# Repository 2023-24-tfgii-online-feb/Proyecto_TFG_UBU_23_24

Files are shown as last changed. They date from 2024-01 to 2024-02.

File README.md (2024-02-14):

# Diseño de un sistema económico IoT de monitorización de invernaderos de cannabis medicinal.

En este proyecto, se diseña e implementa un prototipo de sistema IoT de bajo coste que monitoriza la luminosidad, temperatura, humedad ambiente y humedad de suelo dentro del invernadero. Este sistema permite ajustar de manera precisa estas condiciones, fundamentales para el desarrollo saludable de las plantas de cannabis. Además, se propone una solución económica y eficiente para que el cultivador monitoree el estado del invernadero de forma remota, utilizando el bot de telegram o la aplicación de escritorio para windows. Con el dashboard web se podrá monitorizar en tiempo real, desde cualquier lugar y dispositivo los valores de los sensores, viendo una gráfica en tiempo real, y con un histórico de datos que podremos consultar.

# Descripción del Proyecto.

El objetivo de este proyecto es utilizar una Raspberry Pi Pico w para obtener mediciones del ambiente y mostrarlas en una pantalla OLED y también en una plataforma web.

El programa ejecuta las siguientes tareas:

* Se inicializan los sensores DHT22 (temperatura y humedad), BH1750 (intensidad de luz) y el sensor de humedad del suelo.
* Obtener las lecturas de los sensores.
* Mostrar los datos en la pantalla OLED.
* Cada intervalo de tiempo se envia a servidor LAMP (por MQtt) los datos obtenidos, se muestran y se guardan en base de datos mySQL.
* Avisa de valores fuera del umbral esperado / ideal, ya sea con leds RGB luminosos (valor bajo azul, valor alto rojo) o avisos por telegram.
* Esperar el próximo intervalo de actualización.
* Desde el bot de telegram se pueden hacer consultas para que nos devuelva el valor del valor del sensor que hayamos elegido, también podremos activar mecanismos para solventar valores fuera de los umbrales, como riego, ventilación, calefacción, focos luminosos... (en este caso se enciende un led verde, pero lo comentado se podría implementar).

# Comprobación de calidad de código del repositorio.

Mediante la herramienta online sonarcloud.io se ha analizado la calidad del código, y siguiendo varios consejos se ha actualizado para optimizarlo.  

**Status**: Passed.  
https://sonarcloud.io/project/overview?id=JLCaballeroMQ_Proyecto_TFG_UBU_23_24

# Subidos 3 videos a youtube con explicación y comprobación del funcionamiento.

1. https://youtu.be/VwgxjhJzbKk
2. https://youtu.be/c7tfhW0rUnw
3. https://youtu.be/uWBjEbmtJAI

# Acceso online al dashboard.

http://www.inveriot.com

# Umbrales ideales. 

## Usados en las pruebas (interior de casa).

|Característica | Rango |
|---|---|
|Temperatura | 30°C - 35°C|
|Humedad Ambiente | 30% - 70%|
|Luminosidad | 30 Lux - 150 Lux|
|Humedad del Suelo | 20% - 80%|

## Reales.

El crecimiento de cannabis medicinal pasa por varias fases de crecimiento, los cuales cada uno tendrá unos valores óptimos diferentes, tomando una media se llega a los valores ideales reales. A parte de estos 4 valores, hay otros factores que dependen del crecimiento.<br />

|Característica | Rango |
|---|---|
|Temperatura | 18°C - 26°C|
|Humedad Ambiente (relativa)| 40% - 70%|
|Luminosidad| 5.000 Lux - 10.000 Lux|
|Humedad del Suelo| 40% - 60%|

## Vídeo Presentación y descripción del TFG.

https://youtu.be/2MzWXyzCgfI

## Vídeo demostración funcional.

https://youtu.be/933bV_MJztE

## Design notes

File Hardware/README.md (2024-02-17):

# Componenes Utilizados

* [Raspberry Pi Pico W, placa microcontroladora con capacidad WiFi.](img/picow-pinout.png)
* [Sensor de temperatura y humedad (DHT22).](img/DHT22.png)
* [Sensor de intensidad de luz (BH1750).](img/BH1750.png)
* [Sensor de humedad del suelo.](img/Sensor_humedad_suelo.png)
* [Leds RGB.](img/leds_rgb.png)
* [Pantalla OLED (128x64 píxeles).](img/oled.png)

# Diagrama de Conexión

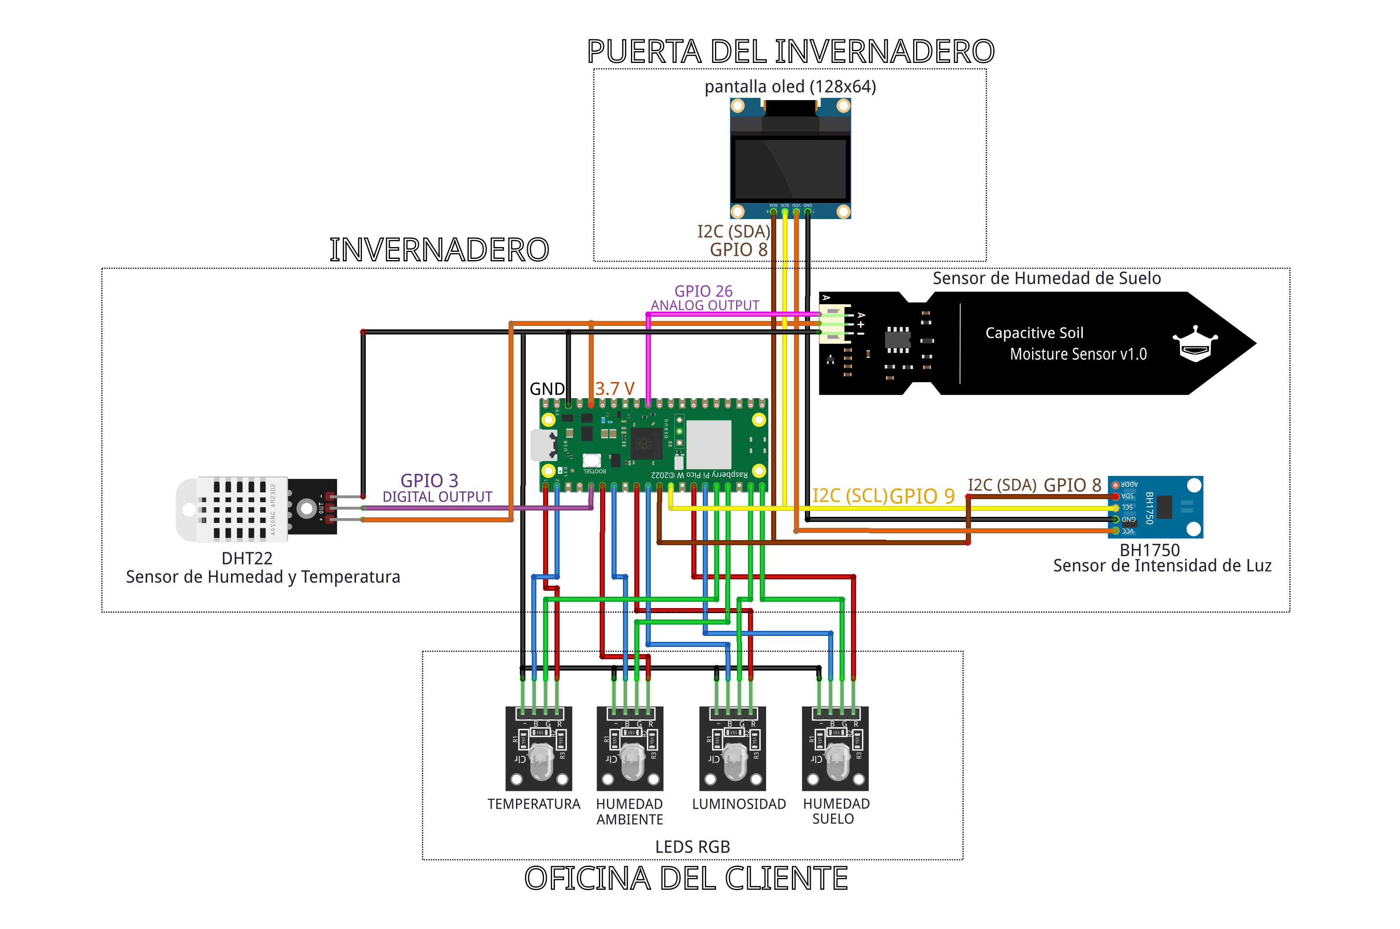
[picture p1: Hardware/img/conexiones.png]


## El código que contiene la placa Raspberry Pi Pico W

La carpeta "cdg_Raspberry" es justo el código que está dentro del dispositivo hardware Raspberry Pi Pico W, con él se han realizado las pruebas, vídeos y demás.

## Carpeta Firmware y reset

Esta carpeta contiene los archivos necesarios para poder resetear a los valores de fábrica la placa Raspberry, y otro archivo para ejecutarlo después para actualizar firmware y que pueda trabajar con microPython.

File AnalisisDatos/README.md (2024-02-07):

# Análisis de datos

## Diccionario de datos

| Columna|Descripción|Tipo de Datos|Unidades|
|---|---|---|---|
| temperatura	| Temperatura del ambiente | Número decimal | $\textcelsius$|
|humedad|Humedad relativa del ambiente (HR)|Número decimal| %|
|intensidad_luz|Intensidad de luz|Número decimal|lux|
|humedad_suelo|Humedad del suelo|Número decimal|%|

## Estructura de los datos

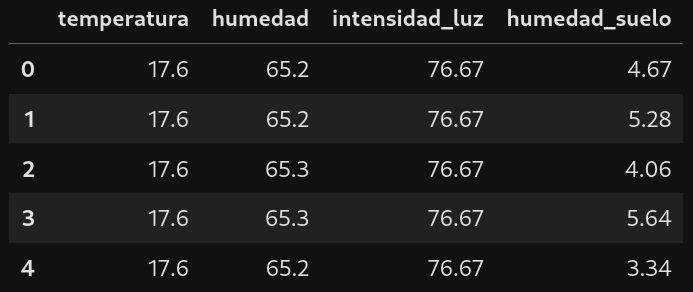
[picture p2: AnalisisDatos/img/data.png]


## Resumen estadístico

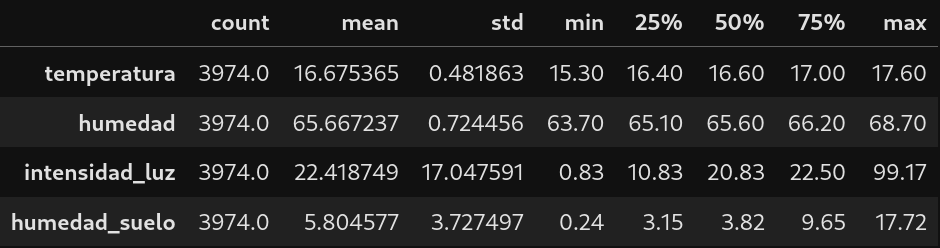
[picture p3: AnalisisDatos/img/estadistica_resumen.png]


## Diagrama de dispersión por pares

* Permite comparar las relaciones entre diferentes pares de variables.  
* Las nubes densas nos indican una fuerte relación entre variables.  
* Si se observara una nube lineal, indicaría una relación positiva o negativa.  
* Se observa una relación lineal entre las variables **humedad** y **temperatura**.

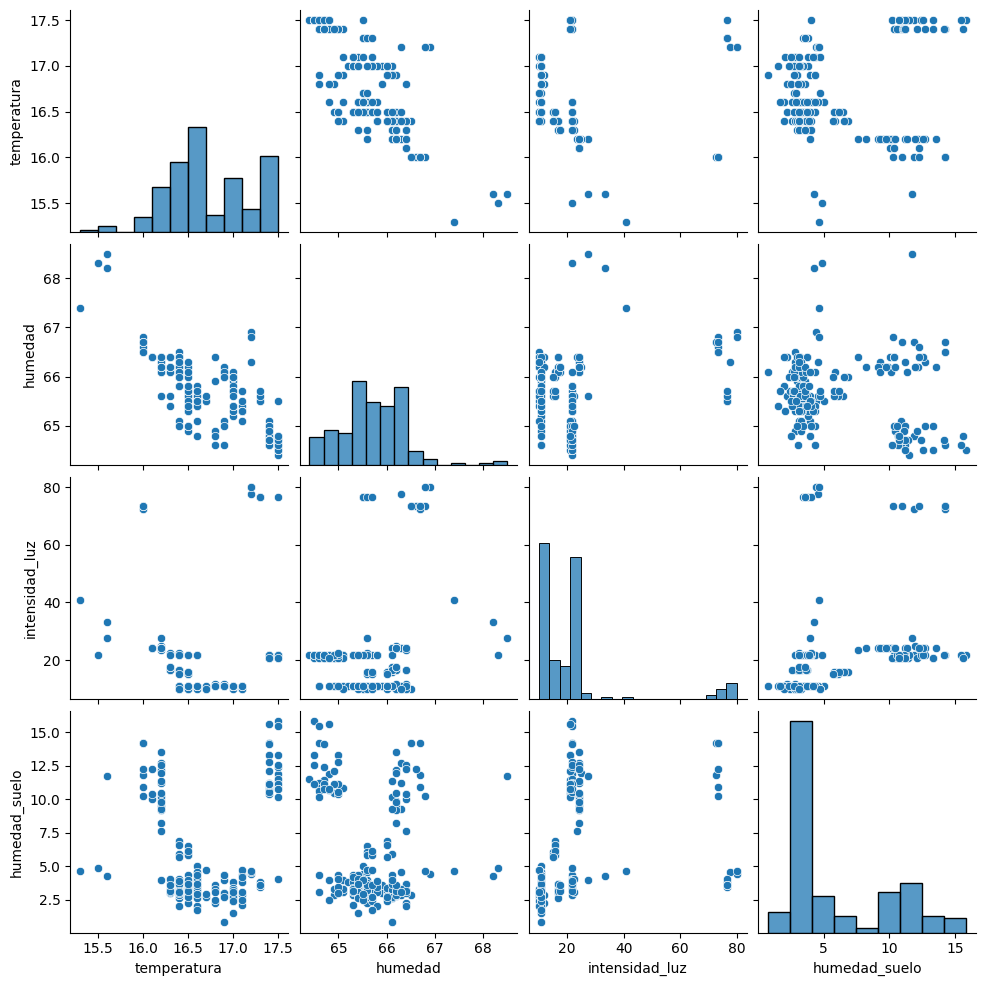
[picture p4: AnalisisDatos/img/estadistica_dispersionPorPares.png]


## Correlación entre variables

* Este gráfico nos permite ver de forma visual la correlación entre los atributos.  
* El amarilo alrededor de la diagonal sugiere que los atributos que están uno al lado del otro generalmente están más correlacionados entre sí. 
* Una buena práctica es tomar el valor de 0.7 o -0.7 entre dos atributos o variables para decir que tienen una fuerte correlación o relación.  
* Las variables **humedad** y **temperatura** tienen una fuerte correlación.

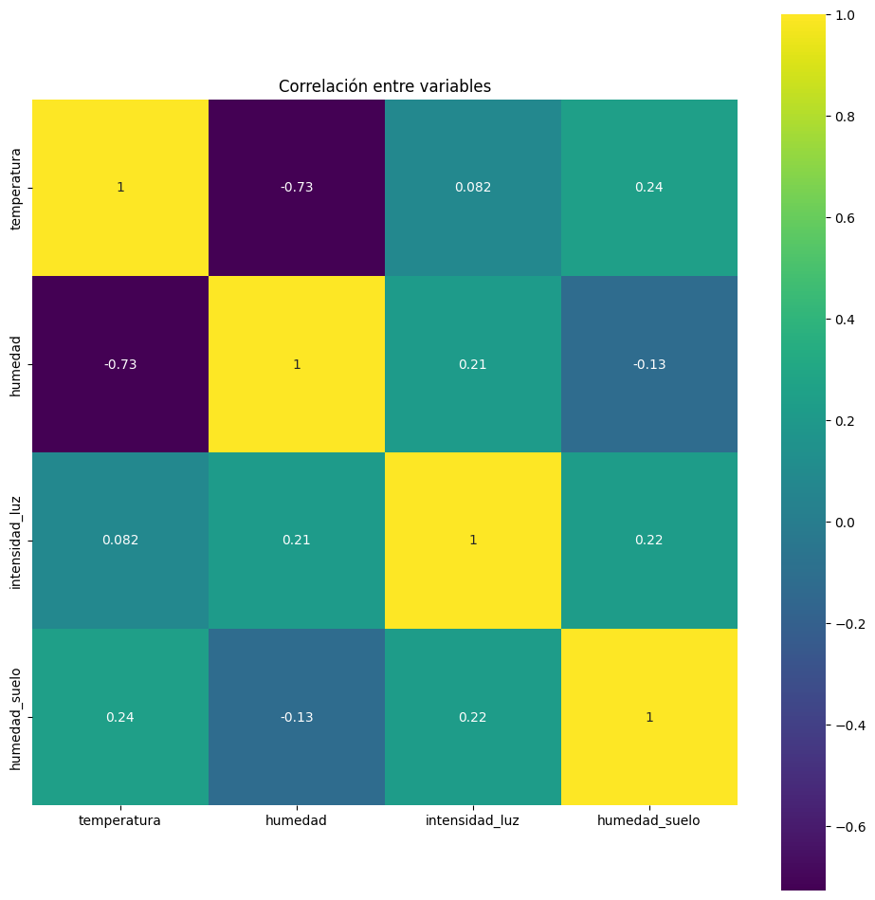
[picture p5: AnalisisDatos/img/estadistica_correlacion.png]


## Regresión lineal

* Esta es la regresión lineal entre las variables: **temperatura** y **humedad**.  
* $R^2$=0.537 (Factor de determinación). El 53.7% de la variabilidad en la variable dependiente (temperatura) puede explicarse por el modelo de regresión lineal. Representa una capacidad predictiva moderada.  
* La ecuación es: $y=-0.48x + 48.24$
* La capacidad predictiva moderada y la dispersión de los datos indican poca fiabilidad para predecir mediante una regresión lineal.

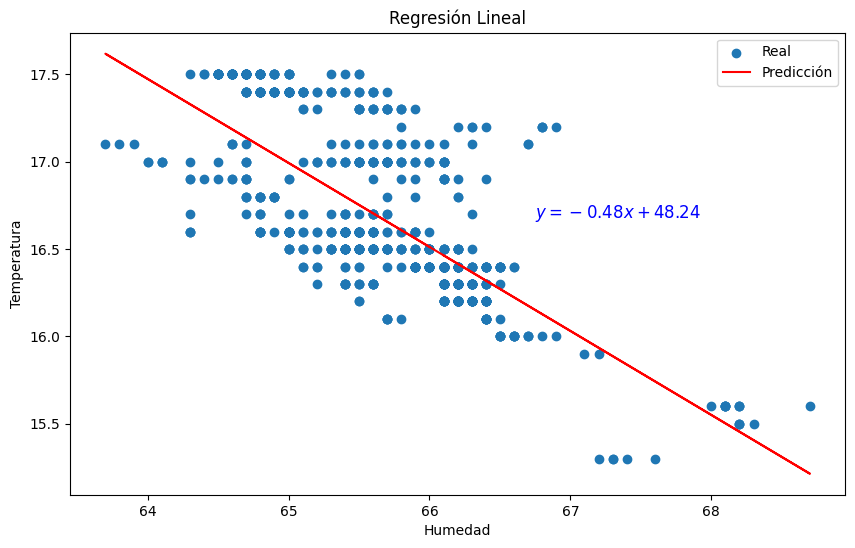
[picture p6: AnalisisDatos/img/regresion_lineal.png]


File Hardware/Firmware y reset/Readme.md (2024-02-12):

Subido archivo para resetear la Raspberry Pi Pico W y para reconfigurarlo para trabajar con micropython.
Descargados de:

https://micropython.org/download/RPI_PICO_W/

https://electrocredible.com/how-to-reset-raspberry-pi-pico-w/

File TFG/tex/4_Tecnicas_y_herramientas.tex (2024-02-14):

\capitulo{4}{Técnicas y herramientas}

A lo largo del desarrollo del proyecto, se han empleado diversas tecnologías, herramientas y elementos esenciales que requieren familiaridad antes de avanzar en la ejecución del proyecto. La elección de estas opciones en lugar de otras se basa en una evaluación detallada, la cual queda documentada en esta sección con el propósito de brindar una justificación fundamentada.

\section{Entorno Software}
\subsection{Entorno de desarrollo Micropython}\label{4:MicroPython}
%Thonny~\cite{misc:Thonny} 
\begin{itemize}
	\item \textbf{Herramientas valoradas:} \href{https://thonny.org/}{Thonny IDE}, \href{https://codewith.mu/}{Mu Editor}, \href{https://dfrobot.gitbooks.io/upycraft/content/}{Upycraft}, \href{https://www.jetbrains.com/pycharm/}{PyCharm}.
    \item \textbf{Herramienta elegida:} \href{https://thonny.org/}{Thonny IDE}.
\end{itemize}

\subsection{Entorno de desarrollo Python}\label{4:Python}
\begin{itemize}
	\item \textbf{Herramientas valoradas:} \href{https://colab.google/}{Google colab}, \href{https://jupyter.org/}{Jupyter Notebook} y \href{https://www.spyder-ide.org/}{Spiyder}.
    \item \textbf{Herramienta elegida:} \href{https://jupyter.org/}{Jupyter Notebook}.
\end{itemize}

\section{Control de datos}
\subsection{APIS}\label{4:APIS}
\begin{itemize}
    \item \textbf{API de Telegram:}
La API de Telegram~\cite{misc:Telegram_api}, accesible a través de la URL \url{https://api.telegram.org/bot<token>}, juega un papel fundamental en la integración de bots de Telegram~\cite{misc:Telegram_bots} con el sistema. Permite la interacción bidireccional entre el sistema y los usuarios a través de la plataforma de mensajería Telegram. Al utilizar esta API, se establece una conexión segura para enviar y recibir mensajes, comandos y datos entre el sistema y los usuarios mediante la implementación de funciones específicas proporcionadas por Telegram. Esto posibilita la notificación remota, la recopilación de datos y la activación de acciones automatizadas, contribuyendo así a la funcionalidad integral del sistema de control de datos.
Esta API fue usada en el código MicroPython.
    \item \textbf{API WorldTime}\label{4:API_Hora}
		La API de WorldTime~\cite{misc:WorlTimeAPI}, accesible mediante la URL \url{http://worldtimeapi.org/api/ip}, ofrece información precisa sobre la hora mundial basada en la ubicación asociada a la dirección IP del usuario. Al realizar una solicitud a esta API, se obtiene información detallada sobre la hora actual, la fecha, el huso horario y otros datos relacionados con la hora en la ubicación correspondiente a la dirección IP consultada. Esta API es valiosa para aplicaciones que requieren sincronización horaria precisa y la visualización de la hora actual en diferentes regiones del mundo. Su facilidad de acceso y respuesta estructurada la convierten en una herramienta útil para integrar la información horaria global en aplicaciones y sistemas.
Esta API fue usada en el código MicroPython.
\end{itemize}
\pagebreak

\section{Entorno Hardware}
\subsection{Fritzing}
Fritzing~\cite{misc:Fritzing} es una herramienta de diseño electrónico de código abierto que facilita la creación de esquemas, prototipos y layouts de placas de circuito impreso (PCB). Diseñado para usuarios, desde principiantes hasta expertos, Fritzing ofrece una interfaz intuitiva y gráfica que permite la conexión visual de componentes electrónicos, como sensores, actuadores y placas de desarrollo. Su funcionalidad principal abarca desde la creación de esquemas eléctricos hasta la generación de archivos Gerber para la fabricación de PCB. Fritzing se destaca por su accesibilidad y capacidad para convertir conceptos de diseño en proyectos electrónicos tangibles, lo que lo convierte en una herramienta valiosa para ingenieros, diseñadores y entusiastas que desean visualizar y materializar sus ideas electrónicas.
\begin{figure}[h]
    \centering
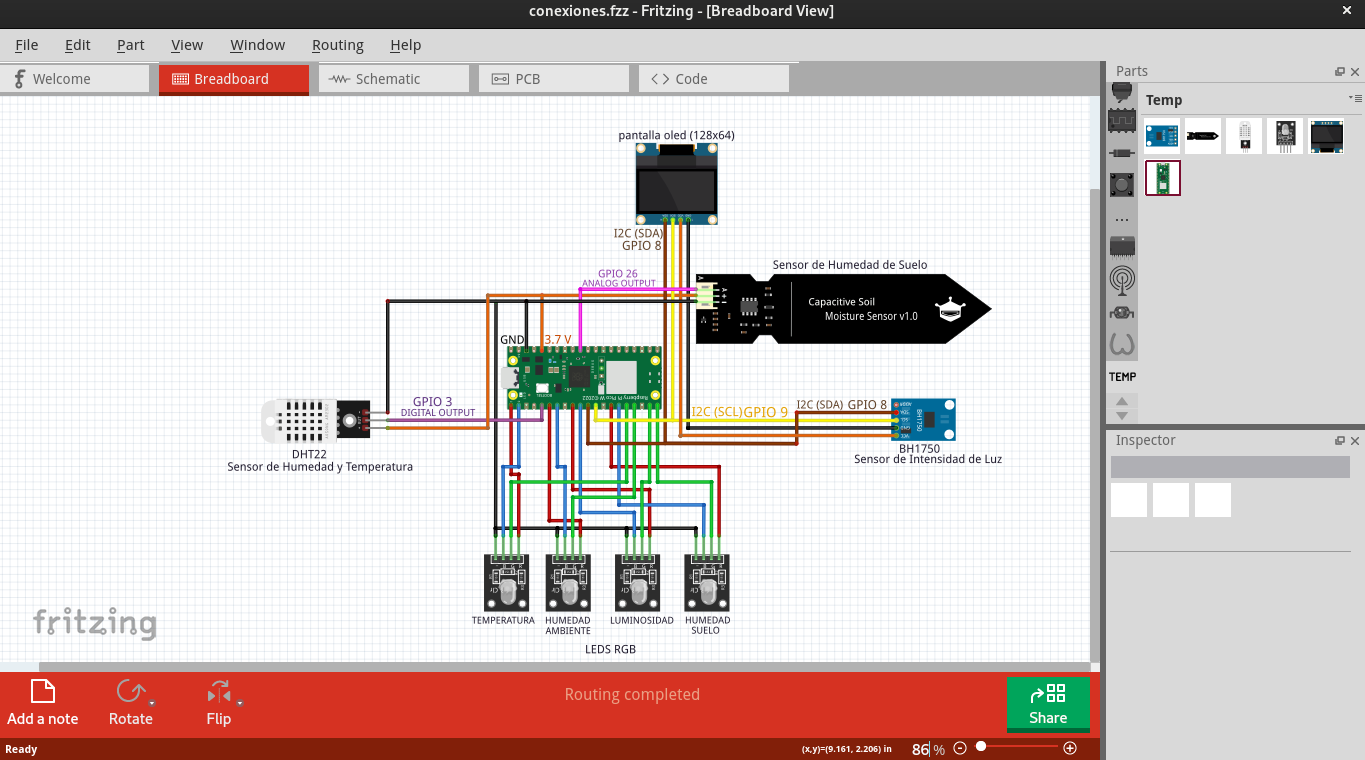
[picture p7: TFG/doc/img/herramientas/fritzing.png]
    
    \caption{Esquema de conexiones diseñado con Fritzing.}
\end{figure}
\pagebreak

\section{Metodologías}
\subsection{Modelo de prototipos}
El modelo de prototipos~\cite{misc:Metodologia_ModeloDePrototipos} es una metodología de desarrollo de software que se centra en la creación temprana y rápida de versiones simplificadas de un sistema para obtener retroalimentación y comprensión de los requisitos del usuario. En lugar de esperar hasta la fase final del desarrollo para presentar un producto completo, el enfoque de prototipos permite construir versiones iterativas y evolutivas del sistema.

El proceso típico del modelo de prototipos implica las siguientes etapas:
\begin{itemize}
	\item \textbf{Requisitos de desarrollo:}
Se identifican y documentan los requisitos iniciales del sistema.

\item \textbf{Desarrollo del Prototipo:}
Se construye un prototipo inicial que representa visualmente las funcionalidades clave del sistema.

\item \textbf{Evaluación del prototipo:}
Los usuarios y las partes interesadas evalúan el prototipo y proporcionan retroalimentación sobre su diseño y funcionalidad.

\item \textbf{Modificación:}
Con base en la retroalimentación recibida, se realizan ajustes y modificaciones en el prototipo para mejorar su rendimiento y cumplir con los requisito

\item \textbf{Documentación:}
Se documentan los cambios realizados y se actualiza la documentación del sistema para reflejar el estado actual del prototipo.

\item \textbf{Pruebas:}
Se llevan a cabo pruebas exhaustivas para asegurar que el prototipo modificado cumple con los requisitos y funcionalidades especificados.
\end{itemize}

Este enfoque iterativo y colaborativo permite una mayor flexibilidad en la adaptación a cambios en los requisitos del usuario y facilita la comunicación entre los desarrolladores y los stakeholders. El modelo de prototipos es particularmente útil en situaciones donde los requisitos no están completamente claros desde el principio o cuando se busca una comprensión más profunda de las necesidades del usuario antes de la implementación final del sistema.

\subsection{Metodología cascada}
La metodología cascada~\cite{misc:Metodologia_Cascada}, también conocida como el modelo de desarrollo en cascada, es una metodología de desarrollo de software que sigue un enfoque lineal y secuencial. Aunque ha sido utilizada en proyectos de software en el pasado, en la actualidad se considera menos flexible y adaptable en comparación con metodologías más modernas y ágiles.
En el modelo cascada, el proceso de desarrollo sigue una secuencia fija de fases, que generalmente incluyen:

\begin{enumerate}
\item Requisitos
\item Diseño
\item Implementación
\item Pruebas
\item Despliegue
\item Mantenimiento
\end{enumerate}

Cada fase depende de la finalización exitosa de la fase anterior, y los cambios en las etapas posteriores pueden ser difíciles y costosos de implementar una vez que el proyecto ha avanzado. Este enfoque puede no ser el más adecuado para proyectos donde los requisitos pueden cambiar con frecuencia o donde la adaptabilidad es esencial.

En muchos proyectos actuales, especialmente en el ámbito académico, se prefiere el uso de metodologías más ágiles y flexibles, como Scrum, Kanban o el enfoque de desarrollo iterativo e incremental.

En conclusión, aunque la metodología cascada ha sido utilizada en el pasado, hoy en día muchas organizaciones y proyectos prefieren metodologías más ágiles y adaptables. La elección de la metodología dependerá de los requisitos y características específicas de cada proyecto de TFG.

\begin{itemize}
	\item \textbf{Herramienta elegida:} Metodología cascada.
\end{itemize}

\section{Entorno de desarrollo del Proyecto}
\subsection{Control de versiones o CVS, Concurrent Versioning System}\label{4:controlVersiones}
\begin{itemize}
    \item \textbf{Herramientas valoradas:} \href{https://git-scm.com/}{Git}, \href{https://subversion.apache.org/}{SVN}.
    \item \textbf{Herramienta elegida:} \href{https://git-scm.com/}{Git}.
\end{itemize}
Git~\cite{misc:Git} es un sistema de control de versiones distribuido, ampliamente utilizado en el desarrollo de software y es conocido por su velocidad, flexibilidad y eficiencia en la gestión de versiones de código fuente.

Comparación con SVN:

Subversion (SVN)~\cite{misc:SVN} es otro sistema de control de versiones, pero sigue un modelo centralizado, a diferencia del modelo distribuido de Git. Aquí hay algunas diferencias clave y ventajas de Git sobre SVN:
\begin{itemize}
	\item \textbf{Descentralización:}
Git es completamente descentralizado, lo que significa que cada usuario tiene una copia completa del repositorio con todo su historial. En SVN, los usuarios dependen del servidor central para muchas operaciones.

\item \textbf{Ramificación y Fusiones Rápidas:}
Git permite ramificaciones ligeras y fusiones rápidas, lo que facilita el desarrollo paralelo y la gestión de características en diferentes ramas. SVN maneja ramificaciones y fusiones, pero históricamente ha sido menos eficiente en comparación con Git.

\item \textbf{Eficiencia en Red:}
Git es más eficiente en términos de ancho de banda y operaciones de red, ya que las operaciones se realizan localmente en la mayoría de los casos. SVN, al depender más del servidor central, puede ser más lento en operaciones que implican la red.

\item \textbf{Historial Completo y Offline:}
Git almacena el historial completo localmente, lo que permite el trabajo fuera de línea. SVN requiere acceso al servidor para recuperar el historial completo.

\item \textbf{Flexibilidad y Escalabilidad:}
Git es conocido por su flexibilidad y escalabilidad, especialmente en proyectos grandes y complejos. SVN puede encontrar limitaciones en proyectos extensos y complejos.
\end{itemize}

\subsection{Hosting del Repositorio}
\begin{itemize}
    \item \textbf{Herramientas valoradas:} \href{https://github.com/}{Github} y \href{https://bitbucket.org/product/}{Bitbucket}.
    \item \textbf{Herramienta elegida:} \href{https://github.com/}{Github}.
\end{itemize}
GitHub~\cite{misc:Github} es una plataforma de desarrollo colaborativo basada en Git que facilita el alojamiento y la colaboración en proyectos de software. 

Bitbucket~\cite{misc:Bitbucket} es otra plataforma de desarrollo colaborativo basada en Git, pero hay algunas diferencias clave. Aquí se exploran estas diferencias y se destaca una ventaja de GitHub sobre Bitbucket:

\begin{itemize}
	\item \textbf{Visibilidad del Código Fuente:}
		GitHub ha sido históricamente más popular para proyectos de código abierto, y los repositorios públicos en GitHub suelen tener una mayor visibilidad y participación de la comunidad en comparación con Bitbucket.

\item \textbf{Comunidad y Desarrollo Abierto:}
GitHub se ha convertido en el estándar de facto para proyectos de código abierto, y muchos desarrolladores buscan activamente proyectos en GitHub. Esto hace que sea más fácil para los proyectos atraer colaboradores y contribuyentes.

\item \textbf{Integraciones y Ecosistema:}
Tiene una amplia gama de integraciones y herramientas de terceros que son ampliamente utilizadas en la comunidad de desarrollo. La rica integración con servicios como Travis CI, CircleCI y otros facilita el desarrollo y la automatización.

\item \textbf{Herramientas de Colaboración:}
Mientras que Bitbucket ofrece características similares, GitHub es generalmente preferido por su interfaz de usuario intuitiva, herramientas de revisión de código más robustas y una experiencia general más pulida para la colaboración.

\item \textbf{Repositorios Públicos Gratuitos:}
Permite la creación de repositorios públicos de forma gratuita, lo que fomenta la participación y el desarrollo colaborativo en proyectos de código abierto. Bitbucket, por otro lado, suele ofrecer repositorios privados gratuitos, pero limita la cantidad de colaboradores.
\end{itemize}

\subsection{Editor del proyecto}
\begin{itemize}
    \item \textbf{Herramientas valoradas:} \href{https://www.vim.org/}{VIM}, \href{https://code.visualstudio.com/}{Visual Studio Code}, \href{https://www.sublimetext.com/}{Sublime}.
    \item \textbf{Herramienta elegida:} \href{https://code.visualstudio.com/}{Visual Studio Code}.
\end{itemize}

Visual Studio Code (VSCode)~\cite{misc:vscode} se ha convertido en una opción popular entre los programadores, especialmente para principiantes. Aunque VIM y Sublime Text siguen siendo opciones sólidas, VSCode ofrece algunas ventajas:

\begin{itemize}
	\item \textbf{Facilidad de uso:} Tiene una interfaz gráfica intuitiva que facilita su uso, especialmente para quienes no están familiarizados con editores de texto basados en comandos como VIM.

	\item \textbf{Funciones integradas:} Viene con muchas funciones integradas, como resaltado de sintaxis, autocompletado, depuración y control de versiones. Esto reduce la necesidad de instalar y configurar plugins adicionales.

	\item \textbf{Gran ecosistema de plugins:} VSCode tiene un gran ecosistema de plugins gratuitos y de pago que amplían sus funcionalidades. Puedes encontrar plugins para casi cualquier cosa, desde soporte para lenguajes de programación específicos hasta herramientas de productividad.

	\item \textbf{Gratuito y de código abierto:} Es gratuito y de código abierto, lo que lo hace accesible a todos.

	\item \textbf{Actualizaciones frecuentes:} Se actualiza con frecuencia con nuevas funciones y correcciones de errores.

	\item \textbf{Soporte multiplataforma:} Está disponible para Windows, macOS y Linux.
\end{itemize}

He optado por Visual Studio Code en lugar de Sublime Text, ya que encuentro que ofrece una experiencia más completa. En cuanto a VIM, decidí descartarlo debido a la dificultad inicial de aprendizaje asociada con sus numerosos atajos de teclado para cada acción.

\subsection{Dibujos, diagramas y planos}\label{4:plataformasDibujosYPlanos}

\begin{itemize}
	\item \textbf{Herramientas valoradas:} \href{https://inkscape.org/}{Inkscape}, \href{https://www.gimp.org/}{GIMP}, \href{https://support.microsoft.com/es-es/windows/obtener-microsoft-paint-a6b9578c-ed1c-5b09-0699-4ed8115f9aa9}{Paint, Paint3D}, \href{https://www.adobe.com/es/products/photoshop.html}{Photoshop}, y \href{www.draw.io}{Draw.io}.
	\item \textbf{Herramienta elegida:} \href{https://www.gimp.org/}{GIMP} y \href{https://www.adobe.com/es/products/photoshop.html}{Photoshop}.
\end{itemize}

He elegido utilizar GIMP y Photoshop debido a mi familiaridad y experiencia con estas herramientas.

\subsection{Procesador de textos \LaTeX}\label{4:latex}
\begin{itemize}
    \item \textbf{Herramientas valoradas:} \href{https://www.latex-project.org/}{\LaTeX}, \href{https://www.microsoft.com/es-es/microsoft-365/word}{MS Word}, \href{https://www.sublimetext.com/}{Sublime}, \href{https://www.overleaf.com/}{Overleaf}.
    \item \textbf{Herramienta elegida:} \href{https://www.latex-project.org/}{\LaTeX} y \href{https://www.overleaf.com/}{Overleaf}.
\end{itemize}
\LaTeX{}~\cite{misc:Latex} es un sistema de preparación de documentos que se utiliza ampliamente para la creación de documentos científicos, técnicos y académicos. A diferencia de los procesadores de texto tradicionales, LaTeX se basa en la creación de documentos mediante instrucciones de marcado en lugar de formatos visuales directos. Los usuarios escriben el contenido del documento junto con comandos LaTeX que definen la estructura, el formato y otros elementos.

Overleaf~\cite{misc:Overleaf} es una plataforma en línea que permite la colaboración en tiempo real y la edición de documentos LaTeX. Algunas razones para considerar el uso de Overleaf junto con LaTeX son:
\begin{itemize}
	\item \textbf{Colaboración en Tiempo Real:}
Overleaf facilita la colaboración en documentos LaTeX entre múltiples autores en tiempo real, permitiendo que varios colaboradores trabajen simultáneamente en un proyecto.

\item \textbf{Entorno en Línea:}
No es necesario instalar LaTeX localmente en tu máquina. Overleaf proporciona un entorno en línea que elimina la necesidad de configurar y mantener un sistema LaTeX en tu computadora.

\item \textbf{Plantillas y Recursos:}
Overleaf ofrece una variedad de plantillas predefinidas para diferentes tipos de documentos, lo que facilita el inicio de nuevos proyectos. Además, proporciona acceso a una amplia variedad de recursos y tutoriales.

\item \textbf{Control de Versiones Integrado:}
Overleaf tiene un sistema de control de versiones integrado que permite realizar un seguimiento de los cambios en el documento y revertir a versiones anteriores si es necesario.

\item \textbf{Exportación y Publicación:}
Overleaf permite exportar documentos a diferentes formatos (PDF, HTML, etc.) y facilita la publicación directa en revistas académicas que admiten el formato LaTeX.
\end{itemize}
\pagebreak

\subsection{Calidad del Código}
\begin{itemize}
	\item \textbf{Herramientas valoradas:} \href{https://www.sonarsource.com/products/sonarcloud/}{SonarCloud}, \href{https://codebeat.co/}{Codebeat}, \href{https://www.codacy.com/}{Codacy} y \href{https://www.sonarsource.com/products/sonarqube/}{SonarQube}.
    \item \textbf{Herramienta elegida:} \href{https://www.sonarsource.com/products/sonarcloud/}{SonarCloud}.
\end{itemize}
SonarCloud~\cite{misc:SonarCloud}, elegido para optimizar la calidad del código en mi proyecto, realiza revisiones exhaustivas en la nube y ofrece valiosas sugerencias para mejorar. Su integración en tiempo real con GitHub asegura una evaluación continua y facilita la corrección de problemas de código de manera inmediata. 

\section{Entorno físico}
\subsection{Raspberry Pi Pico W}
La Raspberry Pi Pico W~\cite{manual:RPiPicoW_datasheet} es un microcontrolador de bajo costo y alto rendimiento desarrollado por la Fundación Raspberry Pi. Se basa en el chip RP2040 diseñado por Raspberry Pi, que integra un procesador ARM Cortex-M0+ de doble núcleo y ofrece una serie de características diseñadas para proyectos de electrónica y programación embebida.

\begin{table}[htbp]
\begin{center}
\caption{Características de la Raspberry Pi Pico W.}
\begin{tabular}{|l|l|}
\hline
\rowcolor[HTML]{C0C0C0} 
\textbf{Característica} & \textbf{Descripción}\\ \hline
Microcontroller	& RP2040 @ 133MHz, 264kB SRAM \\ \hline
Procesador & Dual Core ARM Cortex-M0+ \\ \hline
Flash memory &	2MB \\ \hline
Exposed GPIO & 26 \\ \hline
ADC	& 3 channels \\ \hline
I2C	& 2 \\ \hline
SPI	& 2 \\ \hline
UART & 2 \\ \hline
PWM	& 16 channels	 \\ \hline
Wireless interfaces & Wifi 802.11n, Bluetooth 5.2\\ \hline
\end{tabular}
\end{center}
\end{table}
\pagebreak

\begin{figure}[h]
    \centering
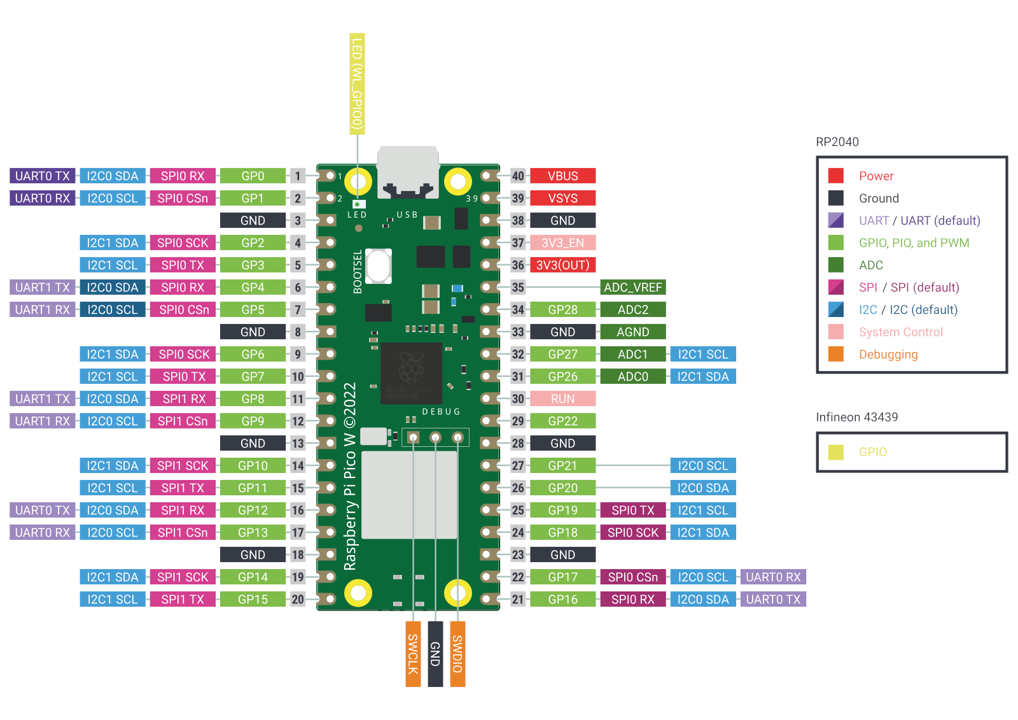
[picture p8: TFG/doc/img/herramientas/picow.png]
    
    \caption{Raspberry Pi Pico W Pinout.}
\end{figure}

\begin{figure}[h]
    \centering
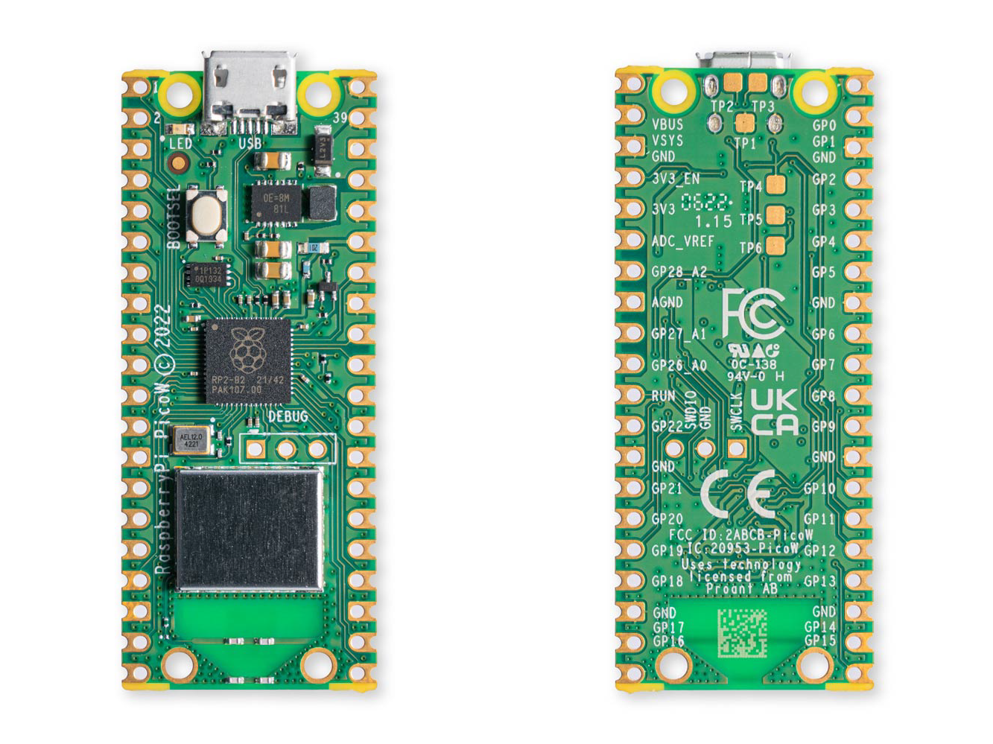
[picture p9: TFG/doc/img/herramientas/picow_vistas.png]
    
    \caption{Vistas Frontal y posterior de Raspberry Pi Pico W.}
\end{figure}

\pagebreak

\subsection{Pantalla oled I2C de 128x64 píxeles y 1.3 pulgadas}
La pantalla OLED~\cite{manual:Oled} de 128x64 de 1.3 pulgadas con interfaz I2C es un dispositivo de visualización que utiliza la tecnología OLED (Diodo Orgánico de Emisión de Luz) y se comunica a través del protocolo I2C (Inter-Integrated Circuit).

\begin{table}[htbp]
\begin{center}
\caption{Características de la pantalla oled}
\begin{tabular}{|l|l|}
\hline
\rowcolor[HTML]{C0C0C0} 
\textbf{Característica} & \textbf{Descripción}\\ \hline
Voltaje de operación & 3V\quad-\quad5.5 V DC\\ \hline
Interfaz & I2C\\ \hline
Resolución & 128\times64\\ \hline
Monócromo & píxeles blancos (fondo negro)\\ \hline
Ángulo de visión & 160^\circ \\ \hline
Área visicle (display) & 23$\times$11.5 mm\\ \hline
Consumo de energía ultra bajo & 0.08 W (cuando están encendidos todos los píxeles)\\ \hline
item Temperatura de trabajo & -30\textcelsius\quad -\quad70\textcelsius \\ \hline
item Dimensiones & 27\times 27$\times$4.1mm \\ \hline
item Peso & 5 gramos \\ \hline
\end{tabular}
\end{center}
\end{table}

\begin{figure}[h]
    \centering
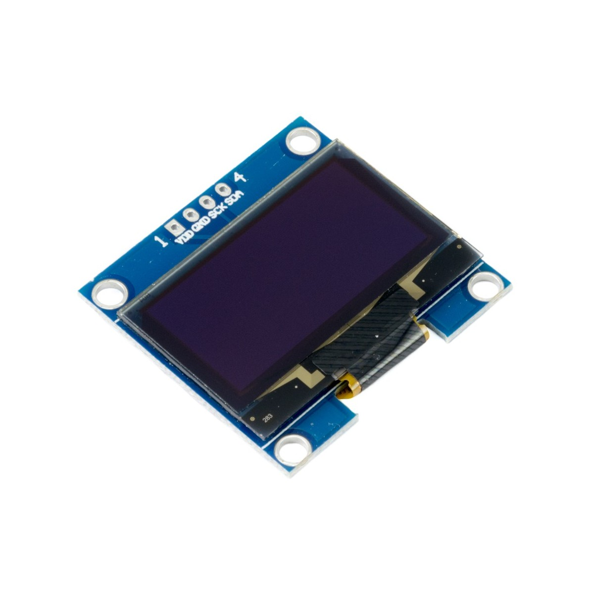
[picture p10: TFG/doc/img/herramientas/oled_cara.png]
    
    \caption{Pantalla oled.}
\end{figure}

%\begin{figure}[h]
    %\centering
    %\includegraphics[width=0.5\textwidth]{img/herramientas/oled_reverso.png}
    %\caption{Vista posterior de la pantalla oled.}
%\end{figure}

\subsection{Sensor de luz BH1750}

El sensor BH1750~\cite{manual:BH1750} es un sensor de intensidad de luz digital que mide la luminosidad ambiental en lux (lx). Este dispositivo es utilizado comúnmente en aplicaciones donde se requiere monitoreo de la luz, como en sistemas de iluminación automática, dispositivos de ahorro de energía y proyectos de IoT.
Posee un conversor interno de 16-bit, por lo que entrega una salida digital en formato I2C

\begin{table}[htbp]
\begin{center}
\caption{Características del sensor de luz BH1750.}
\begin{tabular}{|l|l|}
\hline
\rowcolor[HTML]{C0C0C0} 
\textbf{Característica} & \textbf{Descripción}\\ \hline
Voltaje de Operación &  3V – 5V \\ \hline
Interfaz digital & I2C \\ \hline
Respuesta espectral & similar a la del ojo humano \\ \hline
Rango de medición & 1 lux\quad-\quad65535 lux \\ \hline
Consumo de energía & bajo \\ \hline
\end{tabular}
\end{center}
\end{table}

\begin{figure}[h]
    \centering
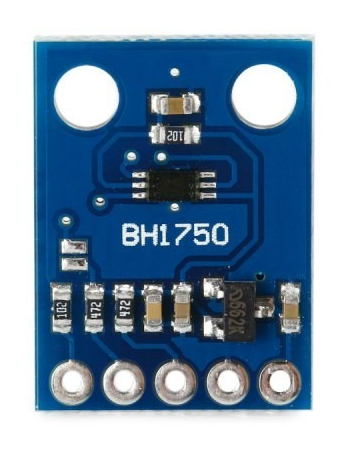
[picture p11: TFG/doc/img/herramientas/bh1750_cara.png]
    
    \caption{Vista frontal del sensor BH1750.}
\end{figure}

%\begin{figure}[h]
    %\centering
    %\includegraphics[width=0.4\textwidth]{img/herramientas/bh1750_reverso.png}
    %\caption{Lado posterior del sensor BH1750.}
%\end{figure}

\subsection{Sensor de temperatura y humedad DHT22}
El sensor DHT22~\cite{manual:DHT22} (también conocido como AM2302) es un sensor de temperatura y humedad digital utilizado en aplicaciones donde es crucial monitorear y medir las condiciones ambientales.

\begin{table}[htbp]
\begin{center}
\caption{Características del sensor de temperatura y humedad DHT22.}
\begin{tabular}{|l|l|}
\hline
\rowcolor[HTML]{C0C0C0} 
\textbf{Característica} & \textbf{Descripción}\\ \hline
Voltaje de funcionamiento &  3 V\quad-\quad 5.5 V \\ \hline
Forma de salida de señal & señal digital \\ \hline
Rango de medición de temperatura & -40 \textcelsius\quad -\quad 80 \textcelsius  \\ \hline
Rango de medición de humedad & 0\quad-\quad100\% HR \\ \hline
Resolución de temperatura & 0.1 \textcelsius \\ \hline
Resolución de humedad & 0.1\% HR \\ \hline
Precisión de medición de temperatura & $\pm$0.5 \textcelsius \\ \hline
Precisión de medición de humedad & \pm 2$\%$ $ HR$ \\ \hline
Tamaño & 28.2 x 13.1 x 10 mm \\ \hline
Tiempo de sensado & 2s \\ \hline
Modelo & AM2302 \\ \hline
\end{tabular}
\end{center}
\end{table}
\begin{figure}[h]
    \centering
    
    \caption{Sensor DHT22.}
\end{figure}

\subsection{Sensor de humedad de suelo}
El sensor de humedad de suelo Higrometro V1.2~\cite{wiki:SensorHumedadSuelo} es un dispositivo diseñado para medir la humedad del suelo en entornos agrícolas, de jardinería u otros contextos donde el control de la humedad del suelo es esencial.

\begin{table}[htbp]
\begin{center}
\caption{Características del sensor de humedad de suelo.}
\begin{tabular}{|l|l|}
\hline
\rowcolor[HTML]{C0C0C0} 
\textbf{Característica} & \textbf{Descripción}\\ \hline
Voltaje de alimentación & 3.3V\quad-\quad5V DC \\ \hline
Corriente operación & 5 mA \\ \hline
Voltaje de la señal de salida & 0 a 5V (Analógico) \\ \hline
Modelo & capacitive soil moisture sensor v1.2 \\ \hline
Vida útil & 3 años mínimo \\ \hline
Conector & PH2.0-3P \\ \hline
Dimensiones & 98$\times$23 mm \\ \hline
Peso & 15 gramos \\ \hline
\end{tabular}
\end{center}
\end{table}

\begin{figure}[h]
    \centering
    
    \caption{Sensor de humedad de suelo Higrometro V1.2.}
\end{figure}

\subsection{KY-016 FZ0455 Módulo led RGB de 3 colores}
El módulo KY-016~\cite{manual:LedRGB} FZ0455 es un dispositivo electrónico que contiene un LED RGB (Light Emitting Diode - Diodo Emisor de Luz) capaz de emitir luz en tres colores primarios: rojo, verde y azul. Este módulo se utiliza comúnmente en proyectos electrónicos y de iluminación para agregar efectos de luz y color controlables

\begin{table}[htbp]
\begin{center}
\caption{Características del módulo led RGB KY-016.}
\begin{tabular}{|l|l|} %|c|c|
\hline
\rowcolor[HTML]{C0C0C0} 
\textbf{Característica} & \textbf{Descripción}\\ \hline
Voltaje operativo & 3.3 V\quad5 V\\ \hline
Modo de accionamiento led & Accionamiento de cátodo común \\ \hline
Tamaño & 3.5$\times$0.8 cm\\ \hline
Voltaje de avance V_{f}[Red] & 1.8 V \\ \hline
Voltaje de avance V_{f}[Green, Blue] & 2.8 V \\ \hline
Corriente directa hacia adelante I_{f} & 20 mA \\ \hline
\end{tabular}
\end{center}
\end{table}

\begin{figure}[h]
    \centering
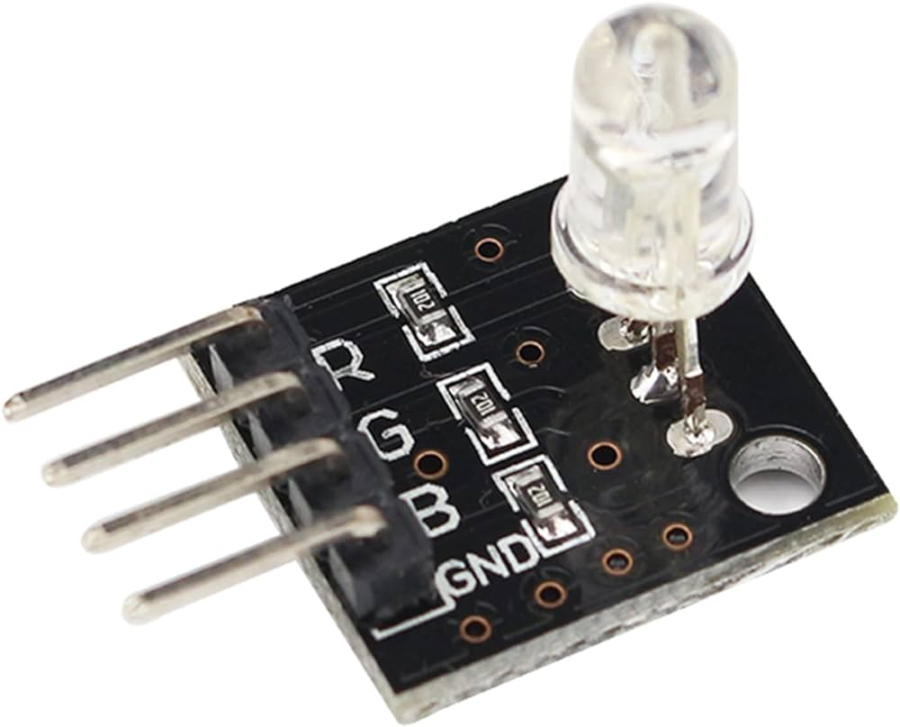
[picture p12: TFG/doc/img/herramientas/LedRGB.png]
    
    \caption{Módulo led RGB KY-016.} \label{Img:LedRGB}
\end{figure}

\subsection{Enrutador WiFi USB 4G LTE}
El Enrutador WiFi~\cite{misc:EnrutadorWifi} USB 4G LTE es un dispositivo portátil que permite establecer una conexión a Internet de alta velocidad utilizando la red móvil 4G LTE. Diseñado para la movilidad y la conveniencia, este router WiFi ofrece una solución eficiente para aquellos que requieren acceso a la red en cualquier lugar donde haya cobertura de red móvil. Con una ranura para tarjeta SIM, el dispositivo facilita la inserción de una tarjeta SIM compatible, lo que lo convierte en una opción versátil para la conectividad a Internet en movimiento. Con una velocidad de transferencia de hasta 150 Mbps, este enrutador proporciona un rendimiento adecuado para actividades en línea como navegación web, transmisión de video y juegos en línea.

\begin{table}[htbp]
\begin{center}
\caption{Características del enrutador WiFi USB 4G LTE.}
\begin{tabular}{|l|l|}
\hline
\rowcolor[HTML]{C0C0C0} 
\textbf{Característica} & \textbf{Descripción}\\ \hline
Velocidad de Transferencia &  Hasta 150 Mbps\\ \hline
Red Móvil Compatible &  Tecnología 4G LTE \\ \hline
4G LTE FDD & B1/B3/B5 \\ \hline
Wifi & Support IEEE802.11b/g/n Band 2.4G \\ \hline
Número máximo de usuarios & 10 \\ \hline
Ranura para Tarjeta SIM &  Necesario para la conexión a la red móvil \\ \hline
Conectividad WiFi & Proporciona una red WiFi local\\ \hline
Compatibilidad & Computadoras, tabletas y teléfonos \\ \hline
Seguridad & Cifrado WPA/WPA2 \\ \hline
Alimentación por batería & Es opcional y permite mayor portabilidad \\ \hline
Indicadores LED & Estado de la conexión e intensidad de la señal \\ \hline
Material & ABS \\ \hline
Dimensiones & 4.33$\times$2.76$\times$0.79 pulgadas\\ \hline
\end{tabular}
\end{center}
\end{table}

\begin{figure}[h]
    \centering
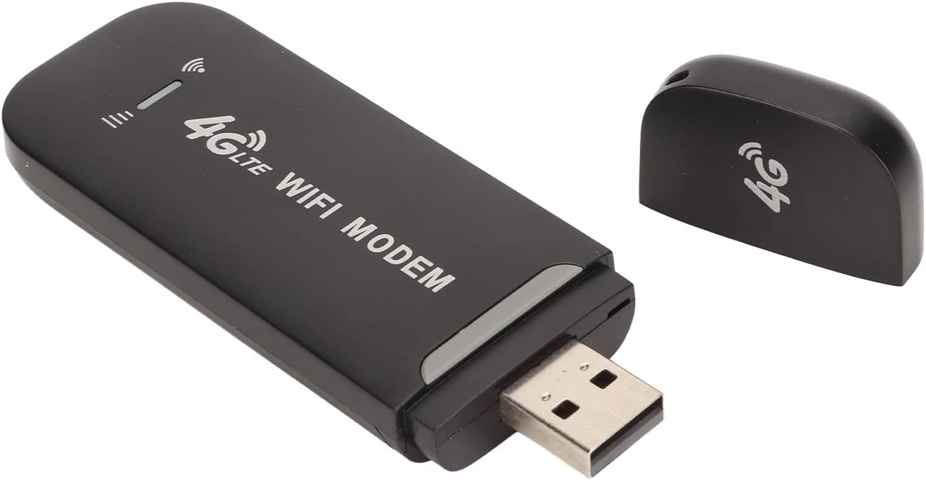
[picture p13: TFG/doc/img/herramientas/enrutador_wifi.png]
    
    \caption{Enrutador WiFi USB 4G LTE.} \label{Img:EnrutadorWifi}
\end{figure}

\subsection{Batería externa 20000 mAh}
Es un Power Bank~\cite{misc:Powerbank} portátil diseñado para cargar dispositivos móviles de forma rápida y eficiente. Con dos salidas USB-A y una entrada Type-C, proporciona flexibilidad para cargar múltiples dispositivos simultáneamente y recargarse fácilmente. Fabricada con aleación de aluminio, esta mini Powerbank, en elegante color gris, ofrece durabilidad y un diseño compacto que facilita su transporte. Con una capacidad de 20000mAh, es ideal para mantener tus dispositivos cargados mientras estás en movimiento, ya sea en viajes, actividades al aire libre o situaciones de emergencia.

\begin{table}[htbp]
\begin{center}
\caption{Características de la batería externa 20000 mAh.}
\begin{tabular}{|l|l|}
\hline
\rowcolor[HTML]{C0C0C0} 
\textbf{Característica} & \textbf{Descripción}\\ \hline
Tipo de conector entrada & usb tipo C (5V/2A)\\ \hline
Tipo de conector salida & usb tipo A2 (5V/2A)\\ \hline
Marca & YWTESCH \\ \hline
Color & Gris \\ \hline
Tensión & 5 voltios \\ \hline
Amperaje & 2 A \\ \hline
Capacidad máxima & 20000 mAh \\ \hline
Número de puertos & 2 \\ \hline
tamaño & 108$\times$69$\times$26 mm \\ \hline
\end{tabular}
\end{center}
\end{table}

\begin{figure}[h]
    \centering
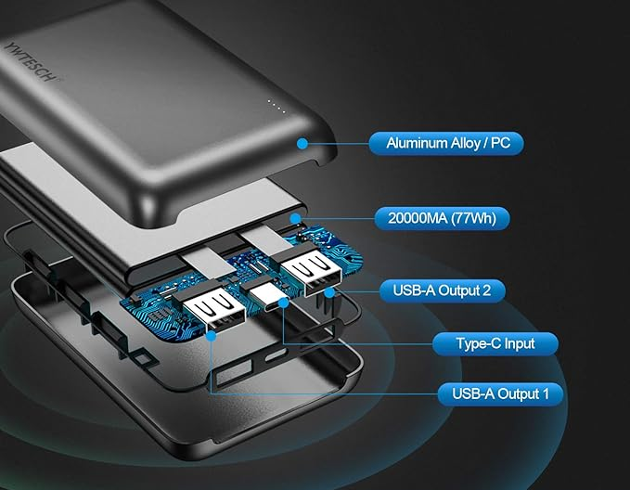
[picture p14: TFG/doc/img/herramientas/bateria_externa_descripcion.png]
    
    \caption{Batería externa 20000 mAh.} \label{Img:BateriaExterna}
\end{figure}

\subsection{Panel solar IP65 de 8W y 5V con cargador USB tipo C}
Este Panel Solar~\cite{misc:PanelSolar} es una solución eficiente para la carga de dispositivos móviles utilizando energía solar. Es una opción versátil para cargar dispositivos compatibles, como teléfonos, tabletas y otros dispositivos alimentados por USB. Compacto y fácil de transportar, es ideal para actividades al aire libre, viajes y situaciones donde la carga convencional no está disponible.

\begin{table}[htbp]
\begin{center}
\caption{Características del panel solar.}
\begin{tabular}{|l|l|} %|c|c|
\hline
\rowcolor[HTML]{C0C0C0} 
\textbf{Característica} & \textbf{Descripción}\\ \hline
USB & Tipo C con cable de 3 m \\ \hline
Capacidad & 8W y 5V \\ \hline
Material del panel & Silicio monocristalino \\ \hline
Vida útil & 20 años \\ \hline
Accesorios & Soporte ajustable 360$^\circ$ con tornillos y tojinos \\ \hline
Dimensiones & 23$\times$18.5$\times$1 cm\\ \hline
Tipo de protección & IP65 (resistente al polvo y agua)\\ \hline
\end{tabular}
\end{center}
\end{table}

\begin{figure}[h]
    \centering
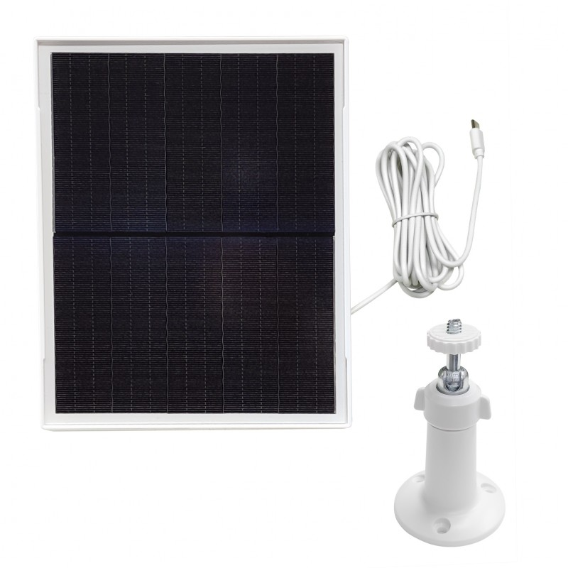
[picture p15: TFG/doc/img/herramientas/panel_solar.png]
    
    \caption{Panel solar y soporte ajustable.} \label{Img:PanelSolar}
\end{figure}

%Esta parte de la memoria tiene como objetivo presentar las técnicas metodológicas y las herramientas de desarrollo que se han utilizado para llevar a cabo el proyecto. Si se han estudiado diferentes alternativas de metodologías, herramientas, bibliotecas se puede hacer un resumen de los aspectos más destacados de cada alternativa, incluyendo comparativas entre las distintas opciones y una justificación de las elecciones realizadas. 
%No se pretende que este apartado se convierta en un capítulo de un libro dedicado a cada una de las alternativas, sino comentar los aspectos más destacados de cada opción, con un repaso somero a los fundamentos esenciales y referencias bibliográficas para que el lector pueda ampliar su conocimiento sobre el tema.

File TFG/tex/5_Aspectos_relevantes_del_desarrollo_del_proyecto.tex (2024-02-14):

\capitulo{5}{Aspectos relevantes del desarrollo del proyecto}

En esta sección, se destacarán los elementos más significativos del desarrollo, proporcionando una perspectiva detallada de las decisiones adoptadas para alcanzar los objetivos del proyecto. Se resumirá la experiencia práctica, detallando cómo se abordaron los desafíos específicos, y se evaluará la importancia de estas soluciones en el contexto general del alcance del proyecto.

\section{Motivación del proyecto}

La motivación subyacente a este proyecto surge de la creciente importancia y demanda en el ámbito de la monitorización de invernaderos, especialmente en el contexto del cultivo de cannabis medicinal. La necesidad de implementar soluciones tecnológicas eficientes para garantizar condiciones óptimas de cultivo y maximizar la producción ha impulsado la elección de este tema.

El objetivo principal radica en diseñar un sistema económico y eficaz que permita a los cultivadores de cannabis medicinal supervisar las condiciones ambientales de sus invernaderos de manera remota. Este proyecto busca proporcionar una herramienta valiosa para mejorar la eficiencia, la calidad y la consistencia en la producción de cannabis medicinal, al tiempo que se abordan los desafíos específicos asociados con la monitorización de variables críticas como temperatura, humedad y luz.

\section{Formación necesaria}

El proyecto ha requerido una formación interdisciplinaria que abarca diversas áreas. En primer lugar, la comprensión profunda de los principios de la programación y el desarrollo de software ha sido esencial. La elección de la Raspberry Pi Pico W como plataforma y la programación en MicroPython para controlar los dispositivos hardware involucra un conocimiento sólido en programación embebida y desarrollo en entornos limitados.

Además, la utilización de sensores especializados, como el DHT22~\cite{manual:DHT22}, el BH1750~\cite{manual:BH1750} y el sensor de humedad del suelo~\cite{wiki:SensorHumedadSuelo}, ha demandado una comprensión detallada de los principios de operación de estos dispositivos y cómo integrar sus lecturas en el sistema general. Esto implica una formación técnica en electrónica y sensores.

La implementación de conceptos relacionados con el Internet de las cosas (IoT) y la comunicación inalámbrica mediante la Raspberry Pi Pico W~\cite{misc:RPiPicoW} también ha requerido conocimientos específicos en redes y protocolos de comunicación.

La integración de MQTT~\cite{manual:MQTT} en el código MicroPython para la Raspberry Pi Pico W ha requerido conocimientos específicos sobre este protocolo de mensajería ligero diseñado para la eficiente comunicación entre dispositivos en redes IoT.

En resumen, la formación necesaria abarca habilidades en programación embebida, electrónica, redes, IoT y desarrollo de software. La combinación de estas competencias ha sido esencial para la ejecución exitosa del proyecto, demostrando la importancia de una formación integral y multidisciplinaria en el ámbito de la ingeniería y la tecnología.

\section{Metodología}
Se ha optado por la metodología del \textbf{Modelo de Prototipos}~\cite{misc:Metodologia_ModeloDePrototipos} debido a su capacidad para proporcionar retroalimentación temprana, clarificar requisitos, adaptarse a cambios, validar prácticamente funcionalidades, reducir riesgos, comprender la interfaz de usuario y facilitar la mejora continua. Este enfoque iterativo permite identificar y corregir problemas desde las primeras etapas, garantizando la eficiencia y el éxito en el desarrollo del sistema IoT de monitorización de invernaderos de cannabis medicinal.

\subsection{Requisitos de desarrollo:}
\textbf{Hardware:}
\begin{itemize}
	\item Una plataforma central para captar los datos de los sensores que no consuma mucha energía y permita conectividad wifi.
	\item Un sensor para medir temperatura y humedad ambiente.
	\item Un sensor para evaluar la intensidad de luz.
	\item Un sensor para captar la humedad del suelo.
	\item Una forma de visualizar los datos en el invernadero en tiempo real.
	\item Indicadores de condiciones críticas.
\end{itemize}

\textbf{Software:}
\begin{itemize}
	\item Plataforma de programación del hardware sencilla y de fácil implementación.
	\item Implementación de un servidor para almacenar y gestionar datos.
	\item Recibir alertas en un celular.
	\item Aplicación de escritorio para Windows donde visualizar los datos en tiempo real y el histórico de datos, con la capacidad adicional de poder activar mecanismos con un clic.
	\item Dashboard web para visualizar los datos en tiempo real y también el histórico de datos. Debe ser accesible desde internet.
\end{itemize}

\subsection{Desarrollo del prototipo:}

\begin{itemize}
	\item En esta etapa, se enfocó en la integración de los componentes hardware definidos, como la Raspberry Pi Pico W~\cite{misc:RPiPicoW} que permite conectar sensores y tiene conectividad wifi. Se utilizaron los sensores de humedad, temperatura~\cite{manual:DHT22}, luminosidad~\cite{manual:BH1750} y humedad del suelo~\cite{wiki:SensorHumedadSuelo}.

	\item Para la visualización de los datos en el invernadero se empleó una pantalla oled~\cite{manual:Oled}.

	\item Como indicadores de condiciones críticas se usó leds RGB~\cite{manual:LedRGB}, uno por cada variable medida.

	\item Se estableció la conexión de la Raspberry Pi Pico W con el servidor LAMP utilizando MQTT~\cite{manual:MQTT}, el servidor LAMP es el Broker MQTT y la Raspberry Pi Pico W es un cliente MQTT.

	\item Mediante Node.js se recopilaron los datos enviados por MQTT y se almacenaron usando mysql~\cite{misc:Mysql}.

	\item La forma más práctica de hacer envío de alertas a un teléfono celular fue mediante un bot de Telegram.

	\item La aplicación de escritorio fue desarrollada usando el lenguaje C\#. Mediante MQTT puede recepcionar datos en tiempo real o prender leds que representan la activación de un mecanismo.

	\item La aplicación web hecha con Node.js, HTML y CSS muestra los datos en tiempo real o el histórico de datos. Se puede usar desde cualquier lugar del mundo por internet.
\end{itemize}

\subsection{Evaluación del prototipo:}

El objetivo principal fue validar la efectividad de las funcionalidades implementadas y su capacidad para cumplir con los requisitos planteados en la fase inicial del proyecto.
\begin{itemize}
	\item \textbf{Prueba de energía:}
Todos los sensores, leds RGB y pantalla oled conectados al mismo tiempo funcionan consumiendo energía de la Raspberry Pi Pico W, no se ha necesitado darles alimentación externa.
	\item \textbf{Pruebas de Mecanismos de Alerta y Retroalimentación Visual:}
Se realizaron pruebas del sistema de alertas a través del bot de Telegram. Se verificó la capacidad del sistema para enviar notificaciones en tiempo real.
Los leds RGB funcionan bien, pero falta establecer la lógica de colores para indicar un estado normal o un estado crítico.
La pantalla oled tiene un espacio muy reducido, pero se le ha dado el formato para que muestre todos los datos.
El dashboard web que es accesible desde internet y la aplicación de escritorio funcionan bien.

\item \textbf{Prueba de envío de datos:}
El envío de alertas del bot de Telegram a veces tarda unos segundos, no es instantáneo.
Los datos enviados mediante MQTT se guardaron adecuadamente en la base de datos que se encuentra en el servidor LAMP.
\end{itemize}
\subsection{Modificación:}
\begin{itemize}
	\item Se estableció la lógica de colores de los leds RGB y los umbrales de los valores de los sensores, tal que el color del led depende de la magnitud del valor del sensor en relación con los umbrales predefinidos.
	\item El código Micropython utilizado en la Raspberry Pi Pico W fue modificado mediante programación orientada a objetos. Esta modificación permitió la división del código en varios archivos Python, facilitando la comprensión de la lógica del programa y evitando la extensión excesiva del código.
	\item Mediante código Micropython se configuró para que todo lo programado funcione en la Raspberry Pi Pico W apenas se le suministre energía.
	\item Se implementó la capacidad del bot de Telegram para enviar comandos, permitiendo ahora la consulta en tiempo real de valores específicos de sensores. Además, se habilitó la opción de activar un mecanismo, simbolizado por la activación de un LED de color verde.
	\item Se creó el instalador de la aplicación de escritorio para Windows.
	\item Se utilizó python para hacer la limpieza de datos y un resumen estadístico simple.
	\item Se implementó la capacidad adicional de alimentación mediante energía solar, conectando un Power Bank alimentado por un panel solar. Aunque no es un requisito inicial, se consideró viable esta implementación adicional.
\end{itemize}

\subsection{Documentación:}

Se elaboró una documentación completa que abarca aspectos técnicos, funcionales y de implementación del sistema desarrollado. La documentación detallada incluye manuales de usuario para las distintas interfaces, descripciones técnicas de hardware y software, así como instrucciones para la instalación y configuración del sistema.

Esta documentación sirve como recurso integral para cualquier persona que interactúe con el sistema, desde usuarios finales hasta desarrolladores o técnicos de mantenimiento. Su elaboración garantiza la comprensión y el uso efectivo del sistema, contribuyendo a su sostenibilidad a lo largo del tiempo.

\subsection{Pruebas:}

La implementación final del sistema se llevó a cabo tras la validación y ajustes continuos a lo largo de las fases de desarrollo y prototipado. En esta etapa, se consolidaron todas las funcionalidades y características planificadas, integrando los componentes hardware y software de manera coherente.

Se llevó a cabo una exhaustiva verificación de la interacción entre los sensores, la Raspberry Pi Pico W, la pantalla OLED, los LEDs RGB, la conexión con el servidor LAMP mediante MQTT, el almacenamiento correcto de datos en la base de datos y la interacción con el bot de Telegram.

La único no controlable es el tiempo de respuesta del bot de Telegram, que ocasionalmente puede demorar unos segundos. Esta limitación es inherente al servicio preexistente ofrecido por Telegram. Sin embargo, considerando que el bot de Telegram suele responder casi instantáneamente y su implementación es bastante sencilla, hemos decidido continuar utilizándolo, ya que ofrece más ventajas en comparación con una desventaja ocasional.

El dashboard web y el instalador de la aplicación de escritorio para Windows funcionan bien.

La implementación del panel solar y la Power Bank aseguran la alimentación continua de la Raspberry Pi Pico W, manteniendo todo el hardware en funcionamiento adecuado, incluso en condiciones nubladas. Se ha probado durante un total de 50 horas ininterrumpidas.

A través de un análisis de datos, se identificó la necesidad de realizar una limpieza de la información recopilada. Se observaron valores atípicos que se alejaban significativamente de la media, generados durante pruebas extremas a los sensores, como exponer el sensor de intensidad de luz a una fuente potente o sumergir el sensor de humedad del suelo en agua. Se implementó un código en Python para la detección y limpieza de estos valores atípicos, también conocidos como outliers, y la eliminación de filas con datos faltantes. Es importante destacar que estos datos no se eliminan de la base de datos principal, ya que se consideran relevantes para casos específicos. Se tiene previsto implementar un script en Python para la automatización futura de la limpieza de la base de datos.

Sin embargo, se vislumbra un potencial significativo para el futuro a medida que la cantidad de datos aumente y se registren más anomalías. En este escenario, se considera la posibilidad de implementar técnicas de aprendizaje automático (machine learning) para un análisis más avanzado y la detección automática de patrones.

\section{Desarrollo del proyecto}

El propósito inicial radicaba en la recopilación de datos ambientales, tales como humedad, temperatura, intensidad de luz y humedad del suelo, con el fin de almacenarlos y presentarlos de manera gráfica.

El cannabis medicinal requiere condiciones ambientales constantes y dentro de un umbral específico para un crecimiento óptimo y delicado.

Se ha implementado un servidor LAMP para gestionar el envío y recepción de datos, órdenes y alertas mediante MQTT. Este servidor también almacena los datos de los sensores en una base de datos.

\begin{figure}[h]
	\centering
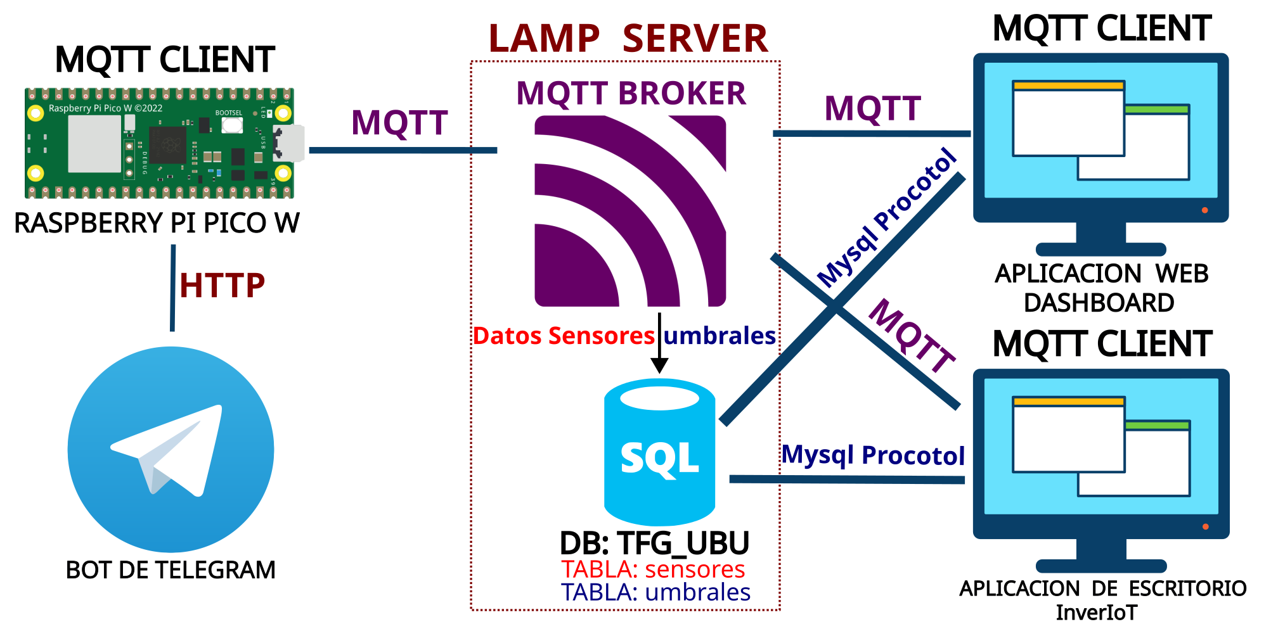
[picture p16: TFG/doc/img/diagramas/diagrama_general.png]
	
	\caption{Interacción entre cada parte del proyecto.} \label{Img:diagrama_general}
\end{figure}

Definimos umbrales (valor mínimo/máximo) para monitorizar cuando es que los valores de los sensores no están dentro de límites aceptables. En caso de detectar un valor anómalo fuera de estos umbrales, se genera una alerta.

\begin{table}[htbp]
\begin{center}
	\caption{Umbrales ideales para un invernadero de cannabis medicinal.}\label{tabla:umbrales}
\begin{tabular}{|l|l|l|l|}
\hline
\rowcolor[HTML]{C0C0C0} 
\textbf{Característica} & \textbf{Mínimo} & \textbf{Máximo} & \textbf{Unidades}\\ \hline
TEMPERATURA & 30 & 35 & \textcelsius\\ \hline
HUMEDAD & 30 & 70 & \% \\ \hline
LUMINOSIDAD & 30 & 150 & lux\\ \hline
HUMEDAD DEL SUELO & 20 & 80 & \% \\ \hline
\end{tabular}
\end{center}
\end{table}

%\begin{table}[htbp]
%\begin{center}
%\caption{Topics de MQTT usados.}
%\begin{tabular}{|l|l|} %|c|c|
%\hline
%\rowcolor[HTML]{C0C0C0} 
%\textbf{Nombre del topic} & \textbf{Descripción}\\ \hline
%invernadero/sensores & fecha, hora y valores de sensores \\ \hline
%invernadero/umbrales & valores límite \\ \hline
%invernadero/ordenes & Permite activar un mecanismo \\ \hline
%\end{tabular}
%\end{center}
%\end{table}

%A continuación veremos cada parte del proyecto para su mejor comprensión.

\subsection{Servidor LAMP}\label{proyecto:LAMP}

Opté por establecer un servidor LAMP para facilitar el envío y manejo de datos. La implementación de este servidor se llevó a cabo en el sistema operativo Ubuntu~\cite{misc:Ubuntu}, el cual fue virtualizado utilizando Hyper-V~\cite{manual:Hyper_V}.
En esta instancia, se emplea un servidor físico HP ProLiant~\cite{misc:HP_ProLiant} para la virtualización de los servicios Apache~\cite{misc:Apache}, MySQL~\cite{misc:Mysql}, PHP~\cite{misc:PHP} y SSH~\cite{misc:SSH}.

\begin{table}[htbp]
\begin{center}
\caption{Características del servidor HP ProLiant.}
\begin{tabular}{|l|l|}
\hline
\rowcolor[HTML]{C0C0C0} 
\textbf{Característica} & \textbf{Descripción}\\ \hline
Sistema operativo & Windows Server 2019 Standard\\ \hline
Fabricante & Hewlett Packard Enterprise \\ \hline
Modelo & Hewlett Packard Enterprise x64 Class PC\\ \hline
Procesador & Intel(R) Xeon(R) Silver 4210R CPU @ 2.4GHz 2.39GHz\\ \hline
Memoria instalada (RAM) & 128 GB (128 GB utilizable) \\ \hline
Tipo de sistema & Sistema operativo de 64 bits, procesador x64 \\ \hline
\end{tabular}
\end{center}
\end{table}

\begin{figure}[h]
	\centering
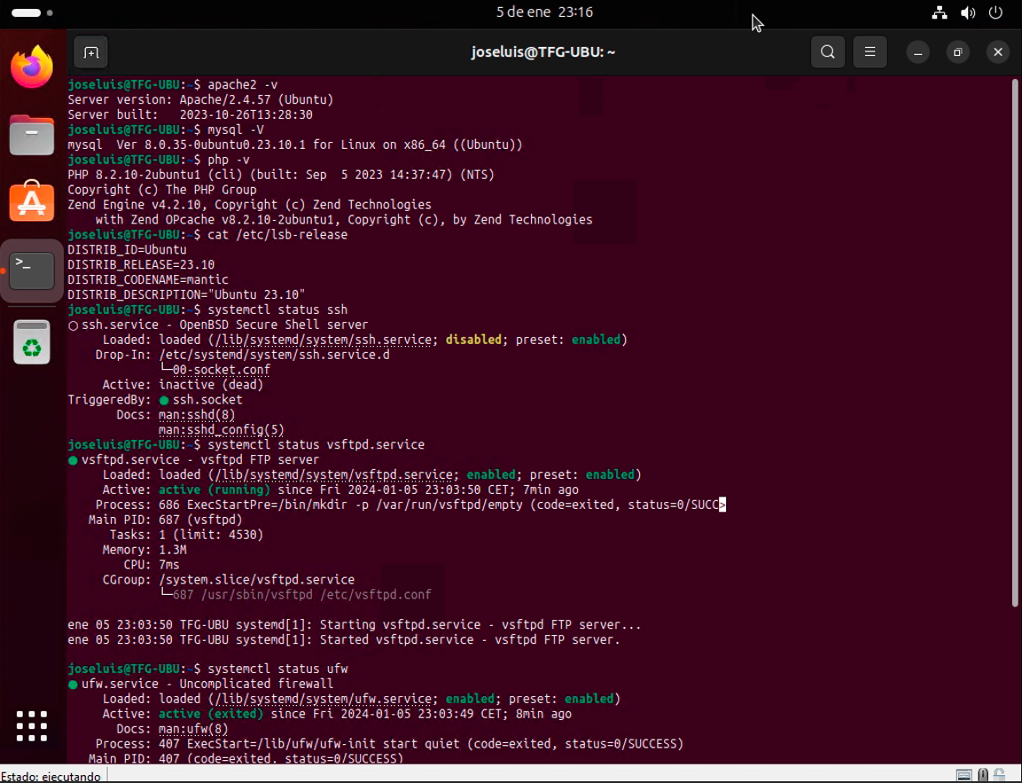
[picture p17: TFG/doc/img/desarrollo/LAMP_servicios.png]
	
	\caption{Servicios instalados y operativos en el servidor LAMP.} \label{Img:LAMP_servicios}
\end{figure}

\subsection{NodeMqtt}\label{proyecto:NodeMqtt}

\textbf{NodeMqtt} es un servicio en Node.js~\cite{misc:Nodejs} que se ejecuta dentro del servidor LAMP, escucha los topics \textbf{invernadero/sensores} e \textbf{invernadero/umbrales}. Utiliza la librería MQTT.js~\cite{misc:MQTTjs}.

Está conformado por los siguientes archivos: index.js y package.json.

%\begin{itemize}
	%\item \textbf{index.js:}
		%Es el punto de entrada del código de la aplicación.
	%\item \textbf{package.json:}
		%Es un archivo de configuración que describe la aplicación y sus dependencias.
%\end{itemize}

Los datos son enviados por la placa Raspberry Pi Pico W RP2040~\cite{misc:RPiPicoW} usando MQTT, que recopila valores de sensores, y el servicio \textbf{nodeMqtt} captura los datos de los topics MQTT llamados \textbf{invernadero/sensores} e \textbf{invernadero/umbrales}, formatea y luego inserta estos datos en la base de datos MySQL~\cite{misc:Mysql} llamada \textbf{TFG\_UBU}.

La base de datos contiene dos tablas llamadas \textbf{sensores} y \textbf{umbrales}.

\begin{table}[htbp]
\begin{center}
	\caption{Columnas de las tablas contenidas en TFG\_UBU.}
\begin{tabular}{|l|l|}
\hline
\rowcolor[HTML]{C0C0C0} 
\textbf{sensores} & \textbf{umbrales}\\ \hline
fecha & temperatura\_minima \\ \hline
hora & temperatura\_maxima \\ \hline
temperatura & humedad\_ambiente\_minima \\ \hline
humedad & humedad\_ambiente\_maxima \\ \hline
intensidad\_luz & luminosidad\_minima \\ \hline
humedad\_suelo & luminosidad\_maxima \\ \hline
			   & humedad\_suelo\_minima \\ \hline
			   & humedad\_suelo\_maxima \\ \hline
			   & fecha\_actualización \\ \hline
\end{tabular}
\end{center}
\end{table}

\begin{figure}[h]
	\centering
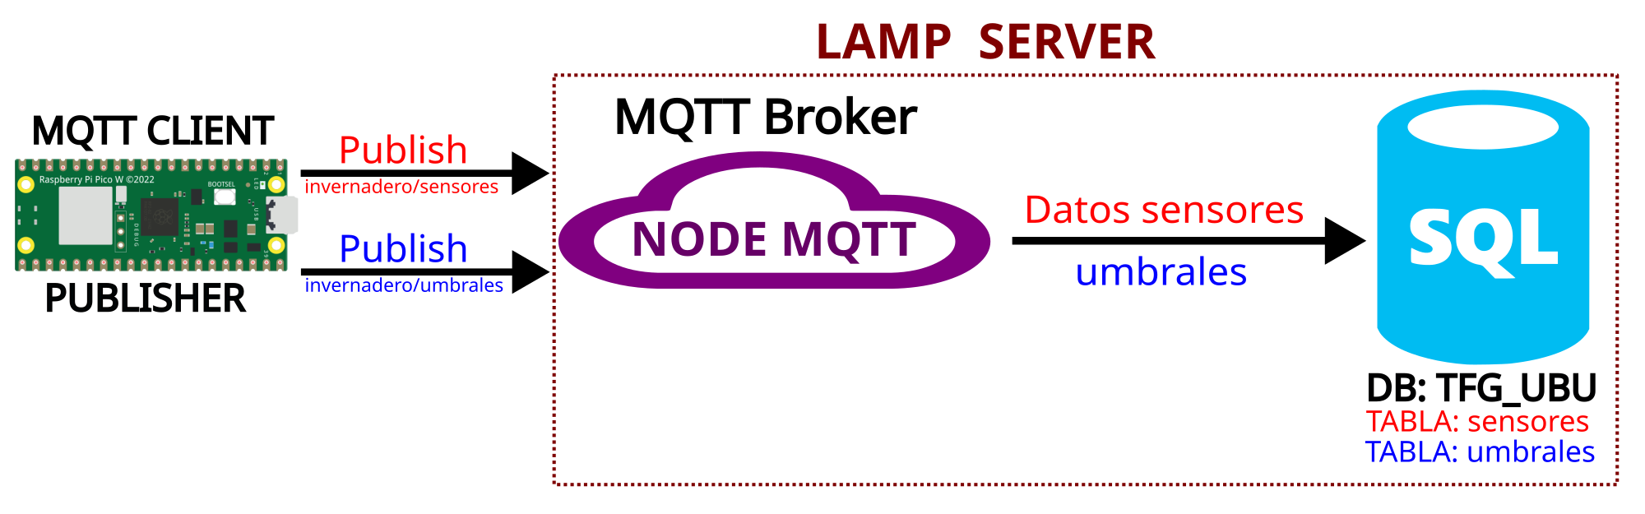
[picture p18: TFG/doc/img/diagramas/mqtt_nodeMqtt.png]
	
	\caption{MQTT con Node.js para almacenar datos de los sensores.}
\end{figure}

%\begin{figure}[h]
	%\centering
	%\includegraphics[width=0.1\textwidth]{img/desarrollo/mysql_tabla_sensores.png}
	%\caption{Data almacenada en la tabla \textbf{sensores}.}
%\end{figure}

\subsection{Hardware}\label{proyecto:Hardware}

Se optó por la Raspberry Pi Pico W debido a su eficiencia energética y coste accesible. Se conectaron al sistema un sensor de humedad y temperatura DHT22~\cite{manual:DHT22}, un sensor de intensidad de luz BH1750~\cite{manual:BH1750}, y un sensor de humedad de suelo~\cite{wiki:SensorHumedadSuelo}. Además, se incorporaron LEDs RGB~\cite{manual:LedRGB} para señalizar alertas.

\begin{figure}[h]
    \centering
    
    \caption{Conexiones.} \label{Img:conexionesHardware}
\end{figure}

\begin{itemize}
	\item La Raspberry Pi Pico W estará situada en el invernadero para la recopilación de datos.
	\item Los LEDs RGB, instalados en la oficina del cliente, indicarán visualmente si los valores superan los umbrales establecidos.
	\item La pantalla OLED estará colocada en la puerta del invernadero para mostrar los valores actualizados.
\end{itemize}

Los datos se muestran en una pantalla OLED~\cite{manual:Oled} en tiempo real.

La Raspberry Pi Pico W establece conexión con el servidor LAMP a través de MQTT, facilitando la transmisión de los datos de los valores medidos por los sensores, el envío de umbrales predefinidos y la recepción de órdenes para ejecutar acciones específicas.

%\begin{figure}[h]
	%\centering
	%\includegraphics[width=0.5\textwidth]{img/fotos/conexiones_real.png}
	%\caption{Raspberry Pi Pico W y sensores conectados.} \label{Img:conexion_simple}
%\end{figure}

\begin{figure}[h]
	\centering
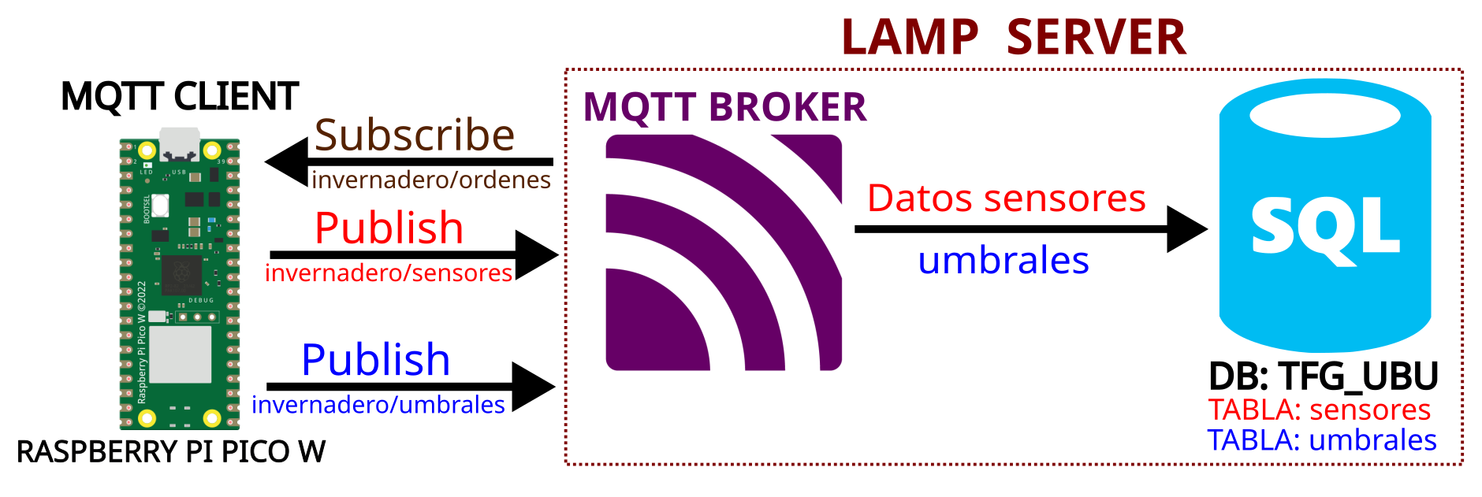
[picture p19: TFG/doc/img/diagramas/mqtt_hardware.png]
	
	\caption{Conexión de la Raspberry Pi Pico W con el servidor LAMP.} \label{Img:mqtt_hardware}
\end{figure}

\begin{figure}[h]
	\centering
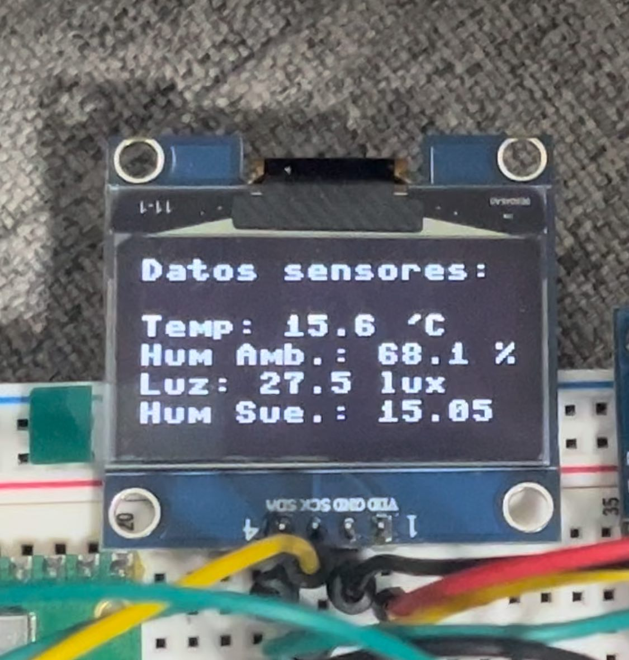
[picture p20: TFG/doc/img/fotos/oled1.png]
	
	\caption{Pantalla oled conectada a la Raspberry Pi Pico W.} \label{Img:oled_conexion}
\end{figure}

%\begin{figure}[h]
	%\centering
	%\includegraphics[width=0.7\textwidth]{img/herramientas/rpipicow_umqtt.png}
	%\caption{Librería umqtt para conexión mediante MQTT.} \label{Img:rpipicow_umqtt}
%\end{figure}

\subsection{InverIoT}\label{proyecto:InverIoT}
Usando el lenguaje de programación C\#~\cite{manual:CSharp} y utilizando Windows Forms, se desarrolla una aplicación de escritorio para Windows al que se ha llamado InverIoT, que permite al usuario monitorizar el histórico de datos, y también visualizar los datos en tiempo real.

\begin{figure}[h]
    \centering
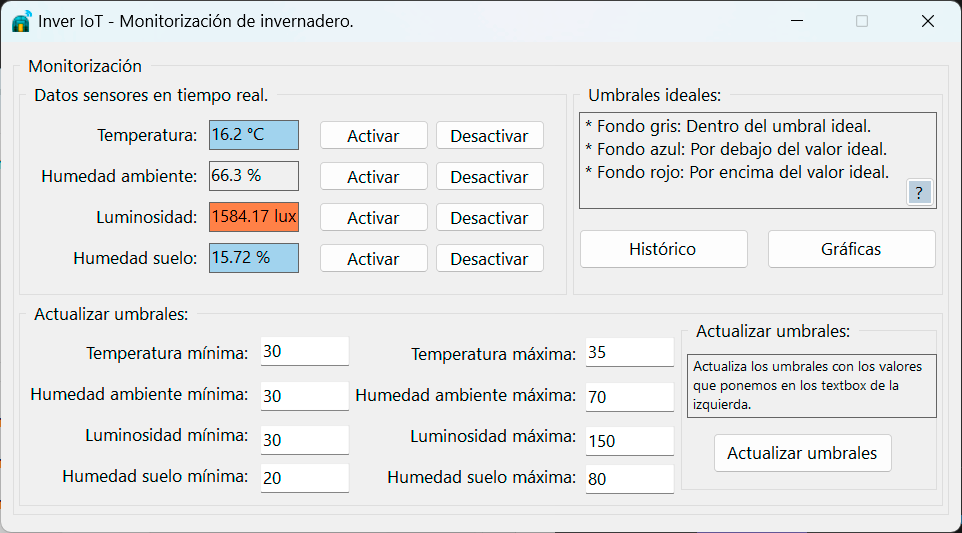
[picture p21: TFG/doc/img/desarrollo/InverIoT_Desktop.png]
    
	\caption{Aplicación de escritorio \textbf{InverIoT}.}
\end{figure}

\begin{figure}[h]
    \centering
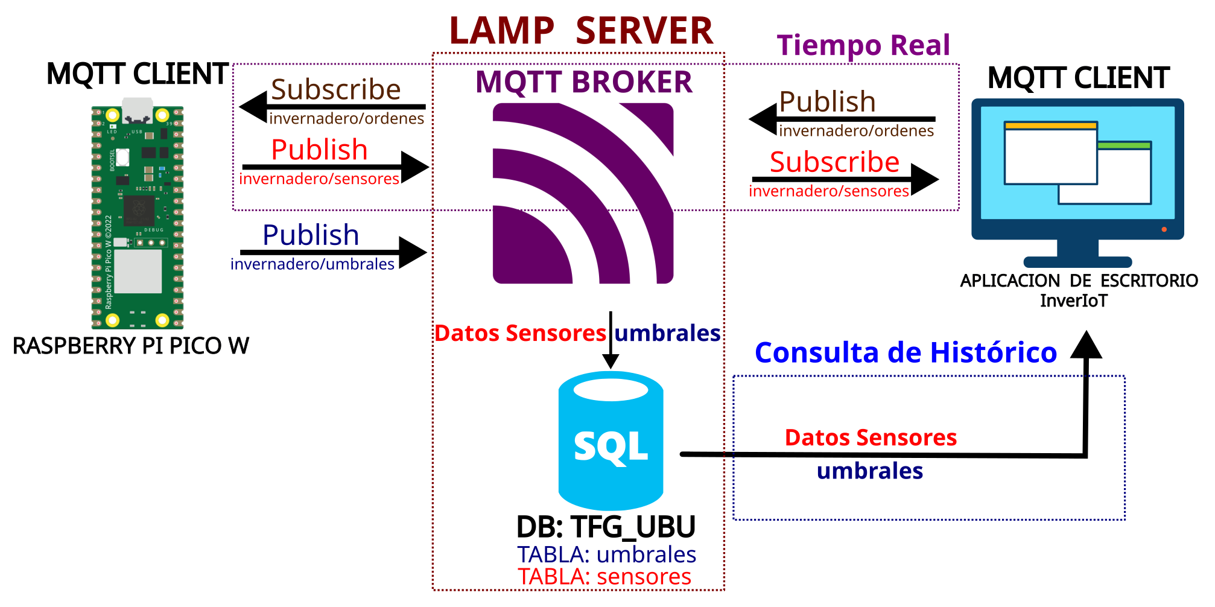
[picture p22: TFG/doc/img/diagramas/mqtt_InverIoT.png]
    
    \caption{Interacción entre la aplicación y el servidor LAMP.}
\end{figure}

Utilizando el protocolo MQTT~\cite{manual:MQTT}, la aplicación suscribe y recibe los datos publicados en el mismo tema. 

Para el histórico de datos no utiliza MQTT, se conecta al servidor LAMP mediante Mysql Protocol y extrae la data de la base de datos llamada \textbf{TFG\_UBU}.

\begin{figure}[h]
    \centering
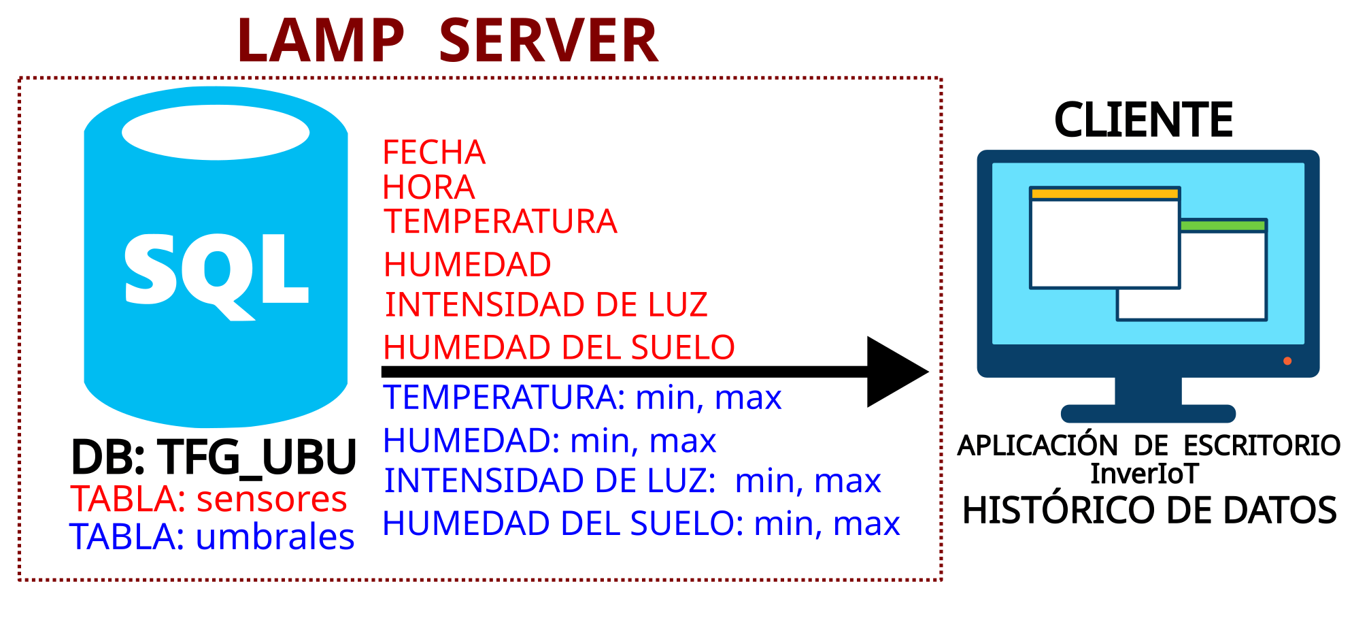
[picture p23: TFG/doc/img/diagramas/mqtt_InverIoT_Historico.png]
    
    \caption{Datos usados para mostrar el histórico de datos.}
\end{figure}

Estos datos son formateados y presentados en textboxes correspondientes, con unidades de medida agregadas.

Se incorporan botones para activar o desactivar mecanismos, esto es representado prendiendo o apagando un LED verde, recordar que hay un led RGB por cada variable medida.

\begin{figure}[h]
    \centering
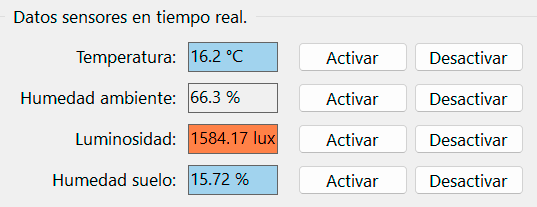
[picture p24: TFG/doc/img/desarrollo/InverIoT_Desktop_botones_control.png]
    
	\caption{Botones para activar o desactivar mecanismos.}
\end{figure}

\begin{figure}[h]
	\centering
	
	\caption{Activación de un mecanismo mediante un clic.}\label{img:InverIoTBotones}
\end{figure}

\begin{figure}[h]
	\centering
	
	\caption{Aplicación indicando que se ha sobrepasado el umbral de luz.}\label{img:InverIoTPasandoUmbralLuz}
\end{figure}

En la imagen \ref{img:InverIoTBotones} se puede observar 8 textboxes en la parte inferior para ajustar manualmente los valores mínimos y máximos de cada parámetro. Inicialmente estos valores fueron extraídos de la base de datos en el servidor LAMP.

En la imagen \ref{img:InverIoTPasandoUmbralLuz} se está sometiendo al sensor de intensidad de luz a sobrepasar el umbral establecido, el led rojo indica eso. Si un valor está por debajo del umbral, se indicará mediante el led de color azul. Se puede observar tal acontecimiento de colores en el hardware y en la aplicación de escritorio.

\begin{figure}[h]
    \centering
    
    \caption{Historial de los datos mostrada en la aplicación.}
\end{figure}

\begin{figure}[h]
    \centering
    
    \caption{Gráfica mostrando los datos en un intervalo de fechas.}
\end{figure}

\pagebreak

\subsection{Dashboard}\label{proyecto:Dashboard}
Se ha creado un dashboard web con Node.js que habilita al usuario para visualizar en tiempo real los datos capturados por los sensores y acceder a un historial con filtro de fecha. La interfaz presenta similitudes con la aplicación de escritorio para mantener una experiencia coherente.

Los valores que exceden los umbrales establecidos se destacan mediante cambios de color.

\begin{figure}[h]
    \centering
    
    \caption{Intensidad de luz superando los umbrales.} \label{Img:Dashboard1}
\end{figure}

La plataforma incluye una gráfica en tiempo real y la capacidad de acceder a un historial con filtro de fecha.

\begin{figure}[h]
    \centering
    
    \caption{Dashboard web interactuando con el servidor LAMP.} \label{Img:mqtt_dashboard}
\end{figure}

La imagen \ref{Img:mqtt_dashboard} ilustra de manera significativa el uso de MQTT para la obtención de datos en tiempo real. Cabe destacar que, además, se utiliza el protocolo MySQL para extraer información de la base de datos alojada en el servidor LAMP, permitiendo así mostrar el histórico de datos

\begin{figure}[h]
    \centering
    
    \caption{Valores específicos extraídos de la base de datos.} \label{Img:Dashboard_diagrama_Historico}
\end{figure}

\begin{figure}[h]
    \centering
    
    \caption{Vista del historial, al cargar, muestra los datos del día actual.} \label{Img:Dashboard_Historico}
\end{figure}

%\begin{figure}[h]
    %\centering
    %\includegraphics[width=1\textwidth]{img/diagramas/mqtt_dashboard_TiempoReal.png}
    %\caption{Mediante MQTT extrae los datos para mostrarlos en tiempo real.} \label{Img:Dashboard_diagrama_TiempoReal}
%\end{figure}

El panel de control está disponible para su acceso a través del siguiente enlace: \href{http://www.inveriot.com}{InverIoT Dashboard}

%\begin{figure}[h]
	%\centering
	%\includegraphics[width=1\textwidth]{img/desarrollo/Dashboard2.png}
	%\caption{Página Web \href{http://www.inveriot.com}{InverIoT} desarrollada con Node.js.}
%\end{figure}

%\begin{figure}[h]
	%\centering
	%\includegraphics[width=1\textwidth]{img/desarrollo/Dashboard3.png}
	%\caption{Página Web \href{http://www.inveriot.com}{InverIoT} desarrollada con Node.js.}
%\end{figure}
%En este contexto, detallaré la configuración del servidor y la implementación de Node.js en la página web.

\subsection{Bot de Telegram}\label{proyecto:BotTelegram}

Se implementó la funcionalidad de enviar alertas a través de Telegram en caso de que los valores recopilados excedieran los umbrales ideales~\ref{tabla:umbrales}.

Para esta función, empleamos un bot de Telegram~\cite{misc:Telegram_bots} que envía mensajes de alerta si alguno de los valores está fuera del umbral establecido. 

La creación del bot se hace utilizando BotFather\cite{misc:BotFather} que es un bot especial en la plataforma de mensajería Telegram~\cite{misc:Telegram} que permite a los usuarios crear y gestionar sus propios bots. Al interactuar con BotFather, los usuarios pueden definir el nombre, la descripción, la imagen y otras configuraciones de su bot. Además, BotFather proporciona un token único para cada bot creado, el cual se utiliza para autenticar las solicitudes y permitir la interacción entre el bot y la plataforma de Telegram.

Para este proyecto el nombre del bot creado es \textbf{InverIoTBot}.

\begin{figure}[h]
	\centering
	
	\caption{La interacción es mediante protocolo HTTP.} \label{Img:telegramBot}
\end{figure}

El bot también brinda la posibilidad de enviar comandos para acciones específicas, como obtener el valor de un sensor o activar un mecanismo vinculado a un sensor en particular.

Tener presente que la activación de un mecanismo se representa encendiendo un LED de color verde, y cada sensor está asociado a un LED RGB específico.
 
\begin{table}[htbp]
\begin{center}
\caption{Comandos del bot para la consulta de los datos.}
\begin{tabular}{|l|l|} %|c|c|
\hline
\rowcolor[HTML]{C0C0C0} 
\textbf{Comando} & \textbf{Valor que retorna}\\ \hline
/temp & Temperatura del ambiente\\ \hline
/huma& Humedad del ambiente \\ \hline
/lum & Luminosidad\\ \hline
/hums & Humedad del suelo\\ \hline
/todos & Todos los valores de los sensores\\ \hline
\end{tabular}
\end{center}
\end{table}

\begin{table}[htbp]
\begin{center}
\caption{Comandos del bot para activar un mecanismo.}
\begin{tabular}{|l|l|} %|c|c|
\hline
\rowcolor[HTML]{C0C0C0} 
\textbf{Comando} & \textbf{Acción específica}\\ \hline
/t\_ON & Mecanismo de temperatura prendido\\ \hline
/t\_OFF & Mecanismo de temperatura apagado\\ \hline
/ha\_ON & Mecanismo de humedad del ambiente prendido\\ \hline
/ha\_OFF & Mecanismo de humedad del ambiente apagado\\ \hline
/l\_ON & Mecanismo de luminosidad prendido\\ \hline
/l\_OFF & Mecanismo de luminosidad apagado\\ \hline
/hs\_ON & Mecanismo de humedad del suelo prendido\\ \hline
/hs\_OFF & Mecanismo de humedad del suelo apagado\\ \hline
\end{tabular}
\end{center}
\end{table}

\begin{figure}[h]
	\centering
	
	\caption{Alertas del bot de Telegram.} \label{Img:BotTelegram_alertas}
\end{figure}

\begin{figure}[h]
	\centering
	
	\caption{Consulta a la base de datos mediante comandos usando Telegram.}
\end{figure}

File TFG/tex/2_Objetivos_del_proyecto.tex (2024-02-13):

\capitulo{2}{Objetivos del proyecto}
%Este apartado explica de forma precisa y concisa cuales son los objetivos que se persiguen con la realización del proyecto. Se puede distinguir entre los objetivos marcados por los requisitos del software a construir y los objetivos de carácter técnico que plantea a la hora de llevar a la práctica el proyecto.
\section{Objetivos Generales}
\begin{itemize}
\item \textbf{Desarrollo del Sistema de Adquisición de Datos:}
Implementar un sistema eficiente de adquisición de datos que pueda recopilar información precisa proveniente de los sensores (DHT22, BH1750, sensor de humedad de suelo) instalados en el invernadero.
\item \textbf{Diseño de la Interfaz de Usuario:}
Desarrollar una interfaz de usuario intuitiva y fácil de usar, que permita a los usuarios visualizar en tiempo real los datos recopilados y tomar decisiones informadas sobre el control del entorno del invernadero.
\item \textbf{Implementación de Protocolos de Comunicación:}
Establecer protocolos de comunicación eficientes para la transmisión de datos entre los sensores y la Raspberry Pi Pico W, así como para la conexión con otros dispositivos o sistemas externos si es necesario.
\end{itemize}
\pagebreak

\section{Objetivos Técnicos}
\begin{itemize}
\item \textbf{Integración de Hardware:} 
Seleccionar, configurar e integrar de manera óptima el hardware necesario (Raspberry Pi Pico W, pantalla OLED 128x64, sensores) para garantizar la estabilidad y la eficacia del sistema.

\item \textbf{Eficiencia Energética:}
Implementar estrategias de programación y configuración de hardware que optimicen el consumo de energía, asegurando una operación sostenible del sistema en entornos con recursos limitados. Precisamente la Raspberry Pi Pico W es conocida por su bajo consumo energético.

\item \textbf{Validación en Entorno Real:}
Realizar pruebas exhaustivas del sistema en un entorno de cultivo de cannabis medicinal real, evaluando su rendimiento, confiabilidad y adaptabilidad a condiciones variables.

\item \textbf{Consideraciones Económicas:}
Evaluar y optimizar los costos asociados al desarrollo e implementación del sistema, garantizando la viabilidad económica para agricultores de diferentes escalas y recursos.

\item \textbf{Documentación Completa:}
Generar una documentación detallada que abarque el diseño, la implementación y la configuración del sistema, facilitando la comprensión y la replicación por parte de otros interesados.
Estos objetivos, tanto del software como técnicos, se plantean con el propósito de cumplir con los requisitos del proyecto y garantizar la efectividad y utilidad del sistema de monitorización propuesto para invernaderos de cannabis medicinal.
\end{itemize}

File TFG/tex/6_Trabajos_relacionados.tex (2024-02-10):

\capitulo{6}{Trabajos relacionados}

Para comprender plenamente la contribución y novedad de este proyecto, es esencial explorar investigaciones y desarrollos previos relacionados.

\subsection{Monitorización de la energía consumida mediante Raspberry Pi para sistema domótico}\label{Proy1}

Se trata de un TFG desarrollado en la Universidad Carlos III de Madrid que trata sobre un sistema de monitorización de energía consumida para una instalación domótica mediante el uso de una Raspberry Pi, en el que se debe realizar el diseño del circuito y la programación correspondientes para poder extraer datos de diez sensores de corriente de forma simultánea.

Cada sensor recoge información correspondiente a una línea del cuadro de electricidad donde irá instalado.

En el desarrollo de este proyecto se pueden diferenciar dos partes:

\begin{itemize}
\item Montaje del circuito que lleva los datos obtenidos de los sensores de corriente hacia la Raspberry Pi para que puedan ser gestionados adecuadamente.

\item Configuración de la Raspberry Pi para la lectura y procesado de los datos obtenidos a través de cada uno de los sensores. Tales datos son guardados en diferentes ficheros dependiendo del canal de los que provengan, denominados datos\_canalX.txt, donde X es el número del sensor.
\end{itemize}

Introduciendo un comando determinado el sistema es capaz de:

\begin{itemize}
	\item Modificar el tiempo existente entre el recojo de cada muestra para un canal específico, que es guardado en un fichero de tiempos para su continua lectura.
	\item Recoger datos a partir de un canal, fecha y hora, de forma que se lee el fichero datos\_canalX correspondiente al canal introducido, y se guardan en otro fichero todos aquellos datos posteriores a la fecha y hora introducidos.
\end{itemize}

Podemos ver su referencia en la bibliografía en la referencia~\cite{TesisBaron2017}.

En la columna \textbf{Proy1} de la tabla~\ref{tabla:comparativa-proyectos} podemos ver algunas características de este proyecto.

\subsection{Diseño e implementación de un sistema domótico basado en Raspberry Pi}\label{Proy2}

Se trata de un TFG desarrollado en la Universidad Carlos III de Madrid que trata sobre un sistema domótico de bajo coste, basado en código libre (UNIX/LINUX). Dicho sistema permite al usuario manejar de forma fácil y sencilla elementos finales como motores y leds.

El elemento de software principal es el sistema operativo Raspbian (basado en Debian), aunque ahora es llamado Raspberry Pi OS. Tal sistema operativo es instalado en la RaspberryPi.

El segundo elemento software importante es el servidor web Apache que gestiona la aplicación web desarrollada bajo el patrón de desarrollo Modelo-Vista-Controlador (MVC).

El sistema domótico está compuesto por varios sus-sistemas:

\begin{itemize}
	\item La aplicación web.
	\item La base de datos.
	\item El conjunto de sensores y actuadores.
\end{itemize}

La aplicación web se ha desarrollado sobre un servidor LAMP que es accesible desde el exterior y que actua de interfaz sobre el usuario del sistema domótico y le propio sistema.

Algunas acciones que puede realizar el usuario mediante este sistema:

\begin{itemize}
	\item Consultar temperatura y humedad.
	\item Controlar apertura puertas/persianas.
	\item Consultar histórico de temperaturas y humedades.
	\item Consultar movimiento en una habitación.
	\item Controlar iluminación interior.
\end{itemize}

Podemos ver su referencia en la bibliografía en la referencia~\cite{TesisSantos2017}.

En la columna \textbf{Proy2} de la tabla~\ref{tabla:comparativa-proyectos} podemos ver algunas características de este proyecto.

\section{Fortalezas y debilidades este proyecto}

Las fortalezas clave del proyecto son:

\begin{itemize}
	\item Todos los elementos utilizados en este proyecto son fácilmente accesibles, tanto en términos de software como de hardware.
	\item La elección de la Raspberry Pi Pico W fue crucial gracias a su bajo consumo de energía, su compacto tamaño que facilita la portabilidad y su capacidad de conectividad Wifi.
	\item La versatilidad de la Raspberry Pi Pico W, con su capacidad de conectividad Wifi, ha posibilitado tanto el envío de datos como la recepción de órdenes. Además, su flexibilidad se evidencia en la implementación exitosa de MQTT en el proyecto.
	\item La modularidad del sistema permite una fácil escalabilidad, ya que es posible agregar nuevos sensores o funcionalidades sin mayores complicaciones.		
	\item La presentación gráfica de datos en tiempo real en una pantalla OLED y la posibilidad de acceder a través de una aplicación de escritorio y un panel web ofrecen múltiples formas de acceder y visualizar la información recopilada.
\end{itemize}

Las principales debilidades de este proyecto son:

\begin{itemize}
	\item La prueba del sistema se realizó en un ambiente no controlado, lo que puede afectar la precisión de los datos y la generación de alertas. Esto podría limitar la fiabilidad de las respuestas del sistema en condiciones reales.
	\item La funcionalidad del proyecto está intrínsecamente ligada a la conectividad Wifi de la Raspberry Pi Pico W. Problemas en la red Wifi podrían afectar la transmisión de datos y la recepción de órdenes.
	\item Aunque se han incluido sensores relevantes, la variedad podría ser limitada. La adición de más tipos de sensores podría mejorar la capacidad de monitoreo y la precisión de los datos recopilados.
	\item A medida que se agregan más sensores y funcionalidades, la capacidad de la Raspberry Pi Pico W podría alcanzar sus límites. En proyectos a mayor escala, se podría requerir hardware más potente.
\end{itemize}

\begin{table}[htbp]
\centering
\begin{tabular}{lccc}
\toprule
Características & MICM & Proy1 & Proy2  \\
\midrule
Proyecto libre & \cellcolor{green!25} {\checkmark} & \cellcolor{green!25} {\checkmark} & \cellcolor{green!25} {\checkmark} \\
Menor precio en modelo de Raspberry Pi & \cellcolor{green!25} {\checkmark} & \cellcolor{red!25} {\xmark} & \cellcolor{red!25} {\xmark} \\
Menor consumo de energía de Raspberry Pi & \cellcolor{green!25} {\checkmark} & \cellcolor{red!25} {\xmark} & \cellcolor{red!25} {\xmark} \\
Escalabilidad & \cellcolor{green!25} {\checkmark} & \cellcolor{green!25} {\checkmark} & \cellcolor{green!25} {\checkmark} \\
Modularidad & \cellcolor{green!25} {\checkmark} & \cellcolor{green!25} {\checkmark} & \cellcolor{green!25} {\checkmark} \\
Más opciones de visualización de datos & \cellcolor{green!25} {\checkmark} & \cellcolor{red!25} {\xmark} & \cellcolor{red!25} {\xmark} \\
Mayor potencia en modelo de Raspberry Pi & \cellcolor{red!25} {\xmark} & \cellcolor{green!25} {\checkmark} & \cellcolor{green!25} {\checkmark} \\
Más opciones de acceso de datos & \cellcolor{green!25} {\checkmark} & \cellcolor{red!25} {\xmark} & \cellcolor{red!25} {\xmark} \\
Interacción multiplataforma             & \cellcolor{green!25} {\checkmark} & \cellcolor{green!25} {\checkmark} & \cellcolor{green!25} {\checkmark} \\
WiFi entre elementos                    & \cellcolor{green!25} {\checkmark} & \cellcolor{green!25} {\checkmark} & \cellcolor{green!25} {\checkmark \\
Almacenamiento de datos                    & \cellcolor{green!25} {\checkmark} & \cellcolor{green!25} {\checkmark} & \cellcolor{green!25} {\checkmark} \\
\bottomrule
\end{tabular}
\caption{Comparativa de las características de los proyectos.}
\label{tabla:comparativa-proyectos}
\end{table}

%Este apartado sería parecido a un estado del arte de una tesis o tesina. En un trabajo final grado no parece obligada su presencia, aunque se puede dejar a juicio del tutor el incluir un pequeño resumen comentado de los trabajos y proyectos ya realizados en el campo del proyecto en curso.

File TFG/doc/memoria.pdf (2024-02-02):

Informática; medicinal; Martínez-Quintanilla

TFG del Grado en Ingeniería

Diseño de un sistema
económico IoT de
monitorización de
invernaderos de cannabis

Presentado por José Luis Caballero

en Universidad de Burgos — 16 de febrero de

Tutor: Alejandro Merino Gómez
Tutor: Carlos Cambra Baseca


D. Alejandro Merino Gómez, profesor del departamento de Digitalización, área de Systems Engineering and Automation y D. Carlos Cambra Baseca, profesor del departamento de Digitalización del área de Computer Science and Artificial Intelligence,

Exponen:

Que el alumno D. José Luis Caballero Martínez-Quintanilla, con DNI 48471169-A, ha realizado el Trabajo final de Grado en Ingeniería Informática titulado Diseño de un sistema económico IoT de monitorización de invernaderos de cannabis medicinal.

Y que dicho trabajo ha sido realizado por el alumno bajo la dirección del que suscribe, en virtud de lo cual se autoriza su presentación y defensa.

### En Burgos, 16 de febrero de 2024

Vº. Bº. del Tutor:

D. Merino Gómez, Alejandro

Vº. Bº. del co-tutor:

D. Cambra Baseca, Carlos

i

Resumen

El presente trabajo de fin de grado aborda el diseño de un sistema económico basado en el Internet de las cosas (IoT) para la monitorización de invernaderos destinados al cultivo de cannabis medicinal. El objetivo principal es mejorar la eficiencia y la calidad del cultivo mediante la implementación de sensores y dispositivos conectados que permitan la recolección y análisis de datos en tiempo real.

El hardware seleccionado para este proyecto incluye la Raspberry Pi Pico W como unidad central, una pantalla OLED 128x64 para la visualización de información, el sensor DHT22 para la medición de la temperatura y humedad ambiente, el sensor BH1750 para evaluar la intensidad lumínica, y un sensor de humedad de suelo para monitorear las condiciones de la tierra.

A lo largo del trabajo, se detalla el proceso de integración de estos componentes, se describen las tecnologías utilizadas para la comunicación y el manejo de datos, y se presenta la interfaz de usuario diseñada para la visualización de información relevante. Se destacan también las consideraciones económicas que han llevado a la elección de cada componente, buscando una solución asequible sin comprometer la calidad de los resultados.

Los resultados obtenidos demuestran la viabilidad y eficacia del sistema propuesto, ofreciendo a los agricultores de cannabis medicinal un instrumento práctico y accesible para mejorar la gestión de sus invernaderos. Este trabajo contribuye al campo emergente de la agricultura inteligente y sostenible, abriendo posibilidades para futuras investigaciones y aplicaciones en el ámbito de la monitorización agrícola basada en IoT.

Descriptores

Raspberry Pi Pico W, Micropython, Autónomo, Sistema Domótico, Bot, Telegram, Python . . .

ii

Abstract

This project deals with the design of an economic system based on the Internet of Things (IoT) for the monitoring of greenhouses for the cultivation of medical cannabis. The main objective is to improve the efficiency and quality of the crop through the implementation of sensors and connected devices that allow the collection and analysis of data in real time.

The hardware selected for this project includes the Raspberry Pi Pico W as the central unit, a 128x64 OLED screen for displaying information, the DHT22 sensor for measuring ambient temperature and humidity, the BH1750 sensor for evaluating light intensity, and a soil moisture sensor for monitoring soil conditions.

Throughout the paper, the integration process of these components is detailed, the technologies used for communication and data management are described, and the user interface designed for the visualization of relevant information is presented. It also highlights the economic considerations that led to the choice of each component, seeking an affordable solution without compromising the quality of the results.

The results obtained demonstrate the feasibility and effectiveness of the proposed system, offering medical cannabis farmers a practical and accessible tool to improve the management of their greenhouses. This work contributes to the emerging field of smart and sustainable agriculture, opening possibilities for future research and applications in the field of IoT-based agricultural monitoring.

Keywords

Raspberry Pi Pico W, Micropython, Autonomous, Domotic System, Bot, Telegram, Python . . .

# Índice general

Índice general | iii
Índice de figuras | iv
Índice de tablas | v
1. Introducción | 1
2. Objetivos del proyecto | 3
3. Conceptos teóricos | 5
3.5. Sensores (DHT22, BH1750, Sensor de Humedad de Suelo) . | 7
4. Técnicas y herramientas | 11
Bibliografía | 13

iii

# Índice de figuras

4.1. IDE Thonny | 12

iv

# Índice de tablas

v

# 1. Introducción

El panorama en constante cambio de la industria del cannabis medicinal ha generado una creciente necesidad de optimizar los métodos de cultivo para garantizar la consistencia y calidad de los productos. En este contexto, el Internet de las cosas (IoT) emerge como una herramienta clave para transformar la gestión de invernaderos, permitiendo una monitorización en tiempo real y decisiones informadas por parte de los agricultores.

Este trabajo se centra en el diseño de un sistema asequible de monitorización basado en IoT para invernaderos de cannabis medicinal. La elección de hardware, liderada por la Raspberry Pi Pico W como unidad central, se fundamenta en la capacidad de esta plataforma para equilibrar eficiencia y costos. Sensores especializados, como el DHT22 para temperatura y humedad, el BH1750 para intensidad lumínica, y un sensor de humedad de suelo, complementan la infraestructura del sistema.

Más allá de la mejora en la eficiencia del cultivo de cannabis medicinal, este proyecto busca situarse en la vanguardia de la agricultura inteligente y sostenible. La combinación de IoT con prácticas agrícolas avanzadas tiene el potencial de transformar radicalmente la forma en que se gestionan los cultivos, promoviendo la sostenibilidad y ofreciendo una solución práctica para agricultores de diversos niveles de recursos.

En resumen, este trabajo se adentra en el diseño de un sistema completo y accesible para la monitorización de invernaderos, utilizando la innovación tecnológica como catalizador para mejorar la calidad de los cultivos y contribuir al avance de la agricultura moderna.

1

# 2. Objetivos del proyecto

## 2.1. Objetivos del Software

Desarrollo del Sistema de Adquisición de Datos: Implementar un sistema eficiente de adquisición de datos que pueda recopilar información precisa proveniente de los sensores (DHT22, BH1750, sensor de humedad de suelo) instalados en el invernadero.

Diseño de la Interfaz de Usuario: Desarrollar una interfaz de usuario intuitiva y fácil de usar, que permita a los usuarios visualizar en tiempo real los datos recopilados y tomar decisiones informadas sobre el control del entorno del invernadero.

Implementación de Protocolos de Comunicación: Establecer protocolos de comunicación eficientes para la transmisión de datos entre los sensores y la Raspberry Pi Pico W, así como para la conexión con otros dispositivos o sistemas externos si es necesario.

3

4 | Objetivos del proyecto

## 2.2. Objetivos Técnicos

| Integración de Hardware: Seleccionar, configurar e integrar de manera óptima el hardware necesario (Raspberry Pi Pico W, pantalla OLED 128x64, sensores) para garantizar la estabilidad y la eficacia

del sistema.

| Eficiencia Energética: Implementar estrategias de programación y configuración de hardware que optimicen el consumo de energía, asegurando una operación sostenible del sistema en entornos con recursos limitados. Precisamente la Raspberry Pi Pico W es conocida

por su bajo consumo energético.

| Validación en Entorno Real: Realizar pruebas exhaustivas del sistema en un entorno de cultivo de cannabis medicinal real, evaluando su rendimiento, confiabilidad y adaptabilidad a condiciones variables.
| Consideraciones Económicas: Evaluar y optimizar los costos aso- ciados al desarrollo e implementación del sistema, garantizando la viabilidad económica para agricultores de diferentes escalas y recursos.
| Documentación Completa: Generar una documentación detallada que abarque el diseño, la implementación y la configuración del sistema, facilitando la comprensión y la replicación por parte de otros interesa- dos. Estos objetivos, tanto del software como técnicos, se plantean con el propósito de cumplir con los requisitos del proyecto y garantizar la efectividad y utilidad del sistema de monitorización propuesto para

invernaderos de cannabis medicinal.

# 3. Conceptos teóricos

## 3.1. Internet de las cosas (IoT)

El Internet de las cosas (IoT) se refiere a la red de dispositivos físicos que están integrados con tecnología, software, sensores y conectividad de red para recopilar y compartir datos. Estos dispositivos, también llamados objetos inteligentes o dispositivos conectados, pueden interactuar entre sí y con sistemas informáticos en red para realizar tareas específicas, recopilar información y ofrecer funcionalidades avanzadas.

Características clave del IoT:

Conectividad: Los dispositivos IoT están equipados con tecnologías de comunicación, como Wi-Fi, Bluetooth, Zigbee o incluso 5G, que les permiten conectarse a redes y compartir datos.

Sensores y Actuadores: Los dispositivos IoT suelen estar equipados con sensores para recopilar datos del entorno circundante. Además, algunos dispositivos también incorporan actuadores que les permiten realizar acciones físicas en respuesta a comandos.

Inteligencia y Procesamiento de Datos: Muchos dispositivos IoT cuentan con capacidad de procesamiento local o dependen de la nube para analizar y procesar datos recopilados. La inteligencia artificial y el aprendizaje automático también se aplican para extraer información significativa de grandes conjuntos de datos.

Interconexión: La capacidad de interconectar dispositivos IoT permite que trabajen juntos de manera coordinada, compartiendo información y actuando en función de datos colectivos.

5

6 | Conceptos teóricos
| Aplicaciones Diversas: El IoT se aplica en una amplia variedad de campos, como la agricultura inteligente, la salud, la domótica, la indus- tria manufacturera, la logística y más. Esto permite la automatización

y mejora de procesos en diversas industrias.

| Seguridad y Privacidad: Dado que los dispositivos IoT manejan datos sensibles, la seguridad y la privacidad son aspectos críticos. Se implementan medidas de seguridad para proteger la integridad y la confidencialidad de los datos transmitidos y almacenados.
| El Internet de las cosas tiene un impacto significativo en la forma en que interactuamos con el entorno, mejorando la eficiencia, la toma de decisiones y la calidad de vida. A medida que la tecnología avanza, el alcance y la influencia del IoT continúan expandiéndose, creando un

ecosistema cada vez más interconectado.

## 3.2. Raspberry Pi Pico W

| La Raspberry Pi Pico W [5] es una placa de desarrollo de bajo costo
que combina versatilidad y conectividad inalámbrica. Se elige como unidad central para el sistema, actuando como el cerebro que controla y coordina la recopilación y transmisión de datos.

## 3.3. MicroPython

| MicroPython [1] es una implementación del lenguaje de programación
Python diseñada para sistemas embebidos y microcontroladores como la Raspberry Pi Pico W. Permite una programación sencilla y eficiente de la unidad central, facilitando el desarrollo de aplicaciones en entornos limitados.

## 3.4. GPIO

| GPIO [4], por sus siglas en inglés, General Purpose Input/Output, se
refiere a los pines de propósito general presentes en microcontroladores y sistemas embebidos. Estos pines son versátiles y pueden configurarse tanto como entradas como salidas, permitiendo la interacción del microcontrolador con el entorno externo.
| Entradas (Input): En modo de entrada, un pin GPIO puede recibir señales eléctricas del exterior, como las provenientes de sensores o

3.5. SENSORES (DHT22, BH1750, SENSOR DE HUMEDAD DE SUELO)7

interruptores. Estos pines detectan y leen el estado de la señal, que puede ser alto (1) o bajo (0), dependiendo de la presencia de voltaje.

Salidas (Output): En modo de salida, un pin GPIO puede enviar señales eléctricas al exterior, como las necesarias para controlar actuadores, LEDs u otros dispositivos. El microcontrolador puede controlar el estado del pin, estableciendo un voltaje alto o bajo según sea necesario.

La flexibilidad de los pines GPIO permite a los desarrolladores adaptar el comportamiento del microcontrolador a una amplia variedad de aplicaciones. La manipulación directa de estos pines a través de código facilita la interconexión con componentes externos y la implementación de funciones específicas en proyectos de hardware. En el contexto de la Raspberry Pi Pico W [5] y otros dispositivos similares, la gestión de los pines GPIO es esencial para controlar y coordinar la interacción con sensores, actuadores y otros periféricos.

## 3.5. Sensores (DHT22, BH1750, Sensor de Humedad de Suelo)

Los sensores seleccionados desempeñan roles cruciales en la monitorización del entorno del invernadero. El DHT22 [14] mide la temperatura y humedad ambiente, el BH1750 [6] evalúa la intensidad lumínica, y el sensor de humedad de suelo [2] monitorea las condiciones de la tierra.

## 3.6. Interfaz de Usuario

La interfaz de usuario proporciona una plataforma visual para la interpretación de datos recopilados. Su diseño debe ser intuitivo, permitiendo acceder y comprender fácilmente la información relevante sobre el estado del invernadero.

## 3.7. Protocolos de Comunicación

Los protocolos de comunicación son conjuntos de reglas y estándares que especifican cómo los dispositivos deben intercambiar información entre sí. Estos protocolos definen el formato, la secuencia y el significado de los mensajes que se envían y reciben, facilitando la comunicación efectiva

8 | Conceptos teóricos

entre sistemas o dispositivos electrónicos. Los protocolos son esenciales para garantizar la interoperabilidad y la correcta transmisión de datos en entornos tecnológicos diversos.

| Existen diferentes tipos de protocolos de comunicación, cada uno diseñado
para propósitos específicos y adaptado a diferentes situaciones. Algunos ejemplos comunes incluyen:
| Protocolos de Red: Estos protocolos se utilizan para la transmisión de datos a través de redes de computadoras. Ejemplos incluyen el Protocolo de Internet (IP) para direccionamiento y enrutamiento, y el Protocolo de Control de Transmisión (TCP) para la gestión de

conexiones fiables.

| Protocolos de Comunicación Inalámbrica: Para la comunicación sin cables, existen protocolos específicos como el estándar IEEE 802.11 (Wi-Fi) [8] para redes inalámbricas y el Bluetooth para la conexión de

dispositivos cercanos.

| Protocolos de Comunicación Serie: En entornos donde se requiere una comunicación punto a punto, se utilizan protocolos serie como UART (Universal Asynchronous Receiver-Transmitter) [11] y SPI

(Serial Peripheral Interface) [12].

| Protocolos de Comunicación de Periféricos: Para la interconexión de periféricos y componentes electrónicos, se utilizan protocolos como I2C (Inter-Integrated Circuit) y SPI para la transmisión de datos entre

microcontroladores, sensores y otros dispositivos.

| Protocolos de Aplicación: Estos protocolos se centran en la comu- nicación a nivel de aplicación y pueden incluir estándares como HTTP (Hypertext Transfer Protocol) [3] para la transmisión de datos en la web y MQTT (Message Queuing Telemetry Transport) [13] para la

comunicación en el Internet de las cosas (IoT).

| En cuanto a normativas, algunas organizaciones como el IEEE (Instituto
de Ingenieros Eléctricos y Electrónicos) [10] establecen estándares para varios protocolos de comunicación, garantizando la consistencia y la interoperabilidad en la industria. Por ejemplo, el IEEE 802.3 [9] define estándares para Ethernet, mientras que el IEEE 802.15 [7] se centra en protocolos para redes inalámbricas de área personal (WPAN), como Bluetooth. Estas normativas son esenciales para la creación de sistemas y dispositivos que puedan comunicarse de manera efectiva y sin problemas.

3.8. WIFI | 9

## 3.8. WiFi

Wi-Fi, derivado de "Wireless Fidelity,.es una tecnología de comunicación inalámbrica que permite la conexión de dispositivos electrónicos a una red local o a Internet sin necesidad de cables físicos. Esta tecnología utiliza ondas de radio para la transmisión de datos entre dispositivos compatibles, siguiendo los estándares establecidos por el Instituto de Ingenieros Eléctricos y Electrónicos (IEEE), específicamente dentro de la familia de normas 802.11.

La norma IEEE 802.11 [8] abarca diversas versiones, cada una con mejoras y características específicas. Por ejemplo, las variantes más comunes incluyen 802.11a, 802.11b, 802.11g, 802.11n, 802.11ac, y 802.11ax. Cada una de estas normas define aspectos técnicos como la velocidad de transmisión, el rango de frecuencias utilizadas, y las características de seguridad.

La conexión a una red Wi-Fi implica que los dispositivos inalámbricos cumplen con estas normas para garantizar una comunicación eficiente y segura. Los routers Wi-Fi, que actúan como puntos de acceso, son fundamentales para establecer y gestionar estas conexiones inalámbricas, permitiendo que múltiples dispositivos se conecten y compartan recursos en un área determinada.

# 4. Técnicas y herramientas

A lo largo del desarrollo del proyecto, se han empleado diversas tecnologías, herramientas y elementos esenciales que requieren familiaridad antes de avanzar en la ejecución del proyecto. La elección de estas opciones en lugar de otras se basa en una evaluación detallada, la cual queda documentada en esta sección con el propósito de brindar una justificación fundamentada.

## 4.1. Entorno Software

Entorno de desarrollo Micropython

Herramientas valoradas: Thonny IDE, (https://thonny.org/) Mu Editor, (https://codewith.mu/) Upycraft, (https://dfrobot.gitbooks.io/upycraft/content/) Py-Charm. (https://www.jetbrains.com/pycharm/)

Herramienta elegida: Thonny IDE. (https://thonny.org/)

Thonny IDE se presenta como la opción más idónea, proporcionando una combinación de simplicidad, integración nativa con MicroPython, herramientas de depuración eficaces y un sólido soporte comunitario, todo lo cual contribuye a un entorno de desarrollo eficiente y centrado en el usuario para la programación en la Raspberry Pi Pico W con MicroPython.

11

12 | Técnicas y herramientas


Figura 4.1: IDE Thonny.

# Bibliografía

[1] Equipo de Desarrollo de MicroPython. Micropython documentation, 1 2024. https://github.com/micropython/micropython/wiki.
[2] DFROBOT. Capacitive soil moisture sensor, 1 2024. https://wiki.dfrobot.com/Capacitive_Soil_Moisture_Sensor_SKU_SEN0193. (https://wiki.dfrobot.com/Capacitive_Soil_Moisture_Sensor_SKU_SEN0193)
[3] Gettys J. Mogul J. Frystyk H. Masinter L. Leach P. & Berners-Lee
T. (1999) Fielding, R. Hypertext Transfer Protocol – HTTP/1.1, 1999. https://www.ietf.org/rfc/rfc2616.txt.
[4] Raspberry Pi Foundation. | Gpio, 1 2024. | https://projects.
raspberrypi.org/en/projects/physical-computing/1. (https://projects.raspberrypi.org/en/projects/physical-computing/1)
[5] Raspberry Pi Foundation. Raspberry pi pico w, 1 2024. https://www.raspberrypi.com/documentation/microcontrollers/raspberrypi-pico.html#raspberry-pi-pico-w. (https://www.raspberrypi.com/documentation/microcontrollers/raspberry-pi-pico.html)
[6] Handsontec. | BH1750 Ambient Light Sensor Module. | https:
//www.handsontec.com/dataspecs/sensor/BH1750%20Light% 20Sensor.pdf. (https://www.handsontec.com/dataspecs/sensor/BH1750%20Light%20Sensor.pdf)
[7] IEEE. Ieee 802.15 working group for wireless specialty networks (wsn). https://www.ieee802.org/15/.
[8] IEEE. Normativa IEEE802.11. https://standards.ieee.org/ieee/802.11/5536/. (https://standards.ieee.org/ieee/802.11/5536/)
[9] IEEE. Ieee 802.3 ethernet working group, 7 2023. https://www.ieee802.org/3/.

13

14 | BIBLIOGRAFÍA
[10] IEEE. History of ieee, 1 2024. https://www.ieee.org/about/ieeehistory.html. (https://www.ieee.org/about/ieee-history.html)
[11] IEEEXPLORE. Analysis of UART Communication Protocol. https: //ieeexplore.ieee.org/document/9936199.
[12] IEEEXPLORE. An introduction to I2C and SPI protocols. https: //ieeexplore.ieee.org/document/4762946.
[13] IEEEXPLORE. MQTT Protocol: Fundamentals, Tools and Future
| Directions. https://ieeexplore.ieee.org/document/8931137.
[14] Sparkfun. DHT22 Digital-output relative humidity & temperature
| sensor/module. https://www.sparkfun.com/datasheets/Sensors/
Temperature/DHT22.pdf. (https://www.sparkfun.com/datasheets/Sensors/Temperature/DHT22.pdf)

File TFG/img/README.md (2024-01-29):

# Ubicación de las imágenes en el proyecto

1. Diagramas
    * [Hardware](../../../Hardware/img)

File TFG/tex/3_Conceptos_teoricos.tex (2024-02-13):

\capitulo{3}{Conceptos teóricos}

%En aquellos proyectos que necesiten para su comprensión y desarrollo de unos conceptos teóricos de una determinada materia o de un determinado dominio de conocimiento, debe existir un apartado que sintetice dichos conceptos.

%Algunos conceptos teóricos de \LaTeX{} \footnote{Créditos a los proyectos de Álvaro López Cantero: Configurador de Presupuestos y Roberto Izquierdo Amo: PLQuiz}.

%\section{Referencias}
%Las referencias se incluyen en el texto usando cite~\cite{wiki:latex}. Para citar webs, artículos o libros~\cite{koza92}, si se desean citar más de uno en el mismo lugar~\cite{bortolot2005, koza92}.

%\imagen{escudoInfor}{Autómata para una expresión vacía}{.5} %imagenes
	
%\section{Tablas}
%Igualmente se pueden usar los comandos específicos de \LaTeX o bien usar alguno de los comandos de la plantilla.
%\tablaSmall{Herramientas y tecnologías utilizadas en cada parte del proyecto}{l c c c c}{herramientasportipodeuso}
%{ \multicolumn{1}{l}{Herramientas} & App AngularJS & API REST & BD & Memoria \\}{ 
%HTML5 & X & & &\\
%CSS3 & X & & &\\
%BOOTSTRAP & X & & &\\
%JavaScript & X & & &\\
%AngularJS & X & & &\\
%Bower & X & & &\\
%PHP & & X & &\\
%Karma + Jasmine & X & & &\\
%Slim framework & & X & &\\
%Idiorm & & X & &\\
%Composer & & X & &\\
%JSON & X & X & &\\
%PhpStorm & X & X & &\\
%MySQL & & & X &\\
%PhpMyAdmin & & & X &\\
%Git + BitBucket & X & X & X & X\\
%Mik\TeX{} & & & & X\\
%\TeX{}Maker & & & & X\\
%Astah & & & & X\\
%Balsamiq Mockups & X & & &\\
%VersionOne & X & X & X & X\\
%} 
\section{Internet de las cosas (IoT)}
El Internet de las cosas (IoT) se refiere a la red de dispositivos físicos que están integrados con tecnología, software, sensores y conectividad de red para recopilar y compartir datos. Estos dispositivos, también llamados \textbf{objetos inteligentes}  o \textbf{dispositivos conectados}, pueden interactuar entre sí y con sistemas informáticos en red para realizar tareas específicas, recopilar información y ofrecer funcionalidades avanzadas.

Características clave del IoT:
\begin{itemize}
\item \textbf{Conectividad:}
Los dispositivos IoT están equipados con tecnologías de comunicación, como Wi-Fi, Bluetooth, Zigbee o incluso 5G, que les permiten conectarse a redes y compartir datos.

\item \textbf{Sensores y Actuadores:}
Los dispositivos IoT suelen estar equipados con sensores para recopilar datos del entorno circundante. Además, algunos dispositivos también incorporan actuadores que les permiten realizar acciones físicas en respuesta a comandos.

\item \textbf{Inteligencia y Procesamiento de Datos:}
Muchos dispositivos IoT cuentan con capacidad de procesamiento local o dependen de la nube para analizar y procesar datos recopilados. La inteligencia artificial y el aprendizaje automático también se aplican para extraer información significativa de grandes conjuntos de datos.

\item \textbf{Interconexión:}
La capacidad de interconectar dispositivos IoT permite que trabajen juntos de manera coordinada, compartiendo información y actuando en función de datos colectivos.

\item \textbf{Aplicaciones Diversas:}
El IoT se aplica en una amplia variedad de campos, como la agricultura inteligente, la salud, la domótica, la industria manufacturera, la logística y más. Esto permite la automatización y mejora de procesos en diversas industrias.

\item \textbf{Seguridad y Privacidad:}
Dado que los dispositivos IoT manejan datos sensibles, la seguridad y la privacidad son aspectos críticos. Se implementan medidas de seguridad para proteger la integridad y la confidencialidad de los datos transmitidos y almacenados.

El Internet de las cosas tiene un impacto significativo en la forma en que interactuamos con el entorno, mejorando la eficiencia, la toma de decisiones y la calidad de vida. A medida que la tecnología avanza, el alcance y la influencia del IoT continúan expandiéndose, creando un ecosistema cada vez más interconectado.
\end{itemize}
\section{GPIO}\label{concepto:GPIO}
GPIO~\cite{misc:gpio}, por sus siglas en inglés, General Purpose Input/Output, se refiere a los pines de propósito general presentes en microcontroladores y sistemas embebidos. Estos pines son versátiles y pueden configurarse tanto como entradas como salidas, permitiendo la interacción del microcontrolador con el entorno externo.
\begin{itemize}
	\item \textbf{Entradas (Input):} En modo de entrada, un pin GPIO puede recibir señales eléctricas del exterior, como las provenientes de sensores o interruptores. Estos pines detectan y leen el estado de la señal, que puede ser alto (1) o bajo (0), dependiendo de la presencia de voltaje.

	\item \textbf{Salidas (Output):} En modo de salida, un pin GPIO puede enviar señales eléctricas al exterior, como las necesarias para controlar actuadores, LEDs u otros dispositivos. El microcontrolador puede controlar el estado del pin, estableciendo un voltaje alto o bajo según sea necesario.
\end{itemize}
La flexibilidad de los pines GPIO permite a los desarrolladores adaptar el comportamiento del microcontrolador a una amplia variedad de aplicaciones. La manipulación directa de estos pines a través de código facilita la interconexión con componentes externos y la implementación de funciones específicas en proyectos de hardware. En el contexto de la Raspberry Pi Pico W~\cite{misc:RPiPicoW} y otros dispositivos similares, la gestión de los pines GPIO es esencial para controlar y coordinar la interacción con sensores, actuadores y otros periféricos.

\section{Interfaz de Usuario}
La interfaz de usuario proporciona una plataforma visual para la interpretación de datos recopilados. Su diseño debe ser intuitivo, permitiendo acceder y comprender fácilmente la información relevante sobre el estado del invernadero.

\section{Protocolos de Comunicación}
Los protocolos de comunicación son conjuntos de reglas y estándares que especifican cómo los dispositivos deben intercambiar información entre sí. Estos protocolos definen el formato, la secuencia y el significado de los mensajes que se envían y reciben, facilitando la comunicación efectiva entre sistemas o dispositivos electrónicos. Los protocolos son esenciales para garantizar la interoperabilidad y la correcta transmisión de datos en entornos tecnológicos diversos.

Existen diferentes tipos de protocolos de comunicación, cada uno diseñado para propósitos específicos y adaptado a diferentes situaciones. Algunos ejemplos comunes incluyen:
\begin{itemize}
\item \textbf{Protocolos de Red}:
Estos protocolos se utilizan para la transmisión de datos a través de redes de computadoras. Ejemplos incluyen el Protocolo de Internet (IP) para direccionamiento y enrutamiento, y el Protocolo de Control de Transmisión (TCP) para la gestión de conexiones fiables.

\item \textbf{Protocolos de Comunicación Inalámbrica:}
	Para la comunicación sin cables, existen protocolos específicos como el estándar IEEE 802.11 (Wi-Fi)~\cite{manual:IEEE802.11} para redes inalámbricas y el Bluetooth para la conexión de dispositivos cercanos.

\item \textbf{Protocolos de Comunicación Serie:}
	En entornos donde se requiere una comunicación punto a punto, se utilizan protocolos serie como UART (Universal Asynchronous Receiver-Transmitter)~\cite{manual:UART} y SPI (Serial Peripheral Interface)~\cite{manual:SPI-I2C}.

\item \textbf{Protocolos de Comunicación de Periféricos:}
Para la interconexión de periféricos y componentes electrónicos, se utilizan protocolos como I2C (Inter-Integrated Circuit) y SPI para la transmisión de datos entre microcontroladores, sensores y otros dispositivos.

\item \textbf{Protocolos de Aplicación:}
	Estos protocolos se centran en la comunicación a nivel de aplicación y pueden incluir estándares como HTTP (Hypertext Transfer Protocol)~\cite{manual:HTTP} para la transmisión de datos en la web y MQTT (Message Queuing Telemetry Transport)~\cite{manual:MQTT} para la comunicación en el Internet de las cosas (IoT).
\end{itemize}

En cuanto a normativas, algunas organizaciones como el IEEE (Instituto de Ingenieros Eléctricos y Electrónicos)~\cite{misc:IEEE} establecen estándares para varios protocolos de comunicación, garantizando la consistencia y la interoperabilidad en la industria. Por ejemplo, el IEEE 802.3 ~\cite{misc:IEEE802_3} define estándares para Ethernet, mientras que el IEEE 802.15 ~\cite{misc:IEEE802_15} se centra en protocolos para redes inalámbricas de área personal (WPAN), como Bluetooth. Estas normativas son esenciales para la creación de sistemas y dispositivos que puedan comunicarse de manera efectiva y sin problemas.

\section{WiFi}\label{concepto:WIFI}
Wi-Fi, derivado de \textbf{Wireless Fidelity}, es una tecnología de comunicación inalámbrica que permite la conexión de dispositivos electrónicos a una red local o a Internet sin necesidad de cables físicos. Esta tecnología utiliza ondas de radio para la transmisión de datos entre dispositivos compatibles, siguiendo los estándares establecidos por el Instituto de Ingenieros Eléctricos y Electrónicos (IEEE), específicamente dentro de la familia de normas 802.11.

La norma \underline{IEEE 802.11}~\cite{manual:IEEE802.11} abarca diversas versiones, cada una con mejoras y características específicas. Por ejemplo, las variantes más comunes incluyen 802.11a, 802.11b, 802.11g, 802.11n, 802.11ac, y 802.11ax. Cada una de estas normas define aspectos técnicos como la velocidad de transmisión, el rango de frecuencias utilizadas, y las características de seguridad.
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

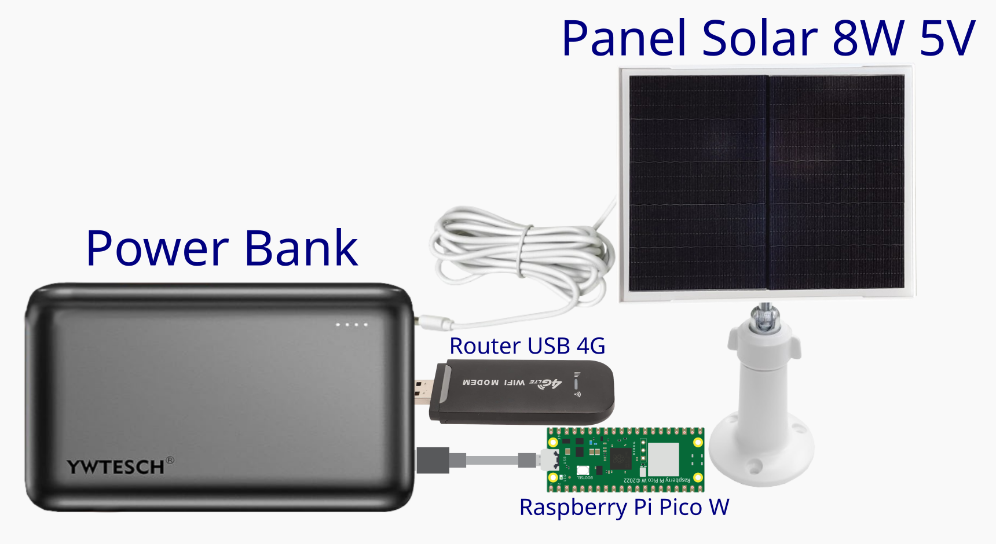
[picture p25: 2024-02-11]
TFG/img/diagramas/panel_solar_alimentacionHardware.png

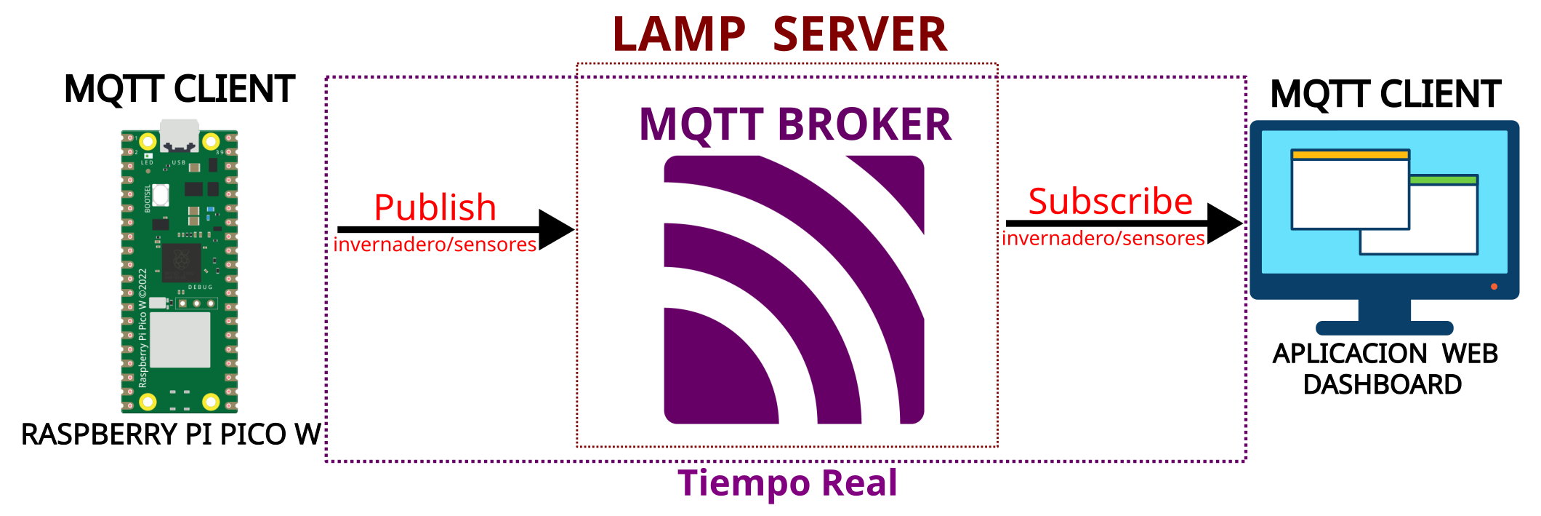
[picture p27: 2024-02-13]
TFG/img/diagramas/mqtt_dashboard_TiempoReal.png

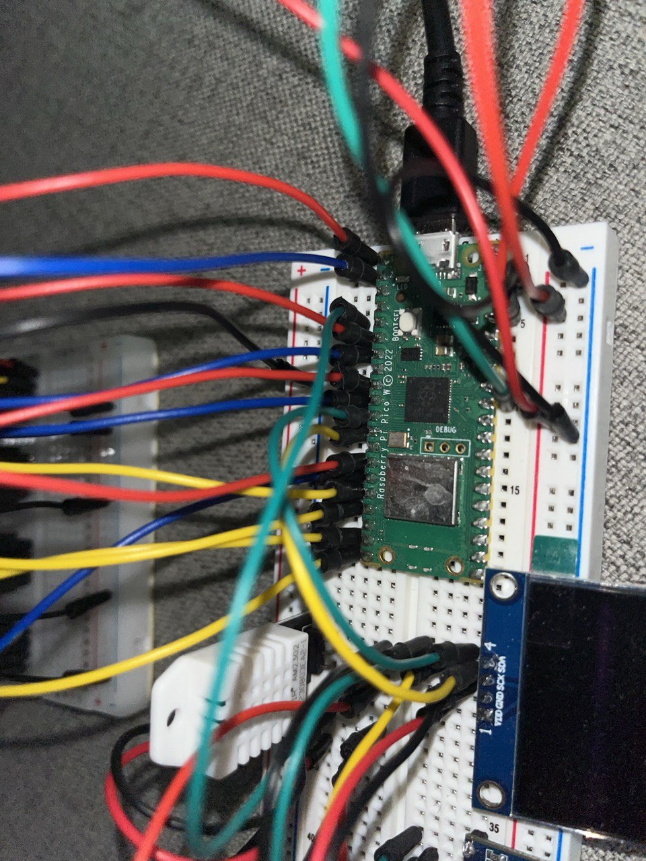
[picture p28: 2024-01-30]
TFG/img/fotos/foto-2.jpg

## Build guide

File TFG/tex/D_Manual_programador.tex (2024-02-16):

\apendice{Documentación técnica de programación}

\section{Introducción}

En esta sección encontrarás información detallada sobre la estructura del código. Esta documentación está diseñada para brindar claridad y orientación a los desarrolladores, facilitando el mantenimiento, la expansión y la comprensión del código fuente del proyecto.

\section{Estructura de directorios}
Cada parte del proyecto está contenido en una carpeta.

\begin{table}[htbp]
\begin{center}
\caption{Directorios que contienen partes del proyecto.}
\begin{tabular}{|l|l|} %|c|c|
\hline
\rowcolor[HTML]{C0C0C0} 
\textbf{Carpeta} & \textbf{Descripción}\\ \hline
Hardware &  Implementación del harware\\ \hline
nodeMqtt & Servicio para almacenar datos en una base de datos \\ \hline
InverIoT &  Aplicación de escritorio\\ \hline
dashboard &  Dashboard web accesible desde internet \\ \hline
AnalisisDatos & Limpieza de datos y resumen estadístico \\ \hline
TFG & Documentación del proyecto \\ \hline
\end{tabular}
\end{center}
\end{table}

\subsection{Hardware}
Contiene detalles de las conexiones y código de programación en Micropython~\cite{wiki:micropython}.

El directorio \textbf{fritzing}~\ref{tabla:fritzing} contiene los esquemas de conexiones entre la Raspberry Pi Pico W, los módulos, sensores y leds RGB.

El directorio \textbf{micropython}~\ref{tabla:micropython} contiene el código de programación para controlar el hardware.

Respecto al directorio \textbf{lib}~\ref{tabla:lib} los archivos que empiezan con "mi\_" son implementaciones mías que hizo posible reducir la cantidad de líneas de código de programación en el archivo \textbf{main.py}.

\begin{figure}[h]
\centering
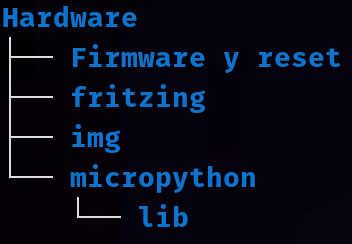
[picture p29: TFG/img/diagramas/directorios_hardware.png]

\caption{Rama de directorios de hardware.}
\end{figure}

\begin{table}[htbp]
\begin{center}
\caption{Directorio: Firmware y reset.}
\begin{tabular}{|l|l|} %|c|c|
\hline
\rowcolor[HTML]{C0C0C0} 
\textbf{Nombre de Archivo} & \textbf{Descripción}\\ \hline
flash\_nuke.uf2 & Firmware para configuración de fábrica\\ \hline
RPI\_PICO\_W-20240105-v1.22.1.uf2 & Firmware oficial de la RPI PICO W\\ \hline
\end{tabular}
\end{center}
\end{table}

\begin{table}[htbp]
\begin{center}
	\caption{Directorio: Fritzing.}
\begin{tabular}{|l|} %|c|c|
\hline
\rowcolor[HTML]{C0C0C0} 
\textbf{Nombre de Archivo}\\ \hline
BH1750.fzz  \\ \hline
conexiones.fzz  \\ \hline
DHT22\_humedad\_temperatura.fzz  \\ \hline
leds\_rgb.fzz  \\ \hline
oled\_i2c\_168x64.fzz  \\ \hline
Sensor\_humedad\_suelo.fzz \\ \hline
\end{tabular}
\label{tabla:fritzing}
\end{center}
\end{table}

\begin{table}[htbp]
\begin{center}
\caption{Directorio: micropython.}
\begin{tabular}{|l|l|} %|c|c|
\hline
\rowcolor[HTML]{C0C0C0} 
\textbf{Nombre de Archivo} & \textbf{Descripción}\\ \hline
boot.py & Se ejecuta al prender la RPI PICO W.\\ \hline
config.py & Configuración wifi, mqtt, etc.\\ \hline
lib & librerías y funciones implementadas\\ \hline
main.py & Programa principal\\ \hline
\end{tabular}
\label{tabla:micropython}
\end{center}
\end{table}

\begin{table}[htbp]
\begin{center}
\caption{Directorio: lib.}
\begin{tabular}{|l|l|} %|c|c|
\hline
\rowcolor[HTML]{C0C0C0} 
\textbf{Nombre de Archivo} & \textbf{Descripción}\\ \hline
bh1750.py & librería para sensor BH1750~\cite{manual:BH1750}\\ \hline
dht.py & librería para sensor DHT22~\cite{manual:DHT22} \\ \hline
mi\_modulos.py & Mi implementación para pantalla oled y leds RGB\\ \hline
mi\_mqtt.py & Mi implementación para MQTT \\ \hline
mi\_sensores.py & Mi implementación para sensores\\ \hline
mi\_telegram.py & Mi implementación para bot de Telegram\\ \hline
mi\_wifi.py & Mi implementación para conectarse al wifi\\ \hline
sh1106.py & librería para pantalla oled~\cite{manual:Oled}\\ \hline
umqtt.py & librería para MQTT~\cite{misc:umqtt}\\ \hline
utelegram.py & librería para bot de Telegram~\cite{misc:Telegram_bots}\\ \hline
\end{tabular}
\label{tabla:lib}
\end{center}
\end{table}

\subsection{nodeMqtt}
NodeMtt recopila los datos mediante MQTT y los almacena en una base de datos Mysql~\cite{misc:Mysql}.

El directorio \textbf{nodeMqtt} no contiene subdirectorios dentro pero contiene los archivos indicados en la tabla~\ref{tabla:directorioNodeMqtt}.

%\begin{figure}[h]
%\centering
%\includegraphics[width=0.7\textwidth]{img/diagramas/directorios_nodeMqtt.png}
%\caption{No tiene rama de directorios de nodeMqtt.}
%\end{figure}

\begin{table}[htbp]
\begin{center}
\caption{Directorio: nodeMqtt.}
\begin{tabular}{|l|l|} %|c|c|
\hline
\rowcolor[HTML]{C0C0C0} 
\textbf{Nombre de Archivo} & \textbf{Descripción}\\ \hline
index.js & Archivo javascript principal\\ \hline
package.json & Información de dependencias\\ \hline
\end{tabular}
\label{tabla:directorioNodeMqtt}
\end{center}
\end{table}

\subsection{InverIoT}
Es una Aplicación de escritorio para el sismtema operativo Windows.

Fue desarrollada usando el lenguaje de programación C\#, permite ver los datos en tiempo real, el histórico de datos y activar mecanismos (representado por la activación de un led verde).

La obtención de datos en tiempo real y las órdenes para activar mecanismos se hace por medio de MQTT~\cite{manual:MQTT}.

La obtención del histórico de datos se hace por medio del protocolo Mysql.

\begin{figure}[h]
\centering
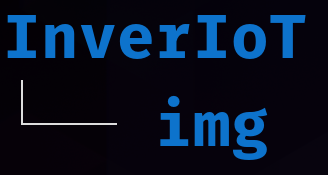
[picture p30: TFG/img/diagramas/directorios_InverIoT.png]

\caption{Rama de directorios de InverIoT.}
\end{figure}

\begin{table}[htbp]
\begin{center}
	\caption{Directorio: InverIoT.}
\begin{tabular}{|l|} %|c|c|
\hline
\rowcolor[HTML]{C0C0C0} 
\textbf{Nombre de Archivo}\\ \hline
favicon.ico \\ \hline
frmGraficas.cs \\ \hline
frmGraficas.Designer.cs \\ \hline
frmGraficas.resx  \\ \hline
frmHistorico.cs  \\ \hline
frmHistorico.Designer.cs  \\ \hline
frmHistorico.resx  \\ \hline
frmMain.cs  \\ \hline
frmMain.Designer.cs  \\ \hline
frmMain.es-ES.resx  \\ \hline
frmMain.resx  \\ \hline
Funciones.cs  \\ \hline
img  \\ \hline
'Instalador - InverIoT - v2.2.exe'  \\ \hline
InverIoT.csproj  \\ \hline
InverIoT.sln  \\ \hline
Program.cs  \\ \hline
README.md  \\ \hline
\end{tabular}
\label{tabla:directorioInverIoT}
\end{center}
\end{table}

\subsection{dashboard}
Este dashboard web permite acceder a los datos en tiempo real y también ver el histórico de datos. No envía ordenes, solo recepciona datos mediante MQTT~\cite{manual:MQTT} y Mysql~\cite{misc:Mysql}.

\begin{figure}[h]
\centering
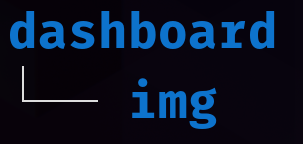
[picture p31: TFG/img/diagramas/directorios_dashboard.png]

\caption{Rama de directorios de dashboard.}
\end{figure}

\begin{table}[htbp]
\begin{center}
\caption{Directorio: dashboard.}
\begin{tabular}{|l|l|} %|c|c|
\hline
\rowcolor[HTML]{C0C0C0} 
\textbf{Nombre de Archivo} & \textbf{Descripción}\\ \hline
android-chrome-192x192.png & Ícono\\ \hline
android-chrome-512x512.png & Ícono\\ \hline
apple-touch-icon.png & Ícono\\ \hline
favicon-16x16.png & Ícono\\ \hline
favicon-32x32.png & Ícono\\ \hline
favicon.ico & Ícono\\ \hline
historico.html & Estructura visual del historial\\ \hline
img & Imágenes del dashboard funcionando\\ \hline
index.html & Estructura visual por defecto\\ \hline
package.json & Dependencias y configuraciones\\ \hline
servers.js & Hace funcionar el dashboard\\ \hline
site.webmanifest & Manifiesto web\\ \hline
\end{tabular}
\label{tabla:directorioDashboard}
\end{center}
\end{table}

\subsection{AnalisisDatos}
Limpia los datos y da un resumen estadístico usando Jupyter Notebook~\cite{misc:Jupyter_Notebook} y el lenguaje de programación Python.

El archivo \textbf{analisis.ipynb} contiene todo el código de programación utilizado en el proceso. 

El archivo \textbf{data.csv} es solo una muestra representativa de los datos, los cuales siguen creciendo conforme siga en funcionamiento el sistema.

La librería de python que principalmente fue usada es \textbf{pandas}.

La recopilación de datos abrirá otras posibilidades de investigación para futuros análisis usando herramientas como machine learning. Por ahora solo nos centramos en almacenar los datos y ver las anomalías que puedan surgir antes de hacer un análisis, es decir, respecto a la limpieza de datos.

%\begin{figure}[h]
%\centering
%\includegraphics[width=1\textwidth]{img/diagramas/directorios_AnalisisDatos.png}
%\caption{Rama de directorios de AnalisisDatos.}
%\end{figure}

\begin{table}[htbp]
\begin{center}
\caption{Directorio: AnalisisDatos.}
\begin{tabular}{|l|l|} %|c|c|
\hline
\rowcolor[HTML]{C0C0C0} 
\textbf{Nombre de Archivo} & \textbf{Descripción}\\ \hline
analisis.ipynb & Jupyter notebook para analizar datos\\ \hline
data.csv & Data de los sensores\\ \hline
img & Directorio de imágenes \\ \hline
\end{tabular}
\label{tabla:directorioAnalisisDatos}
\end{center}
\end{table}

\subsection{TFG}
Documentación del proyecto usando \LaTeX.

Los archivos principales son \textbf{memoria.tex} y \textbf{anexos.tex} como se puede ver en la tabla~\ref{tabla:TFG}.

\begin{figure}[h]
\centering
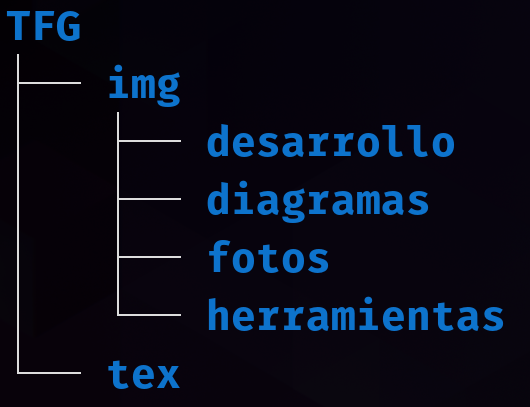
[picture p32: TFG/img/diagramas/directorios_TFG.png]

\caption{descripcion}
\end{figure}

\begin{table}[htbp]
\begin{center}
\caption{Directorio: TFG.}
\begin{tabular}{|l|l|} %|c|c|
\hline
\rowcolor[HTML]{C0C0C0} 
\textbf{Nombre de Archivo} & \textbf{Descripción}\\ \hline
anexos.pdf & PDF de  anexos\\ \hline
anexos.tex & documentación técnica\\ \hline
bibliografiaAnexos.bib & Referencia bibliográficas de anexos.tex\\ \hline
bibliografia.bib & Referencia bibliográficas de memoria.tex\\ \hline
img & directorio de imágenes \\ \hline
memoria.pdf & Resultado de memoria.tex\\ \hline
memoria.tex & Descripción de conceptos y del proyecot en sí\\ \hline
tex & Archivos usados por memoria.tex y anexos.tex\\ \hline
\end{tabular}
\label{tabla:TFG}
\end{center}
\end{table}

\begin{table}[htbp]
\begin{center}
\caption{Directorio: img.}
\begin{tabular}{|l|l|}
\hline
\rowcolor[HTML]{C0C0C0} 
\textbf{Nombre de Archivo} & \textbf{Descripción}\\ \hline
cabecera.pdf & Cabecera con el nombre de la universidad\\ \hline
desarrollo & Imágenes que representan el proceso\\ \hline
diagramas & Esquemas del hardware y diagramas\\ \hline
escudoInfor.pdf & Escudo de la universidad\\ \hline
fotos & Fotos relacionadas al proyecto\\ \hline
herramientas & Imágenes de herramientas usadas\\ \hline
\end{tabular}
\end{center}
\end{table}

\begin{table}[htbp]
\begin{center}
\caption{Directorio: tex.}
\begin{tabular}{|l|}
\hline
\rowcolor[HTML]{C0C0C0} 
\textbf{Nombre de Archivo} \\ \hline
1\_Introduccion.tex \\ \hline
2\_Objetivos\_del\_proyecto.tex \\ \hline
3\_Conceptos\_teoricos.tex \\ \hline
4\_Tecnicas\_y\_herramientas.tex \\ \hline
5\_Aspectos\_relevantes\_del\_desarrollo\_del\_proyecto.tex \\ \hline
6\_Trabajos\_relacionados.tex \\ \hline
7\_Conclusiones\_Lineas\_de\_trabajo\_futuras.tex \\ \hline
A\_Plan\_proyecto.tex \\ \hline
B\_Requisitos.tex \\ \hline
C\_Diseno.tex \\ \hline
D\_Manual\_programador.tex \\ \hline
E\_Manual\_usuario.tex \\ \hline
F\_ODS.tex \\ \hline
\end{tabular}
\end{center}
\end{table}

\section{Manual del programador}
Este apartado describe los recursos y las estrategias para el desarrollo del código, incluyendo una explicación detallada de las diferentes partes del proyecto.

Veremos las instalaciones y configuraciones necesarias para todo funcione correctamente, tanto referente a software y hardware.

El usuario final no tiene porque hacer todas estas configuraciones, él solo tendrá que ejecutar ciertas cosas específicas y muy puntuales.

Se va explicar respecto a las partes que conforman la totalidad de este proyecto:

\begin{table}[htbp]
\begin{center}
\caption{Directorio: Totalidad del proyecto.}
\begin{tabular}{|l|l|}
\hline
\rowcolor[HTML]{C0C0C0} 
\textbf{Parte del proyecto} & \textbf{Descripción}\\ \hline
Servidor LAMP & Gestiona la base de datos y MQTT\\ \hline
Hardware &  Implementación del harware\\ \hline
nodeMqtt & Servicio para almacenar datos en una base de datos \\ \hline
InverIoT &  Aplicación de escritorio\\ \hline
dashboard &  Dashboard web accesible desde internet \\ \hline
AnalisisDatos & Limpieza de datos y resumen estadístico \\ \hline
Bot de Telegram & Recibe alertas y envía comandos \\ \hline
\end{tabular}
\label{tabla:totalidadProyectoFuncional}
\end{center}
\end{table}

\subsection{Servidor LAMP}
Se está usando un servidor físico HP Proliant~\cite{misc:HP_ProLiant}, mediante Hyper-V se ha virtualizado el sistema operativo Ubuntu para el servidor. Se ha hecho esto porque el servidor físico tiene como sistema operativo principal a Windows Server.

El servidor LAMP consta principalmente de un sistema operativo Linux, que en este caso es Ubuntu~\cite{misc:Ubuntu}, Apache~\cite{misc:Apache}, Mysql~\cite{misc:Mysql} y PHP.

Adicionalmente se instalaron otros servicios que se vieron necesarios. La instalación en Ubuntu se hace mediante comandos en la terminal. La descripción de servicio instalado se menciona en la tabla~\ref{tabla:serviciosLAMP}.

\begin{table}[htbp]
\begin{center}
\caption{Características del servidor HP ProLiant.}
\begin{tabular}{|l|l|}
\hline
\rowcolor[HTML]{C0C0C0} 
\textbf{Característica} & \textbf{Descripción}\\ \hline
Sistema operativo & Windows Server 2019 Standard\\ \hline
Fabricante & Hewlett Packard Enterprise \\ \hline
Modelo & Hewlett Packard Enterprise x64 Class PC\\ \hline
Procesador & Intel(R) Xeon(R) Silver 4210R CPU @ 2.4GHz 2.39GHz\\ \hline
Memoria instalada (RAM) & 128 GB (128 GB utilizable) \\ \hline
Tipo de sistema & Sistema operativo de 64 bits, procesador x64 \\ \hline
\end{tabular}
\end{center}
\end{table}

\begin{lstlisting}[language=sh, firstnumber=0, basicstyle=\normalsize, caption={Comando para instalar apache2 .}] 
sudo apt install apache2 \end{lstlisting}

\begin{lstlisting}[language=sh, firstnumber=0, basicstyle=\normalsize, caption={Comando para instalar Mysql.}] 
sudo apt install mysql-server \end{lstlisting}

\begin{lstlisting}[language=sh, firstnumber=0, basicstyle=\normalsize, caption={Comando para instalar PHP.}] 
sudo apt install php \end{lstlisting}

\begin{lstlisting}[language=sh, firstnumber=0, basicstyle=\normalsize, caption={Comando para instalar ssh.}] 
sudo apt install ssh \end{lstlisting}

\begin{lstlisting}[language=sh, firstnumber=0, basicstyle=\normalsize, caption={Comando para instalar phpmyadmin.}] 
sudo apt install phpmyadmin \end{lstlisting}

\begin{lstlisting}[language=sh, firstnumber=0, basicstyle=\normalsize, caption={Comando para instalar vsftpd.}] 
sudo apt install vsftpd\end{lstlisting}

\begin{lstlisting}[language=sh, firstnumber=0, basicstyle=\normalsize, caption={Comando para instalar ufw.}] 
sudo apt install ufw\end{lstlisting}

\begin{lstlisting}[language=sh, firstnumber=0, basicstyle=\normalsize, caption={Comando para instalar node.js.}] 
sudo apt install nodejs\end{lstlisting}

\begin{lstlisting}[language=sh, firstnumber=0, basicstyle=\normalsize, caption={Comando para instalar pm2.}] 
sudo apt install pm2\end{lstlisting}

\begin{lstlisting}[language=sh, firstnumber=0, basicstyle=\normalsize, caption={Comando para instalar mosquitto.}] 
sudo apt install mosquitto\end{lstlisting}

\begin{lstlisting}[language=sh, firstnumber=0, basicstyle=\normalsize, caption={Comando para instalar npm.}] 
sudo apt install npm\end{lstlisting}

\begin{lstlisting}[language=sh, firstnumber=0, basicstyle=\normalsize, caption={Comando para instalar express.}] 
sudo apt install express\end{lstlisting}

Ahora usando mysql crearemos la base de datos y tablas correspondientes.

\begin{table}[htbp]
\begin{center}
\caption{Base de datos TFG\_UBU.}
\begin{tabular}{|l|l|} %|c|c|
\hline
\rowcolor[HTML]{C0C0C0} 
\textbf{Nombre de tabla} & \textbf{Descripción}\\ \hline
sensores &  Captura la fecha, hora y valores de sensores\\ \hline
umbrales & Captura los umbrales \\ \hline
\end{tabular}
\label{tabla:BDTFG}
\end{center}
\end{table}

\begin{lstlisting}[language=sh, firstnumber=0, basicstyle=\normalsize, caption={Comando para acceder a Mysql.}] 
sudo mysql\end{lstlisting}

\begin{lstlisting}[language=python, firstnumber=0, basicstyle=\normalsize, caption={Comandos Mysql para crear Database \textbf{TFG\_UBU}.}] 
CREATE DATABASE TFG_UBU;
CREATE USER 'joseluis'@'%' IDENTIFIED BY 'Mipassword';
GRANT ALL ON TFG_UBU.* TO 'joseluis'@'%';
use TFG_UBU;
\end{lstlisting}

\begin{lstlisting}[language=python, firstnumber=0, basicstyle=\normalsize, caption={Comandos Mysql para crear tabla \textbf{umbrales}.}] 
CREATE TABLE `umbrales` (
  `temperatura_minima` float NOT NULL,
  `temperatura_maxima` float NOT NULL,
  `humedad_ambiente_minima` float NOT NULL,
  `humedad_ambiente_maxima` float NOT NULL,
  `luminosidad_minima` float NOT NULL,
  `luminosidad_maxima` float NOT NULL,
  `humedad_suelo_minima` float NOT NULL,
  `humedad_suelo_maxima` float NOT NULL,
  `fecha_actualizacion` timestamp 
  NULL DEFAULT CURRENT_TIMESTAMP 
  ON UPDATE CURRENT_TIMESTAMP
) ENGINE=InnoDB DEFAULT CHARSET=utf8mb4;
INSERT INTO `umbrales` (
`temperatura_minima`, `temperatura_maxima`, 
`humedad_ambiente_minima`, `humedad_ambiente_maxima`, 
`luminosidad_minima`, `luminosidad_maxima`, 
`humedad_suelo_minima`, `humedad_suelo_maxima`) VALUES
(30, 35, 30, 70, 30, 150, 20, 80);
\end{lstlisting}

\begin{lstlisting}[language=python, firstnumber=0, basicstyle=\normalsize, caption={Comandos Mysql para crear tabla \textbf{sensores}.}] 
CREATE TABLE `sensores` (
  `id` int NOT NULL AUTO_INCREMENT,
  `fecha` date DEFAULT NULL,
  `hora` time DEFAULT NULL,
  `temperatura` decimal(4,2) DEFAULT NULL,
  `humedad` decimal(4,2) DEFAULT NULL,
  `intensidad_luz` decimal(4,2) DEFAULT NULL,
  `humedad_suelo` decimal(4,2) DEFAULT NULL,
  PRIMARY KEY (`id`)
) ENGINE=InnoDB DEFAULT CHARSET=utf8mb4;
\end{lstlisting}

Teniendo en cuenta una configuración de red interna específica, se tiene que reaperturar y redirigir los puertos desde el router para tener acceso al servidor desde el exterior (ip pública), ya que como existen otros servidores sirviendo alguno de los mismos datos, necesitamos redirigir el servicio por puerto.

\begin{table}[htbp]
\begin{center}
\caption{Configuración de red interna.}
\begin{tabular}{|l|l|} %|c|c|
\hline
\rowcolor[HTML]{C0C0C0} 
\textbf{Característica} & \textbf{Valor}\\ \hline
inet & 192.0.0.6 \\ \hline
netmask & 255.255.255.0\\ \hline
broadcast & 192.0.0.255 \\ \hline
\end{tabular}
\end{center}
\end{table}

\begin{lstlisting}[language=cpp, firstnumber=0, basicstyle=\normalsize, caption={Comandos para reaperturar y redirigir puertos.}] 
nat server protocol tcp global interface LoopBack 0 3001 inside 192.0.0.6 ftp
nat server protocol tcp global interface LoopBack 0 3002 inside 192.0.0.6 22
nat server protocol udp global interface LoopBack 0 3002 inside 192.0.0.6 22
nat server protocol tcp global interface LoopBack 0 3003 inside 192.0.0.6 www
nat server protocol udp global interface LoopBack 0 3003 inside 192.0.0.6 80
nat server protocol udp global interface LoopBack 0 3001 inside 192.0.0.6 21
nat server protocol tcp global interface LoopBack 0 8080 inside 192.0.0.6 8080
nat server protocol udp global interface LoopBack 0 8080 inside 192.0.0.6 8080
nat server protocol tcp global interface LoopBack 0 135 inside 192.0.0.6 135
nat server protocol udp global interface LoopBack 0 135 inside 192.0.0.6 135
nat server protocol tcp global interface LoopBack 0 3307 inside 192.0.0.6 3307
nat server protocol udp global interface LoopBack 0 3307 inside 192.0.0.6 3307
nat server protocol tcp global interface LoopBack 0 1883 inside 192.0.0.6 1883
nat server protocol udp global interface LoopBack 0 1883 inside 192.0.0.6 1883
nat server protocol udp global interface LoopBack 0 3000 inside 192.0.0.6 3000
nat server protocol tcp global interface LoopBack 0 3000 inside 192.0.0.6 3000
nat server protocol tcp global interface LoopBack 0 30308 inside 192.0.0.6 3308
nat server protocol udp global interface LoopBack 0 30308 inside 192.0.0.6 3308
\end{lstlisting}

\begin{lstlisting}[language=cpp, firstnumber=0, basicstyle=\normalsize, caption={Comando para activar el firewall.}] 
sudo ufw enable\end{lstlisting}

\begin{lstlisting}[language=cpp, firstnumber=0, basicstyle=\normalsize, caption={Comando para permitir conexión ssh.}] 
sudo ufw allow ssh\end{lstlisting}

\begin{figure}[h]
\centering
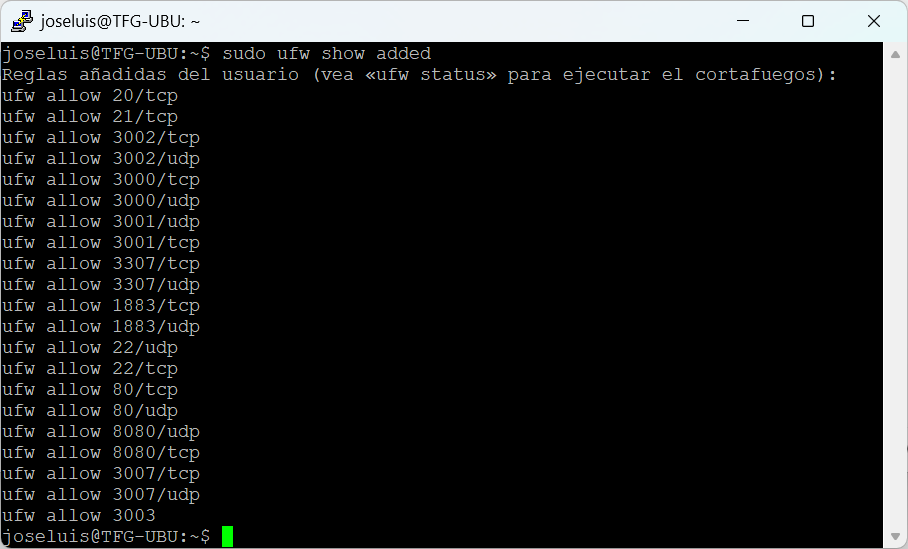
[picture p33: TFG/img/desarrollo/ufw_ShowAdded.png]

\caption{Conexión ssh permitida.}
\end{figure}

Ahora necesitamos instalar \textbf{mosquitto}~\cite{misc:mosquitto} para la conectividad por MQTT~\cite{manual:MQTT}.

MQTT nos servirá para la transmisión de datos en tiempo real, mediante los topics correspondientes.

El servidor LAMP será el Broker MQTT, se encarga de gestionar las peticiones.

\begin{lstlisting}[language=cpp, firstnumber=0, basicstyle=\normalsize, caption={Comando para instalar mosquitto.}] 
sudo apt install mosquitto\end{lstlisting}

\begin{lstlisting}[language=cpp, firstnumber=0, basicstyle=\normalsize, caption={Comando para instalar mosquitto-clients.}] 
sudo apt install mosquitto-clients\end{lstlisting}

\begin{lstlisting}[language=cpp, firstnumber=0, basicstyle=\normalsize, caption={Comando para instalar mosquitto-clients.}] 
sudo apt install mosquitto-clients\end{lstlisting}

\begin{lstlisting}[language=cpp, firstnumber=0, basicstyle=\normalsize, caption={Comando para comprobar el estado de mosquitto.}] 
sudo systemctl status mosquitto\end{lstlisting}

\begin{figure}[h]
\centering
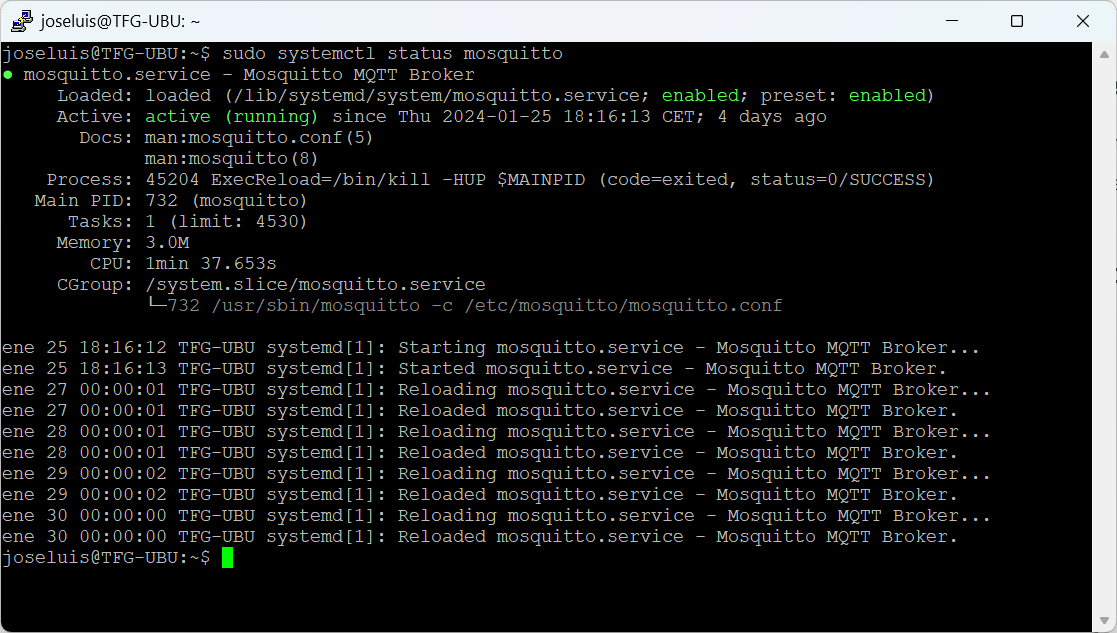
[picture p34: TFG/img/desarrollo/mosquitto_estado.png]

\caption{Mosquitto operativo}
\end{figure}

\subsection{Hardware}

Se tiene que instalar el firmware en la Raspberry Pi Pico W para que podamos programarlo mediante Micropython.
Primero descargamos el firmware de Micropython desde su página oficial~\cite{misc:MicropythonFirmware}.

Para fines prácticos nombraremos al firmware descargado: \textbf{rp2-pico.uf2}.

\begin{figure}[h]
\centering
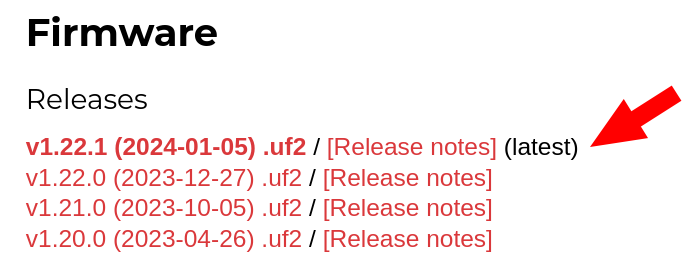
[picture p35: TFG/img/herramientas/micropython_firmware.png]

\caption{Descargar el firmware más reciente.}
\end{figure}

Conectar el puerto usb de la Raspberry Pi Pico W manteniendo presionado el botón \textbf{BOOTSEL}.

\begin{figure}[h]
\centering
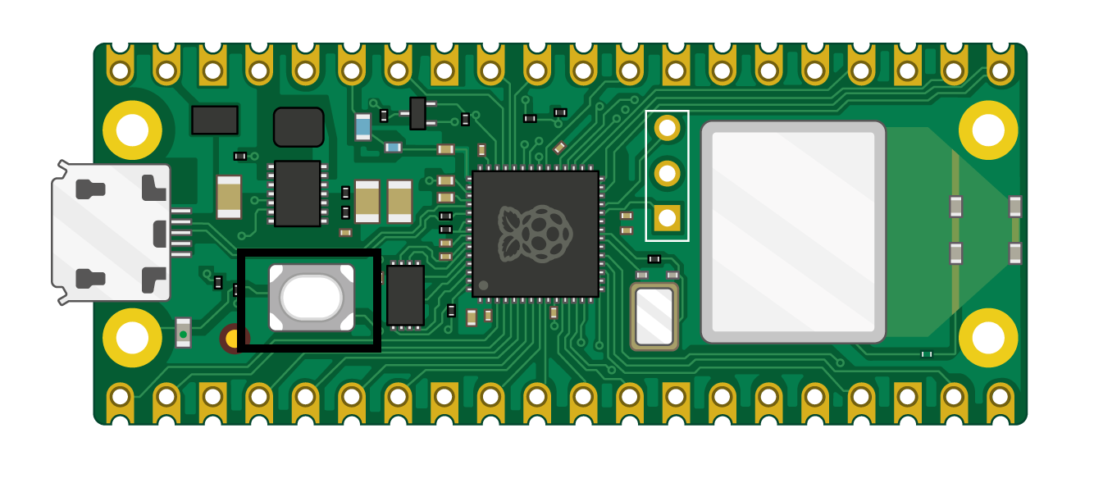
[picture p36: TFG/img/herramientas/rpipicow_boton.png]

\caption{Conectar usb manteniendo presionado.}
\end{figure}

Se ha creado un script en bash al que llamamos \textbf{instaladorFirmware.sh}. La ejecución de este permitirá instalar el firmware de Micropython en la Raspberry Pi Pico W.

\begin{lstlisting}[language=sh, firstnumber=0, basicstyle=\normalsize, caption={Script en bash para instalar el firmware Micropython.}] 
puerto=$(sudo dmesg | tail | grep -o 'sd[b-z]1')
sudo mkdir /mnt/pico
sudo mount /dev/$puerto /mnt/pico
sudo cp rp2-pico.uf2 /mnt/pico
sudo sync
\end{lstlisting}

Tener presente que el archivo \textbf{instaladorFirmware.sh} y el firmware descargado, deben estar en el mismo directorio.

\begin{lstlisting}[language=sh, firstnumber=0, basicstyle=\normalsize, caption={Comando para ejecutar el instalador de Firmware.}] 
sudo ./instaladorFirmware.sh\end{lstlisting}

Ahora que el firmware ya está cargado en la Raspberry Pi Pico W, se le conectan los sensores, módulos y leds RGB tal como se muestra.

\begin{figure}[h]
	\centering
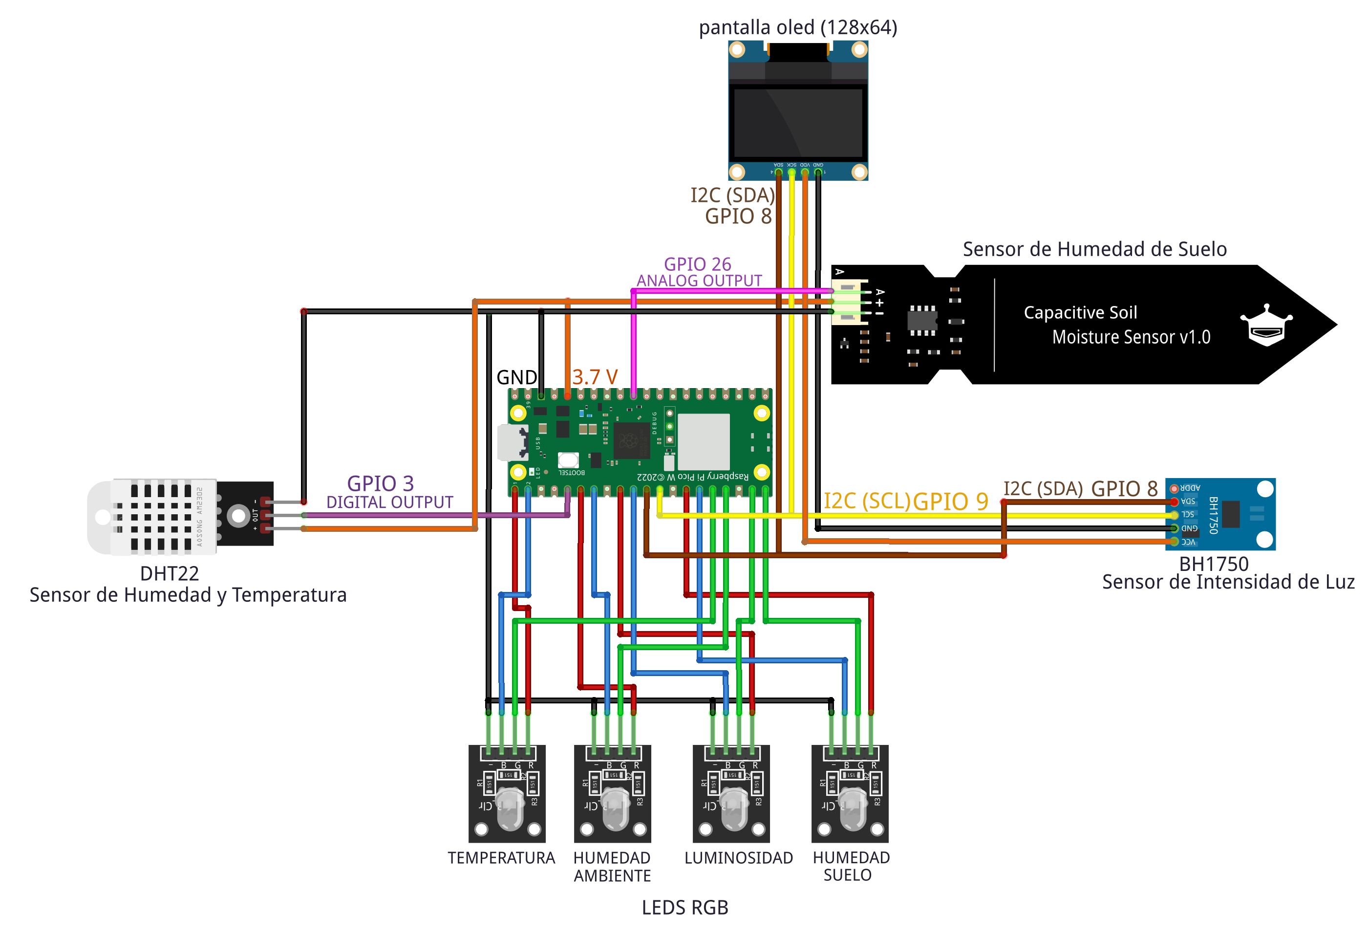
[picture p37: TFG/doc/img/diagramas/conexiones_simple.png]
	
	\caption{conexiones en el hardware.}
\end{figure}

Para llevar a cabo estas conexiones, se utiliza un protoboard junto con cables diseñados específicamente para conexiones en este tipo de placas experimentales.

Todos los componentes comparten la misma fuente de alimentación de energía proporcionada por la Raspberry Pi Pico W.

Por ahora ninguno de los componentes necesita alimentación de energía adicional.

Procederemos a mostrar las conexiones específicas de cada componente para más detalle.

\begin{figure}[h]
	\centering
	
	\caption{DHT22: Sensor de humedad y temperatura del ambiente.}
\end{figure}

\begin{figure}[h]
	\centering
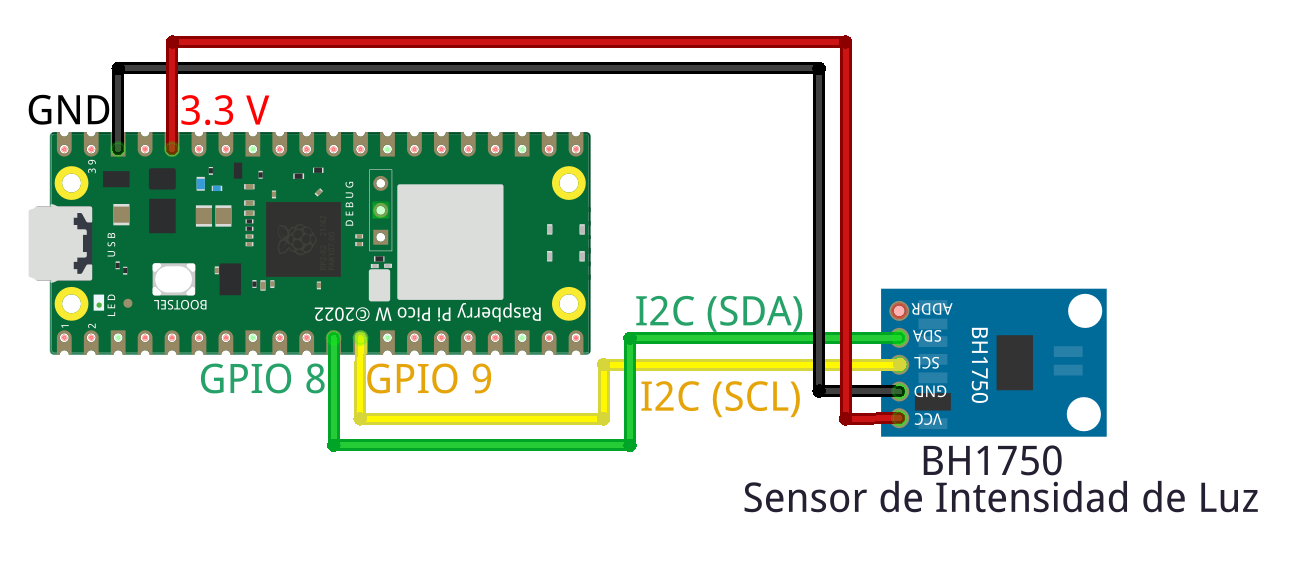
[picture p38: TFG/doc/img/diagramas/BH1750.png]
	
	\caption{BH1750: Sensor de intensida de luz.}
\end{figure}

Los diagramas de conexiones son muy claros, no hay gran dificultad para ello.

Respecto a todo el hardware usado, todos los compomentes son de fácil adquisición y hay gran documentación en internet.

\begin{figure}[h]
	\centering
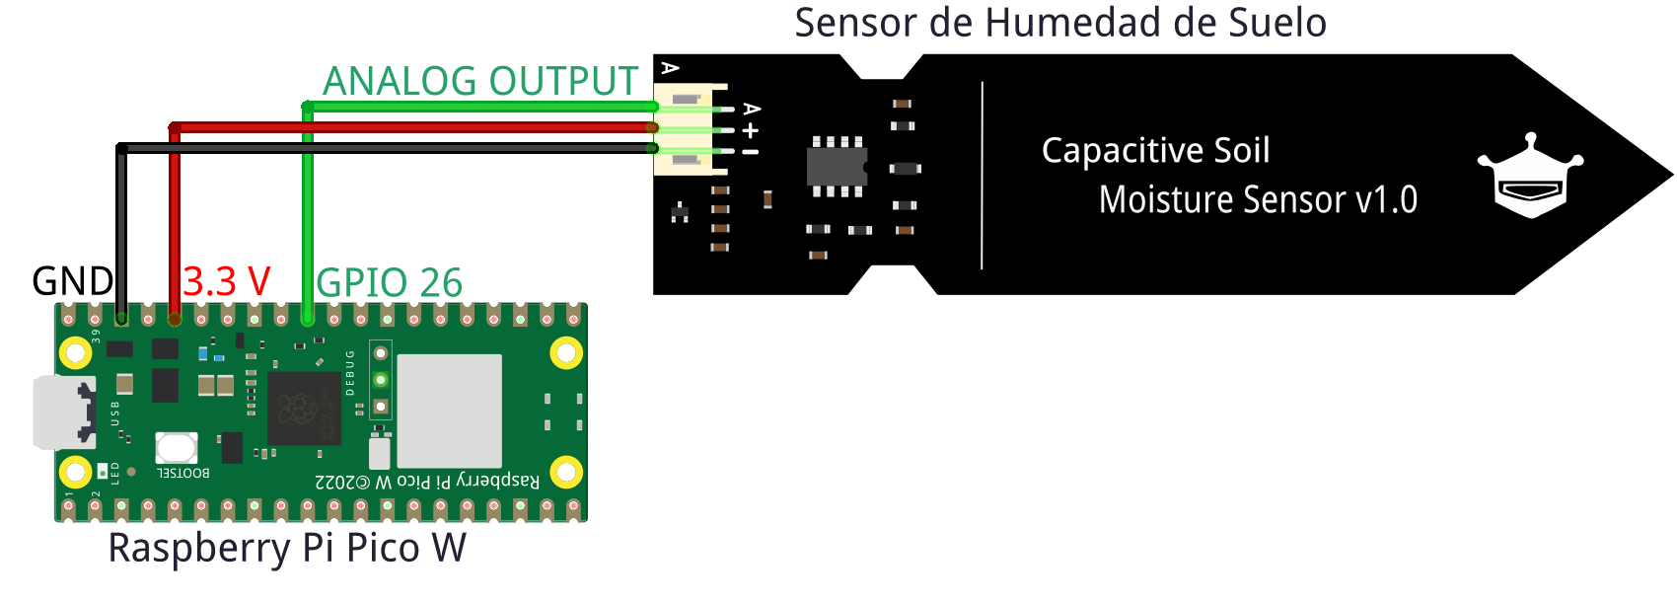
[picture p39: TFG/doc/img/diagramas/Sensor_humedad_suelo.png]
	
	\caption{Sensor de humedad del suelo.}
\end{figure}

Si bien por ahora las conexiones se hacen usando un protoboard, en un futuro se puede diseñar una placa para conectar todos los componentes sin necesidad de cables.

El sensor de humedad de suelo~\cite{wiki:SensorHumedadSuelo} debe introducirse en el suelo solo hasta cierto límite.

La pantalla oled~\ref{conexion:oled} permitirá observar los valores de los sensores en tiempo real en el mismo invernadero. Se ha escogido este modelo de pantalla por su bajo consumo de energía y el protocolo I2C nos permite hacer menos conexiones a comparación de este mismo modelo de pantalla pero con protocolo SPI.

\begin{figure}[h]
	\centering
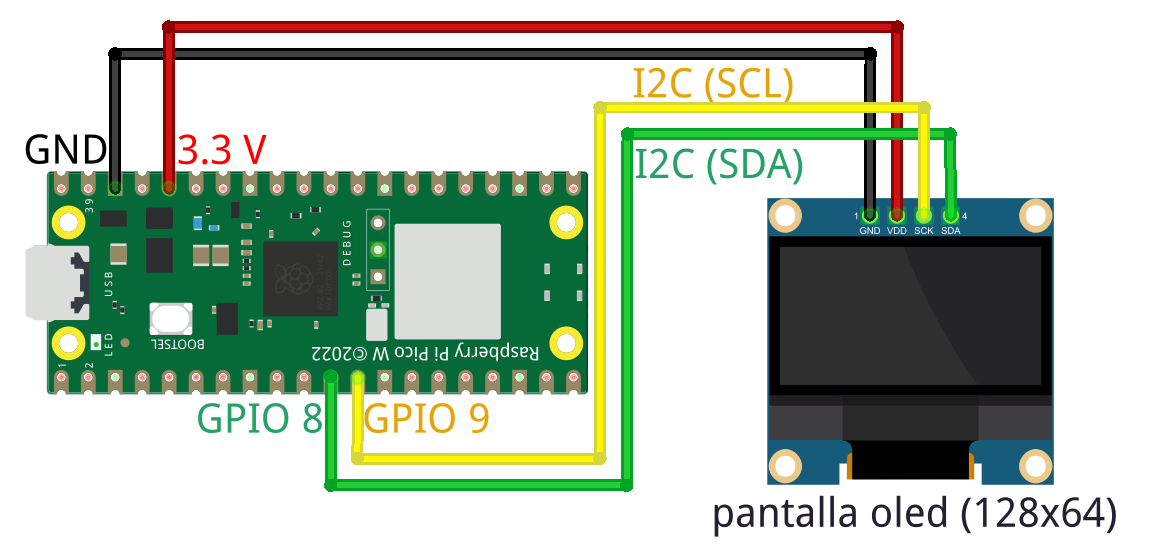
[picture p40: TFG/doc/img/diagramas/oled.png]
	
	\caption{Pantalla oled de 128x64 píxeles.}\label{conexion:oled}
\end{figure}

Los leds RGB~\cite{manual:LedRGB} se usarán como alertas visuales, cada color indicará en que posición respecto al umbral está un valor. Los umbrales representan los valores en el que tienen que estar cada una de las variables medidas.

\begin{table}[htbp]
\begin{center}
	\caption{Umbrales ideales para un invernadero de cannabis medicinal.}\label{tabla:umbrales}
\begin{tabular}{|l|l|l|l|}
\hline
\rowcolor[HTML]{C0C0C0} 
\textbf{Característica} & \textbf{Mínimo} & \textbf{Máximo} & \textbf{Unidades}\\ \hline
TEMPERATURA & 30 & 35 & \textcelsius\\ \hline
HUMEDAD & 30 & 70 & \% \\ \hline
LUMINOSIDAD & 30 & 150 & lux\\ \hline
HUMEDAD DEL SUELO & 20 & 80 & \% \\ \hline
\end{tabular}
\label{tabla:umbrales}
\end{center}
\end{table}

\begin{table}[htbp]
\begin{center}
\caption{Indicadores por color en los leds RGB.}
\begin{tabular}{|l|l|} %|c|c|
\hline
\rowcolor[HTML]{C0C0C0} 
\textbf{Color} & \textbf{Descripción}\\ \hline
Rojo & Por encima del umbral\\ \hline
Azul & Por debajo del umbral\\ \hline
Apagado & Valor dentro del umbral\\ \hline
Verde & Mecanismo activado\\ \hline
\end{tabular}
\label{tabla:ledsRGBColores}
\end{center}
\end{table}

Se están usando 4 módulos led RGB, uno por cada variable medida por los sensores.

\begin{figure}[h]
	\centering
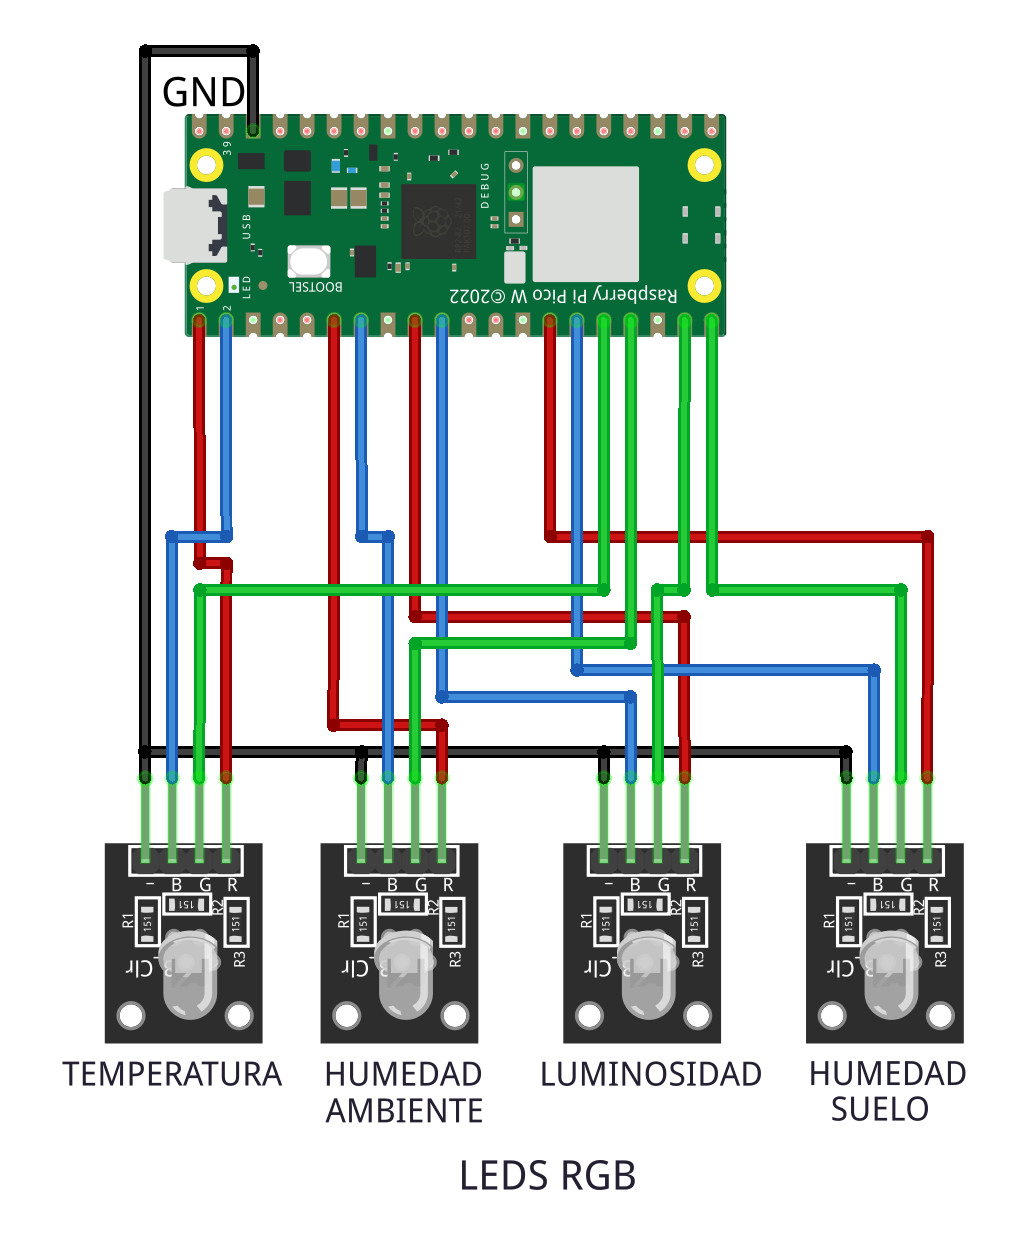
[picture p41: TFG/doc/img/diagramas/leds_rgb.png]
	
	\caption{Módulo led RGB.}
\end{figure}

Cada módulo RGB tiene un cable para GND y tres respecto a los colores rojo, verde y azul.

Usando el IDE Thonny~\cite{misc:Thonny} y con Micropython vamos a poder programar el hardware. 

Tenemos que hacer unas configuraciones simples antes de poder usar el IDE Thonny con Micropython en nuestra Raspberry Pi Pico W.

Hacemos clic en \textbf{Run/Configure interpreter}.

\begin{figure}[h]
	\centering
	
	\caption{Abrimos el configurador del interpreter.}
\end{figure}

Seleccionamos que usaremos \textbf{Micropython} para Raspberry Pi Pico y seleccionamos el puerto que corresponde su conexión por usb.

\begin{figure}[h]
	\centering
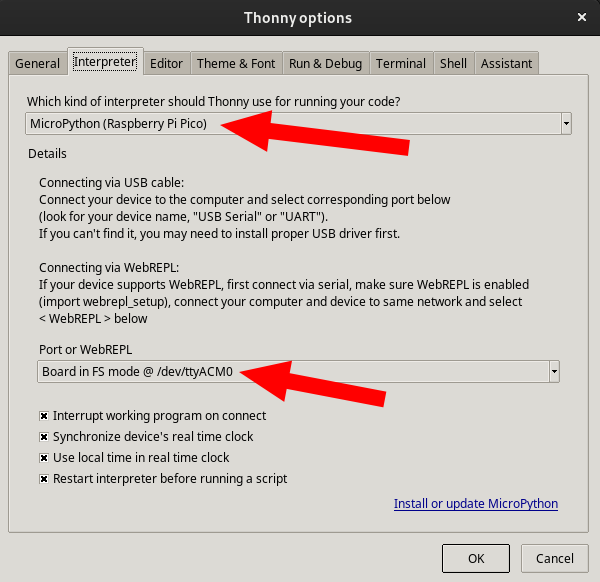
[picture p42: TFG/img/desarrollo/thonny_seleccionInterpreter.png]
	
	\caption{Habilitamos Thonny para Micropython.}
\end{figure}

Respecto a este proyecto solo tienes que seleccionar el archivo \textbf{main.py} y le das clic en el botón verde para ejecutar y cargar el código a la placa Raspberry Pi Pico W. 

\begin{figure}[h]
	\centering
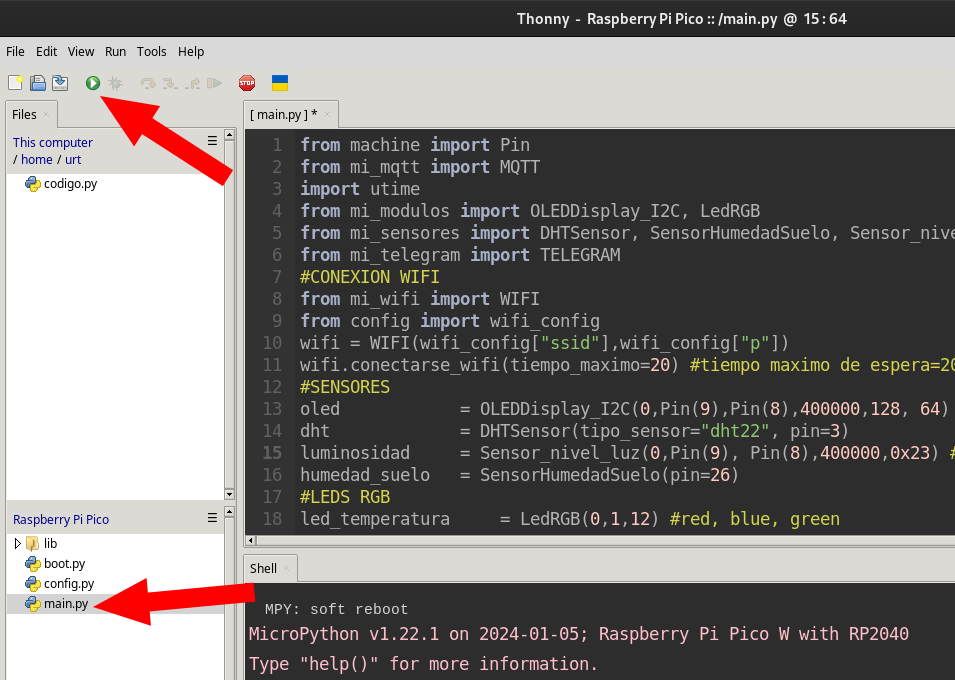
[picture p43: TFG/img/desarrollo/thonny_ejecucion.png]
	
	\caption{Ejecución y carga a un solo clic.}
\end{figure}

El archivo \textbf{boot.py} se ejecuta al prender la Raspberry Pi Pico W, y al importar el \textbf{main.py} hace que éste se ejecute. Entonces una vez hecha la configuración y programación solo tendremos que suministrar energía a la placa y empezará a funcionar para lo que se le ha programado.

\begin{figure}[h]
	\centering
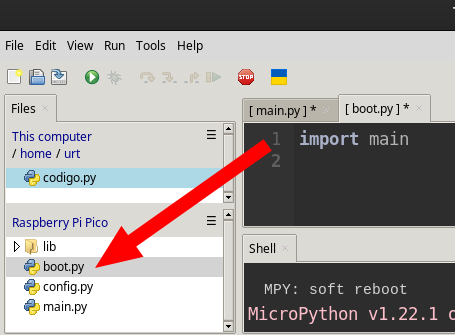
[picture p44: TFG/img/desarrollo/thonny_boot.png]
	
	\caption{boot.py se ejecuta en el arranque.}
\end{figure}

\subsection{nodeMqtt}

Esta parte del proyecto se encarga de capturar datos mediante MQTT y los almacena en una base de datos usando Mysql. 

La instalación y ejecución es muy simple.

\begin{lstlisting}[language=sh, firstnumber=0, basicstyle=\normalsize, caption={Comando para instalar MQTT.js.}] 
npm install mqtt \end{lstlisting}

\begin{lstlisting}[language=sh, firstnumber=0, basicstyle=\normalsize, caption={Comando para instalar mysql para node.js.}] 
npm install mysql2\end{lstlisting}

\begin{lstlisting}[language=sh, firstnumber=0, basicstyle=\normalsize, caption={Ejecución.}] 
mp2 start index.js --name "nodeMqtt"\end{lstlisting}

Respecto a MQTT \textbf{index.js} utiliza los siguientes topics.

\begin{table}[htbp]
\begin{center}
\caption{Topics MQTT usados en \textbf{nodeMqtt}.}
\begin{tabular}{|l|l|} %|c|c|
\hline
\rowcolor[HTML]{C0C0C0} 
\textbf{Característica} & \textbf{Descripción}\\ \hline
invernadero/sensores &  Captura la fecha, hora y valores de sensores\\ \hline
invernadero/umbrales & Captura los umbrales \\ \hline
\end{tabular}
\end{center}
\end{table}

Almacena los datos en la base de datos \textbf{TFG\_UBU}~\ref{tabla:BDTFG}.

\begin{figure}[h]
	\centering
	
	\caption{Datos almacenados en tabla.}
\end{figure}

Veamos el contenido de \textbf{index.js}.

\begin{lstlisting}[language=cpp, firstnumber=0, basicstyle=\normalsize, caption={Contenido de index.js.}] 
var mqtt = require("mqtt");
const mysql = require('mysql2');

// Opciones para la conexión MQTT
const mqttOptions = {
  keepAlive: 60,
  reconnectPeriod: 1000,
  connectTimeout: 4000
};

const client = mqtt.connect("mqtt://localhost:1883", mqttOptions);

const dbConfig = {
  host: 'localhost',
  user: 'joseluis',
  password: 'TuPassword',
  database: 'TFG_UBU',
  port: 3307
};
const pool = mysql.createPool(dbConfig);
function EventoConectar() {
  client.subscribe("invernadero/sensores");
  client.subscribe("invernadero/umbrales");
}
function EventoMensaje(topic, message) {
  if (topic === "invernadero/sensores") {
    const [fecha, hora, temperatura, humedad, intensidad_luz, humedad_suelo] = message.toString().split(',');
    const query = 'INSERT INTO sensores (fecha, hora, temperatura, humedad, intensidad_luz, humedad_suelo) VALUES (?, ?, ?, ?, ?, ?)';
    pool.query(query, [fecha, hora, temperatura, humedad, intensidad_luz, humedad_suelo], (error) => {
      if (error) {
        console.error('Error al realizar la inserción en la base de datos:', error);
      } else {
        console.log('Inserción en base de datos exitosa');
      }
    });
  } else if (topic === "invernadero/umbrales") {
    const [temperatura_minima, temperatura_maxima, humedad_minima, humedad_maxima, luminosidad_minima, luminosidad_maxima, humedad_suelo_minima, humedad_suelo_maxima] = message.toString().split(',');

    const query = 'UPDATE umbrales SET temperatura_minima = ?, temperatura_maxima = ?, humedad_ambiente_minima = ?, humedad_ambiente_maxima = ?, luminosidad_minima = ?, luminosidad_maxima = ?, humedad_suelo_minima = ?, humedad_suelo_maxima = ?';

    pool.query(query, [temperatura_minima, temperatura_maxima, humedad_minima, humedad_maxima, luminosidad_minima, luminosidad_maxima, humedad_suelo_minima, humedad_suelo_maxima], (error) => {
      if (error) {
        console.error('Error al actualizar umbrales en la base de datos:', error);
      } else {
        console.log('Actualización de umbrales en base de datos exitosa');
      }
    });
  }
}

client.on("connect", EventoConectar);
client.on("message", EventoMensaje);

pool.on('error', (err) => {
  console.error('Error inesperado en la conexión del pool:', err);
});
\end{lstlisting}

\subsection{InverIoT}
Aplicación de escritorio para Windows usando C\#.

Los archivos relacionados a este proyecto están indicados en la tabla \ref{tabla:directorioInverIoT}.

\begin{table}[htbp]
\begin{center}
\caption{Topics MQTT usados en \textbf{InverIoT}.}
\begin{tabular}{|l|l|}
\hline
\rowcolor[HTML]{C0C0C0} 
\textbf{Característica} & \textbf{Descripción}\\ \hline
invernadero/ordenes & Captura las ordenes\\ \hline
invernadero/sensores &  Captura la fecha, hora y valores de sensores\\ \hline
\end{tabular}
\end{center}
\end{table}

MQTT se usa para mostrar los datos en tiempo real y Mysql para el histórico de datos.

Las ordenes que se envían son para activar mecanismos (representados por la activación de un led verde).

La ejecución del programa lo podemos hacer en Visual Studio Code~\cite{misc:vscode} de la siguiente forma:

\begin{lstlisting}[language=sh, firstnumber=0, basicstyle=\normalsize, caption={Ejecutar proyecto InverIoT.}] 
dotnet build\end{lstlisting}

\begin{lstlisting}[language=cpp, firstnumber=0, basicstyle=\normalsize, caption={Contenido de Program.cs.}] 
namespace InverIoT
{
    internal static class Program
    {
        /// <summary>
        ///  The main entry point for the application.
        /// </summary>
        [STAThread]
        static void Main()
        {
            // see https://aka.ms/applicationconfiguration.
            ApplicationConfiguration.Initialize();
            Application.Run(new frmMain());
        }
    }
}
\end{lstlisting}

\subsection{dashboard}
Dashboard web para mostrar datos, no envía ordenes. Es accesible desde internet.
El contenido del directorio \textbf{dashboard} lo encontramos en la tabla~\ref{tabla:directorioDashboard}.

\begin{table}[htbp]
\begin{center}
\caption{Topics MQTT usados en \textbf{dashboard}.}
\begin{tabular}{|l|l|} %|c|c|
\hline
\rowcolor[HTML]{C0C0C0} 
\textbf{Característica} & \textbf{Descripción}\\ \hline
invernadero/sensores &  Captura la fecha, hora y valores de sensores\\ \hline
\end{tabular}
\end{center}
\end{table}

\begin{lstlisting}[language=sh, firstnumber=0, basicstyle=\normalsize, caption={Instalaciones necesarias.}] 
npm install express
npm install socket.io
\end{lstlisting}

Respecto al archivo \textbf{servers.js} debemos configurar respecto a la base de datos creada en el servidor LAMP:

\begin{lstlisting}[language=cpp, firstnumber=0, basicstyle=\normalsize, caption={Configuración de base de datos.}] 
const dbConfig = {
    host: 'localhost',
    port: 3307, // Puerto especificado aquí
    user: 'joseluis',
    password: 'TuPassword',
    database: 'TFG_UBU'
};
\end{lstlisting}

\begin{lstlisting}[language=sh, firstnumber=0, basicstyle=\normalsize, caption={Ejecución.}] 
mp2 start servers.js --name "dashboard"
\end{lstlisting}

\begin{lstlisting}[language=cpp, firstnumber=0, basicstyle=\normalsize, caption={Contenido de \textbf{servers.js}.}] 
const express = require('express');
const http = require('http');
const socketIo = require('socket.io');
const mqtt = require('mqtt');
const path = require('path');
const mysql = require('mysql2');
const cors = require('cors');
const app = express();
const server = http.createServer(app);
const io = socketIo(server);
const mqttClient = mqtt.connect('mqtt://localhost:1883', {
  keepAlive: 60,            // Enviar un mensaje de ping cada 60 segundos para mantener la conexión
  reconnectPeriod: 1000,    // Intentar reconectar cada 1000 milisegundos (1 segundo) en caso de desconexión
  connectTimeout: 4000      // Tiempo de espera de 4000 milisegundos (4 segundos) para la conexión inicial
});
// Configuración de la base de datos
const dbConfig = {
    host: 'localhost',
    port: 3307, // Puerto especificado aquí
    user: 'joseluis',
    password: 'TuPassword',
    database: 'TFG_UBU'
};

const pool = mysql.createPool(dbConfig);
// Intentar obtener una conexión para probar si la conexión a la base de datos es exitosa
pool.getConnection((err, connection) => {
    if (err) {
        console.error('Error al conectar a la base de datos:', err);
        return;
    }
    console.log('Conectado exitosamente a la base de datos MySQL');
    connection.release(); // No olvides liberar la conexión
});

// Conexión a MQTT y manejo de mensajes
mqttClient.on('connect', () => {
    console.log('Conectado al broker MQTT');
    mqttClient.subscribe('invernadero/sensores');
});

mqttClient.on('message', (topic, message) => {
    console.log(`Mensaje recibido en el topic ${topic}: ${message}`);
    if (topic === 'invernadero/sensores') {
        io.emit('mqtt_data', message.toString());
    }
});

// Middleware
app.use(express.static(path.join(__dirname, './')));
app.use(cors());

// Rutas para servir las páginas
app.get('/', (req, res) => {
    res.sendFile(path.join(__dirname, './', 'index.html'));
});
app.get('/historico', (req, res) => {
    res.sendFile(path.join(__dirname, './', 'historico.html'));
});

// Ruta para obtener datos históricos en un rango de fechas
app.get('/datos-historicos', (req, res) => {
    const { fechaInicio, fechaFin } = req.query;
    let query = "SELECT fecha, hora, temperatura, humedad, intensidad_luz, humedad_suelo FROM sensores";
    let params = [];
    if (fechaInicio && fechaFin) {
        query += " WHERE fecha BETWEEN ? AND ?";
        params.push(fechaInicio, fechaFin);
    }
    pool.query(query, params, (error, results, fields) => {
        if (error) {
            console.error('Error al realizar la consulta a la base de datos:', error);
            res.status(500).send('Error al obtener los datos');
            return;
        }
        res.json(results);
    });
});

app.get('/umbrales', (req, res) => {
    pool.query('SELECT * FROM umbrales ORDER BY fecha_actualizacion DESC LIMIT 1', (error, results, fields) => {
        if (error) {
            console.error('Error al realizar la consulta a la base de datos:', error);
            res.status(500).send('Error al obtener los datos de los umbrales');
            return;
        }
        res.json(results[0]);
    });
});
const PORT = 3000;
server.listen(PORT, () => console.log(`Servidor corriendo en el puerto ${PORT}`));
\end{lstlisting}

\begin{figure}[h]
\centering
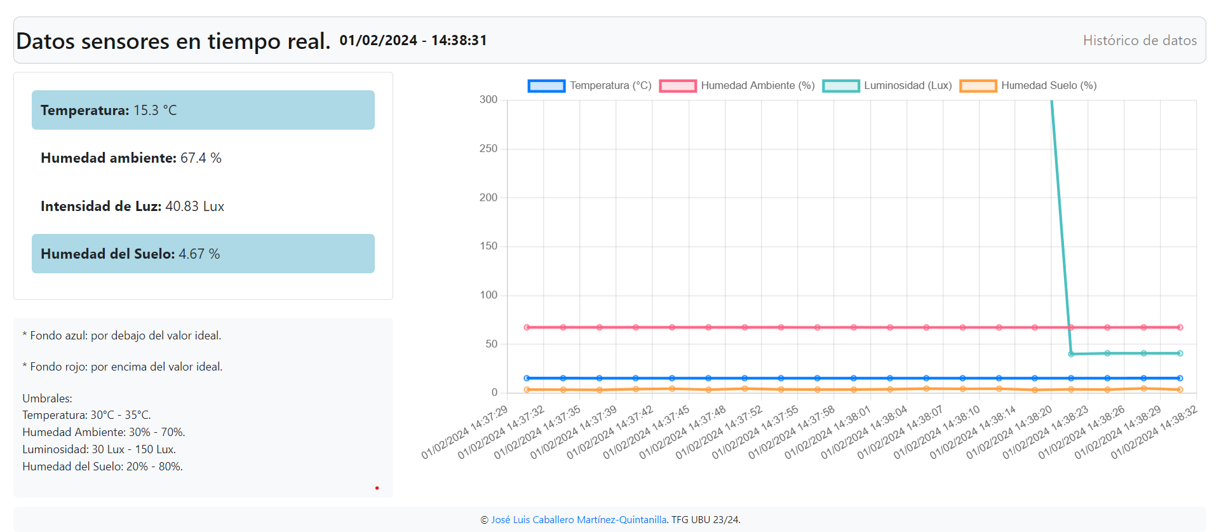
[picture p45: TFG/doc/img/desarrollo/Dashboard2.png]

\caption{Dashboard en ejecución.}
\end{figure}

\subsection{AnalisisDatos}
Mediante Jupyter Notebook~\cite{misc:Jupyter_Notebook} se hace la limpieza de datos y un resumen estadístico.

En el directorio \textbf{AnalisisDatos}~\ref{tabla:directorioAnalisisDatos} vamos a encontrar los archivos \textbf{analisis.ipynb} y \textbf{data.csv}.

\begin{lstlisting}[language=cpp, firstnumber=0, basicstyle=\normalsize, caption={Instalación de Jupyter Notebook.}] 
sudo apt install jupyter-notebook
\end{lstlisting}

\begin{lstlisting}[language=cpp, firstnumber=0, basicstyle=\normalsize, caption={Ejecución de \textbf{analisis.ipynb}.}] 
jupyter-notebook analisis.ipynb
\end{lstlisting}

Luego automáticamente se ejecuta el notebook y se visualiza en el navegador con una ruta muy similar a esta:

\textbf{http://localhost:8888/notebooks/analisis.ipynb}

Ahora ya puedes ver el código de análisis de datos con python en Jupyter Notebook.

\begin{figure}[h]
\centering
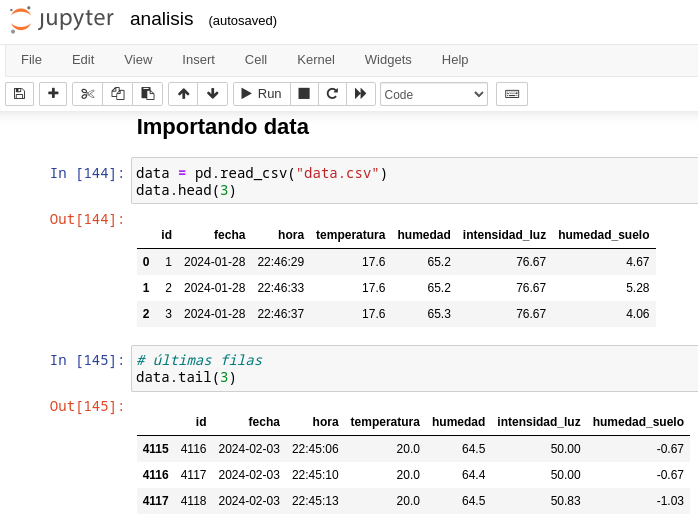
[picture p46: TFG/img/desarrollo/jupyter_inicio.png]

\caption{Data de sensores en Jupyer notebook}
\end{figure}

\section{Compilación, instalación y ejecución del proyecto}
Luego de hacer las configuraciones ya mencionadas, se va a ejecutar respecto a estas partes específicas del proyecto:

\begin{table}[htbp]
\begin{center}
\caption{Compilación y ejecución.}
\begin{tabular}{|l|l|}
\hline
\rowcolor[HTML]{C0C0C0} 
\textbf{Parte del proyecto} & \textbf{Descripción}\\ \hline
Servidor LAMP & Automático\\ \hline
Hardware &  Automático al suministrar energía\\ \hline
nodeMqtt & Automático \\ \hline
InverIoT &  Solo ejecutar su instalador en Windows\\ \hline
dashboard &  Automático \\ \hline
AnalisisDatos & Necesita abrir mediante Jupyter Notebook \\ \hline
Bot de Telegram & Automático \\ \hline
\end{tabular}
\label{tabla:CompilacionEjecucion}
\end{center}
\end{table}

\subsection{Hardware}
Simplemente conectar la Raspberry Pi Pico a una toma de energía y todo el hardware va a empezar a funcionar, ya que se ha configurado para que el archivo \textbf{main.py} se está ejecutando en el arranque.

\subsection{InverIoT}
Se puede usar simplemente su instalador llamado \textbf{Instalador - InverIoT - v2.2.exe}.

O se puede ejecutar el código fuente usando Visual Studio Code~\cite{misc:vscode}.

\begin{lstlisting}[language=sh, firstnumber=0, basicstyle=\normalsize, caption={Ejecutar proyecto InverIoT.}] 
dotnet build\end{lstlisting}

\subsection{AnalisisDatos}

Se ejecuta usando Jupyter Notebook~\cite{misc:Jupyter_Notebook}.

\begin{lstlisting}[language=cpp, firstnumber=0, basicstyle=\normalsize, caption={Ejecución de \textbf{analisis.ipynb}.}] 
jupyter-notebook analisis.ipynb
\end{lstlisting}

\section{Calidad del código}
Para evaluar la calidad del código, se ha empleado un servicio externo denominado SonarCloud, integrado con GitHub. Este servicio realiza un análisis exhaustivo del código, identificando posibles errores y sugiriendo mejoras para optimizar la calidad del código fuente.

Puedes acceder a las estadísticas de SonarCloud mediante el siguiente enlace:~\url{https://sonarcloud.io/project/overview?id=JLCaballeroMQ_Proyecto_TFG_UBU_23_24}

%\section{Pruebas del sistema}

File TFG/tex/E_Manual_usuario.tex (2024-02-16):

\apendice{Documentación de usuario}

\section{Introducción}

%Se recomienda a los usuarios seguir cuidadosamente cada sección de este manual para garantizar una implementación exitosa y para aprovechar todas las capacidades que ofrece el sistema IoT de monitorización de invernaderos. 
Este documento está diseñado para facilitar la comprensión y el uso del sistema, contribuyendo así a una experiencia de usuario satisfactoria y a la consecución de los objetivos de monitorización de cultivos de cannabis medicinal de manera eficaz y económica.

%\section{Requisitos de usuarios}

\section{Instalación Física}
Se tiene que instalar el firmware en la Raspberry Pi Pico W para que podamos programarlo mediante Micropython.
Primero descargamos el firmware de Micropython desde su página oficial~\cite{misc:MicropythonFirmware}.

Para fines prácticos nombraremos al firmware descargado: \textbf{rp2-pico.uf2}.

\begin{figure}[h]
\centering

\caption{Descargar el firmware más reciente.}
\end{figure}

Conectar el puerto usb de la Raspberry Pi Pico W manteniendo presionado el botón \textbf{BOOTSEL}.

\begin{figure}[h]
\centering

\caption{Conectar usb manteniendo presionado.}
\end{figure}

Se ha creado un script en bash al que llamamos \textbf{instaladorFirmware.sh}. La ejecución de este permitirá instalar el firmware de Micropython en la Raspberry Pi Pico W.

\begin{lstlisting}[language=sh, firstnumber=0, basicstyle=\normalsize, caption={Script en bash para instalar el firmware Micropython.}] 
puerto=$(sudo dmesg | tail | grep -o 'sd[b-z]1')
sudo mkdir /mnt/pico
sudo mount /dev/$puerto /mnt/pico
sudo cp rp2-pico.uf2 /mnt/pico
sudo sync
\end{lstlisting}

Tener presente que el archivo \textbf{instaladorFirmware.sh} y el firmware descargado, deben estar en el mismo directorio.

\begin{lstlisting}[language=sh, firstnumber=0, basicstyle=\normalsize, caption={Comando para dar permisos de ejecución.}] 
sudo chmod +x instaladorFirmware.sh\end{lstlisting}

\begin{lstlisting}[language=sh, firstnumber=0, basicstyle=\normalsize, caption={Comando para ejecutar el instalador de Firmware.}] 
sudo ./instaladorFirmware.sh\end{lstlisting}

Usando el IDE Thonny~\cite{misc:Thonny} y con Micropython vamos a poder programar el hardware. Lo podemos descargar e instalar desde su pagina oficial~\cite{misc:Thonny}.

Tenemos que hacer unas configuraciones simples antes de poder usar el IDE Thonny con Micropython en nuestra Raspberry Pi Pico W.

Hacemos clic en \textbf{Run/Configure interpreter}.

\begin{figure}[h]
	\centering
	
	\caption{Abrimos el configurador del interpreter.}
\end{figure}

Seleccionamos que usaremos \textbf{Micropython} para Raspberry Pi Pico y seleccionamos el puerto que corresponde su conexión por usb.

\begin{figure}[h]
	\centering
	
	\caption{Habilitamos Thonny para Micropython.}
\end{figure}

Usar los archivos del directorio \textbf{Hardware} para guardarlos en la Raspberry Pi Pico W usando el IDE Thonny.

\begin{figure}[h]
	\centering
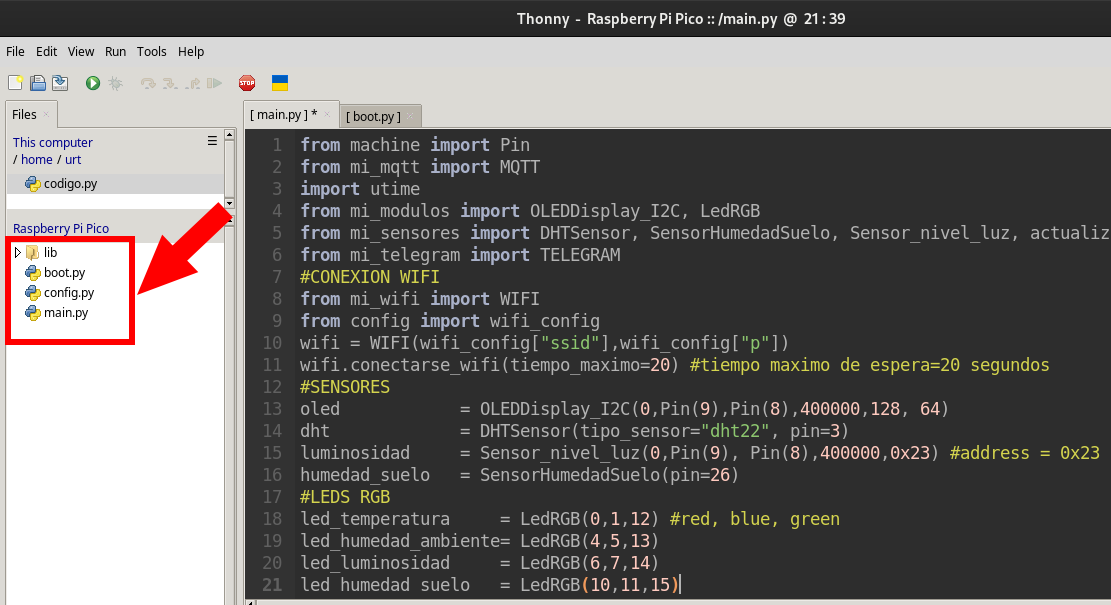
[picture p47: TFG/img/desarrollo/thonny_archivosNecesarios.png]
	
	\caption{Archivos necesarios para ejecutar en el hardware.}
\end{figure}

\begin{figure}[h]
	\centering
	
	\caption{Archivo de configuración en Micropython.}
\end{figure}

Modificamos el archivo \textbf{config.py} con nuestras credenciales.

\begin{lstlisting}[language=sh, firstnumber=0, basicstyle=\normalsize, caption={Configurar SSID y clave wifi.}] 
wifi_config = {
    'ssid':'SSID_WIFI',
    'p':'TU_PASSWORD_WIFI'
}\end{lstlisting}

\begin{lstlisting}[language=sh, firstnumber=0, basicstyle=\normalsize, caption={Configución de bot de Telegram.}] 
utelegram_config = {
    'token': 'BOT_TOKEN_TELEGRAM',
    'chat_id': 'BOT_CHAT_ID'
}
\end{lstlisting}

\begin{lstlisting}[language=sh, firstnumber=0, basicstyle=\normalsize, caption={Configuración de umbrales para los sensores.}] 
umbrales_sensores = {
    'TEMPERATURA_MINIMA': 30,
    'HUMEDAD_MINIMA': 30,
    'LUMINOSIDAD_MINIMA': 30,
    'HUMEDAD_SUELO_MINIMA': 20,
    'TEMPERATURA_MAXIMA': 35,
    'HUMEDAD_MAXIMA': 70,
    'LUMINOSIDAD_MAXIMA': 150,
    'HUMEDAD_SUELO_MAXIMA': 80
}
\end{lstlisting}

\begin{lstlisting}[language=sh, firstnumber=0, basicstyle=\normalsize, caption={Configuración MQTT.}] 
mqtt_config = {
    'server': '1.39.4.38', #IP DE TU SERVIDOR LAMP
    'port': 1883, #PUERTO USADO POR MQTT
    'topic_pub': 'invernadero/sensores',
    'topic_sub': 'invernadero/ordenes',
    'topic_umb': 'invernadero/umbrales',
    'client_id_pub': 'TFG_UBU_mqtt_id_pub',
    'client_id_sub': 'TFG_UBU_mqtt_id_sub',
    'client_id_umb': 'TFG_UBU_mqtt_id_umb'
}
\end{lstlisting}

\begin{lstlisting}[language=sh, firstnumber=0, basicstyle=\normalsize, caption={Configuración Wlan para usar ip fija.}] 
wlan_config = {
    'ip':'192.168.1.232',
    'mask':'255.255.255.0',
    'gateway':'192.168.1.1',
    'dns':'8.8.8.8' 
}
\end{lstlisting}

Una vez que haz completado las credenciales ya puedes desconectar y volver a conectar la Rapsberry Pi Pico W, al arrancar automáticamente se ejecutará la programación ya establecida.

Solo volverás a usar el IDE Thonny si quieres cambiar algo en el código o en el archivo de configuración.

Ahora procedemos a hacer las conexiones en el hardware.

Solo comprobar que todas las conexiones sean coherentes a la imagen.

\begin{figure}[h]
\centering

\caption{Conexiones del hardware para el cliente.}
\end{figure}

\section{Instalación del software}

\subsection{Servidor LAMP}
Se ha creado un script en bash para hacer las instalaciones automáticamente al que se ha nombrado \textbf{InstaladorServidor.sh}.

\begin{lstlisting}[language=sh, firstnumber=0, basicstyle=\normalsize, caption={Damos permisos de ejecución a \textbf{InstaladorServidor.sh}.}] 
sudo chmod +x InstaladorServidor.sh
\end{lstlisting}

\begin{lstlisting}[language=sh, firstnumber=0, basicstyle=\normalsize, caption={Contenido de \textbf{InstaladorServidor.sh}.}] 
sudo apt install apache2
sudo apt install mysql-server
sudo apt install php
sudo apt install ssh
sudo apt install phpmyadmin
sudo apt install vsftpd
sudo apt install ufw 
sudo apt install nodejs
sudo apt install pm2
sudo apt install npm
sudo apt install express
sudo apt install mosquitto 
\end{lstlisting}

\begin{lstlisting}[language=sh, firstnumber=0, basicstyle=\normalsize, caption={Ejecutamos \textbf{InstaladorServidor.sh}.}] 
sudo ./InstaladorServidor.sh
\end{lstlisting}

\subsection{Creación de base de datos}
\begin{lstlisting}[language=sh, firstnumber=0, basicstyle=\normalsize, caption={Comando para acceder a Mysql.}] 
sudo mysql\end{lstlisting}

\begin{lstlisting}[language=sh, firstnumber=0, basicstyle=\normalsize, caption={Comandos Mysql para crear Database \textbf{TFG\_UBU}.}] 
CREATE DATABASE TFG_UBU;
CREATE USER 'joseluis'@'%' IDENTIFIED BY 'Mipassword';
GRANT ALL ON TFG_UBU.* TO 'joseluis'@'%';
use TFG_UBU;
\end{lstlisting}

\begin{lstlisting}[language=sh, firstnumber=0, basicstyle=\normalsize, caption={Comandos Mysql para crear tabla \textbf{umbrales}.}] 
CREATE TABLE `umbrales` (
  `temperatura_minima` float NOT NULL,
  `temperatura_maxima` float NOT NULL,
  `humedad_ambiente_minima` float NOT NULL,
  `humedad_ambiente_maxima` float NOT NULL,
  `luminosidad_minima` float NOT NULL,
  `luminosidad_maxima` float NOT NULL,
  `humedad_suelo_minima` float NOT NULL,
  `humedad_suelo_maxima` float NOT NULL,
  `fecha_actualizacion` timestamp 
  NULL DEFAULT CURRENT_TIMESTAMP 
  ON UPDATE CURRENT_TIMESTAMP
) ENGINE=InnoDB DEFAULT CHARSET=utf8mb4;
INSERT INTO `umbrales` (
`temperatura_minima`, `temperatura_maxima`, 
`humedad_ambiente_minima`, `humedad_ambiente_maxima`, 
`luminosidad_minima`, `luminosidad_maxima`, 
`humedad_suelo_minima`, `humedad_suelo_maxima`) VALUES
(30, 35, 30, 70, 30, 150, 20, 80);
\end{lstlisting}

\begin{lstlisting}[language=sh, firstnumber=0, basicstyle=\normalsize, caption={Comandos Mysql para crear tabla \textbf{sensores}.}] 
CREATE TABLE `sensores` (
  `id` int NOT NULL AUTO_INCREMENT,
  `fecha` date DEFAULT NULL,
  `hora` time DEFAULT NULL,
  `temperatura` decimal(4,2) DEFAULT NULL,
  `humedad` decimal(4,2) DEFAULT NULL,
  `intensidad_luz` decimal(4,2) DEFAULT NULL,
  `humedad_suelo` decimal(4,2) DEFAULT NULL,
  PRIMARY KEY (`id`)
) ENGINE=InnoDB DEFAULT CHARSET=utf8mb4;
\end{lstlisting}

\subsection{dashboard}

\begin{lstlisting}[language=sh, firstnumber=0, basicstyle=\normalsize, caption={Instalaciones necesarias.}] 
npm install express
npm install socket.io
\end{lstlisting}

Respecto al archivo \textbf{servers.js} debemos configurar respecto a la base de datos creada en el servidor LAMP:

\begin{lstlisting}[language=cpp, firstnumber=0, basicstyle=\normalsize, caption={Configuración de base de datos.}] 
const dbConfig = {
    host: 'localhost',
    port: 3307, // Puerto especificado aquí
    user: 'joseluis',
    password: 'TuPassword',
    database: 'TFG_UBU'
};
\end{lstlisting}

Solo se ejecuta una vez y siempre va a estar ejecutándose, incluso si se reinicia el servidor.

\begin{lstlisting}[language=sh, firstnumber=0, basicstyle=\normalsize, caption={Ejecución.}] 
mp2 start servers.js --name "dashboard"
\end{lstlisting}

\subsection{InverIoT}
Solo ejecutar el instalador \textbf{Instalador - InverIoT - v2.2.exe}.

\section{Manual del usuario}

Una vez todo está instalado y configurado ya puedes interactuar con las diferentes partes del proyecto.

\subsection{Hardware}
Solo conectar la Raspberry Pi Pico a una fuente de energía y está operativo.

\begin{figure}[h]
\centering
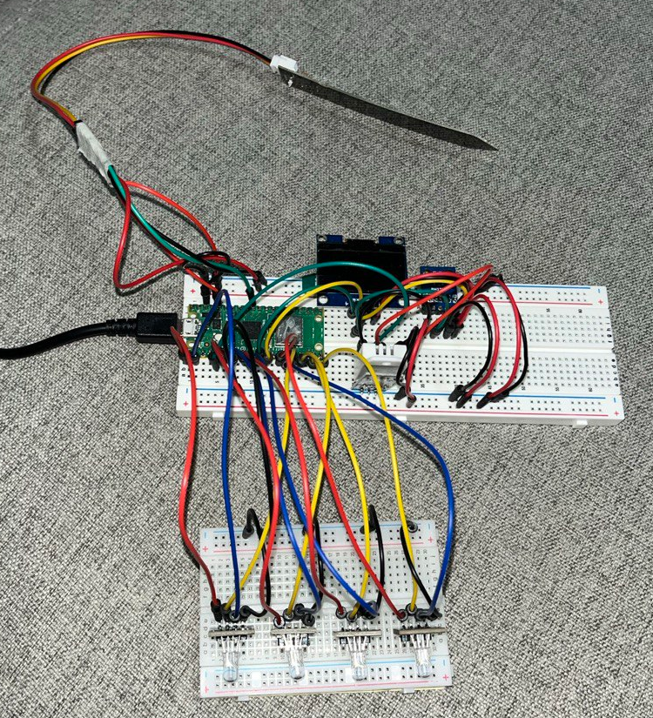
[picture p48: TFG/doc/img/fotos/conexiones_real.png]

\caption{Foto real de las conexiones.}
\end{figure}

Clavar el sensor de humedad de suelo en el punto que se desea monitorear.

\begin{figure}[h]
\centering

\caption{Sensor de humedad de suelo operativo.}
\end{figure}

Los valores en tiempo real se pueden ver en la pantalla oled con sus respectivas unidades.

\begin{figure}[h]
\centering

\caption{Pantalla oled mostrando los datos.}
\end{figure}

\subsection{InverIoT}

\begin{figure}[h]
\centering

\caption{Interfaz de la aplicación de escritorio.}
\end{figure}

La interfaz permite modificar los umbrales, tiene una comunicación bidireccional con la base de datos.

\begin{figure}[h]
\centering
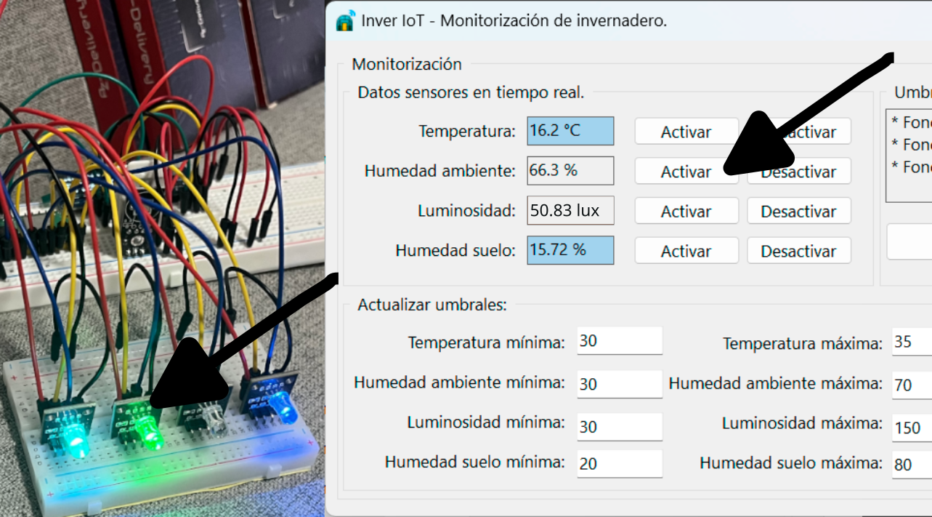
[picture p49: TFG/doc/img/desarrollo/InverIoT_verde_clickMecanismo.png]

\caption{Activación de mecanismo con un clic.}
\end{figure}

La activación del mecanismo está representado por el led verde prendido, pero si se desea activar otro mecanismo, solo desconectar del módulo led RGB el cable asociado al color verde, y conectarlo al mecanismo que se desea. Hacer esto solo si el nuevo mecanismo a activar es compatible en cuanto al voltaje necesario.

\begin{figure}[h]
\centering
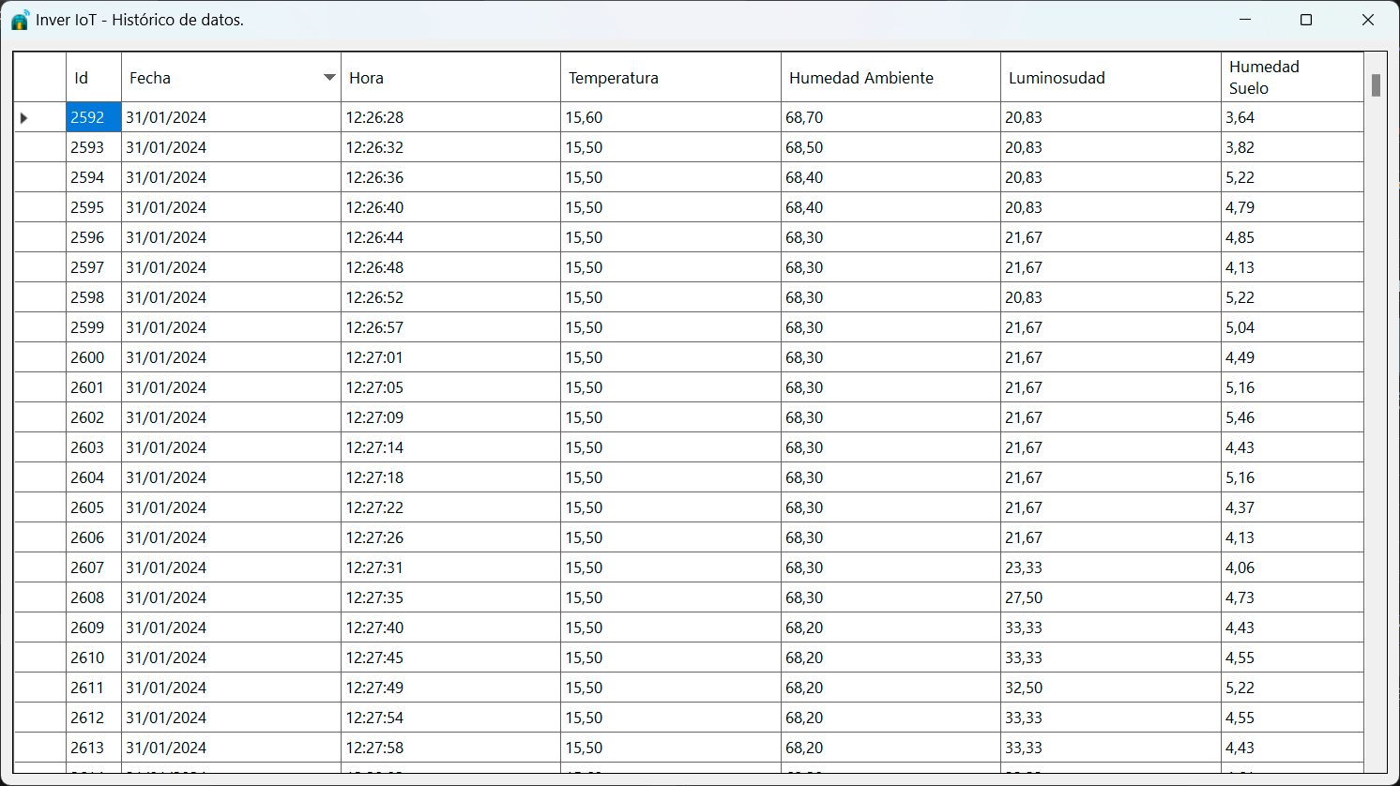
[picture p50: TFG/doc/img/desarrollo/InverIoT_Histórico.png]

\caption{Accesso al histórico de datos.}
\end{figure}

\begin{figure}[h]
\centering
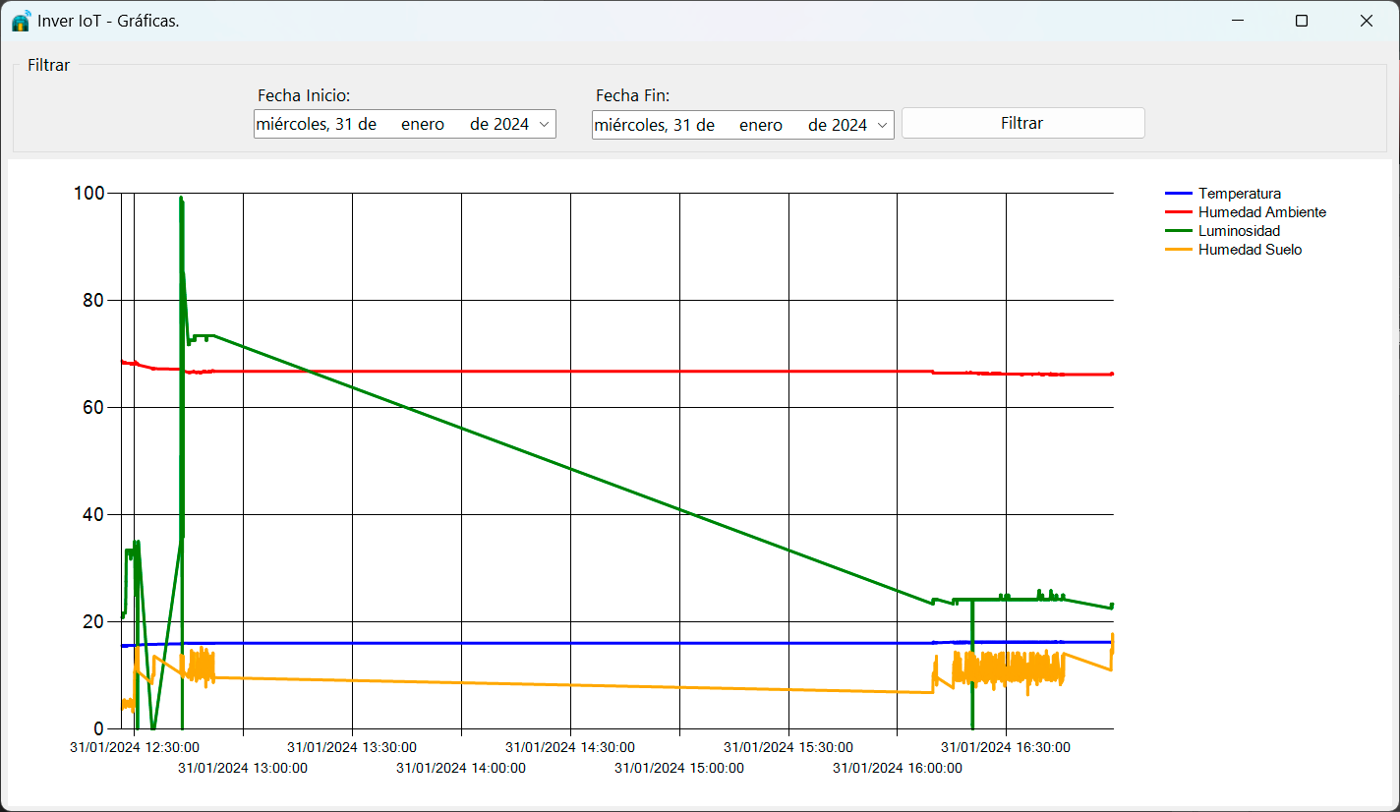
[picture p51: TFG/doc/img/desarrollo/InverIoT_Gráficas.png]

\caption{Capacidad de mostrar gráficas en un rango de fechas.}
\end{figure}

\subsection{dashboard}
Solo permite visualizar los datos, no envía comandos.

\begin{figure}[h]
\centering
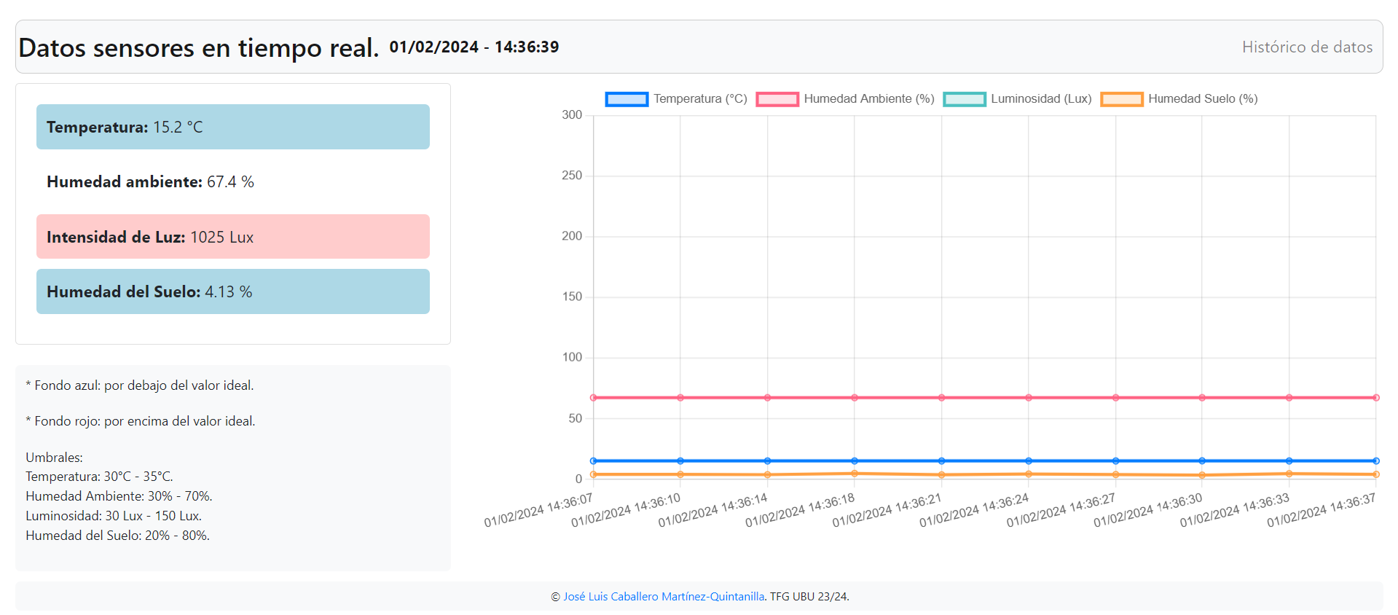
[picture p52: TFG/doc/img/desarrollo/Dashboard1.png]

\caption{El color rojo indica se ha sobrepasado el umbral.}
\end{figure}

\begin{figure}[h]
\centering

\caption{El color azul indica está por debajo del umbral.}
\end{figure}

\subsection{Bot de telegram}
Permite enviar comandos y recibir alertas.

\begin{figure}[h]
\centering
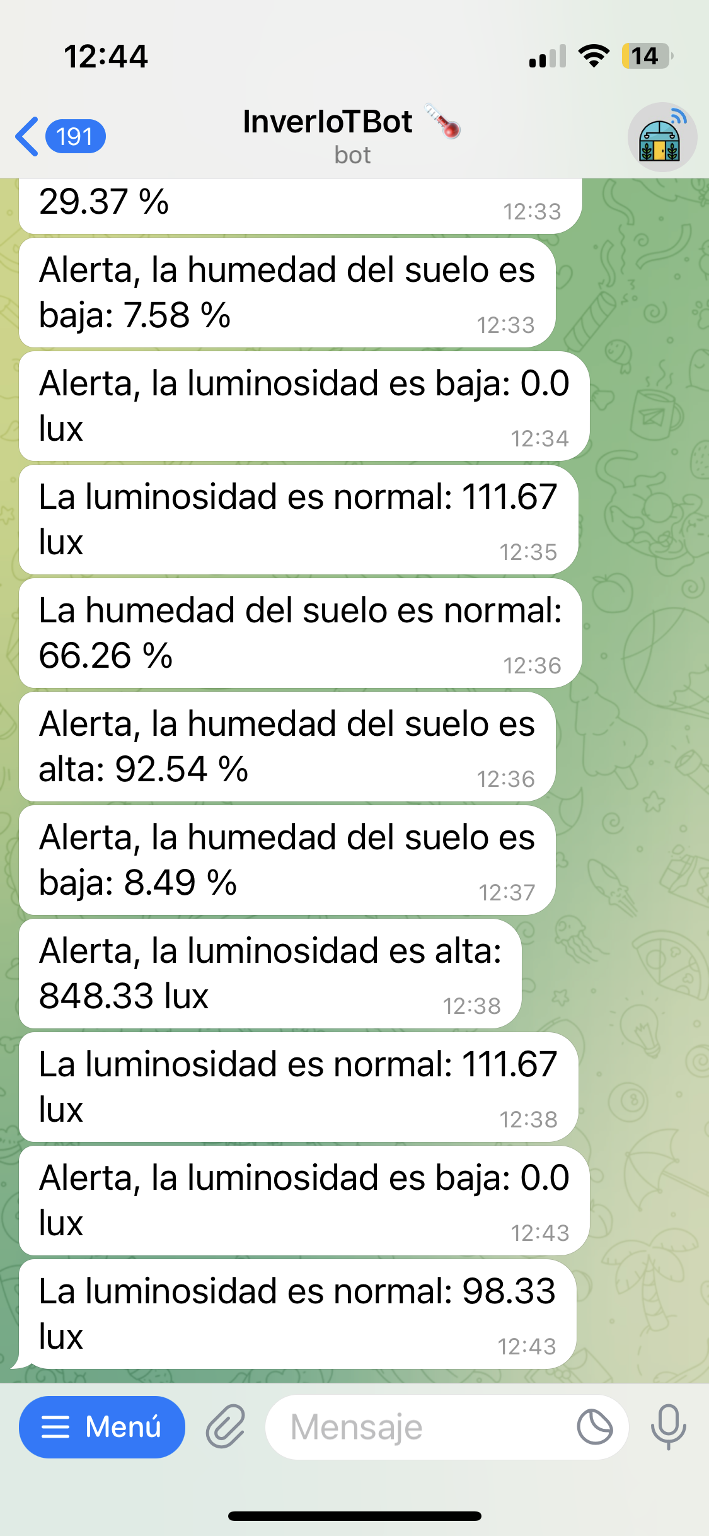
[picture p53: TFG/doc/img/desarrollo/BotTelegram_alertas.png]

\caption{Alertas recibidas por el bot de Telegram.}
\end{figure}

\begin{figure}[h]
\centering
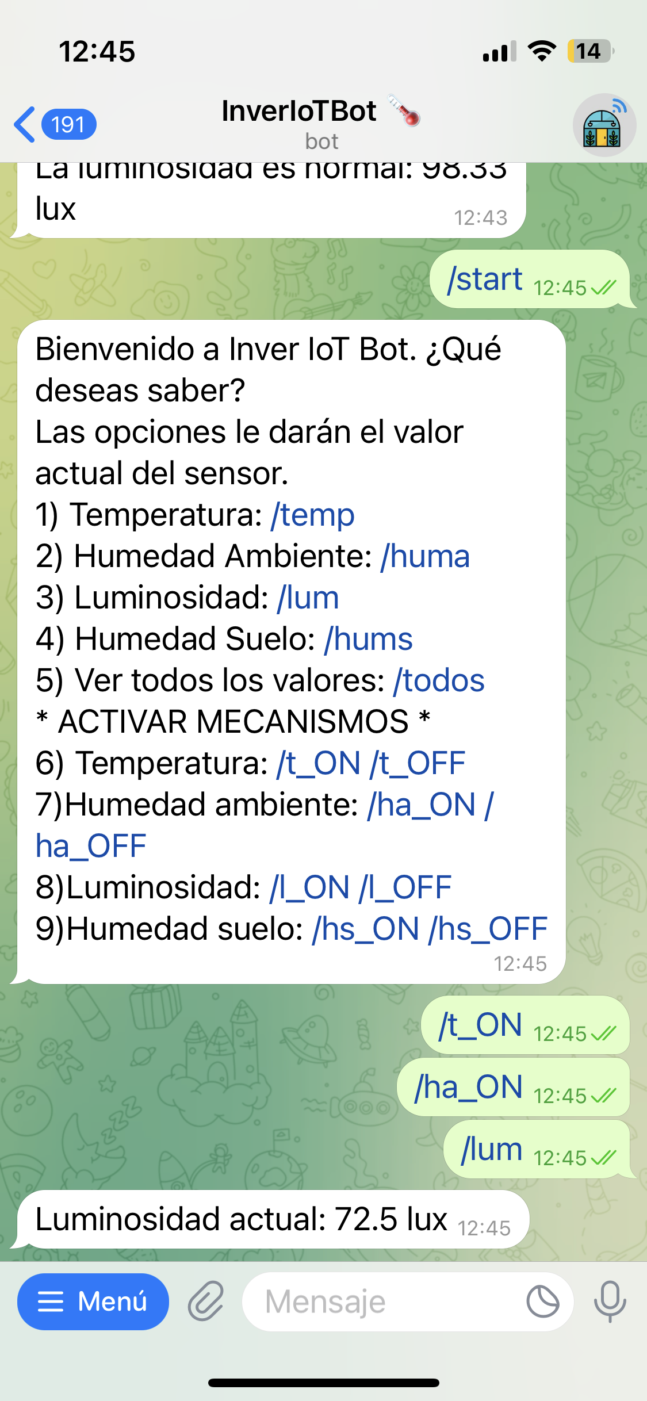
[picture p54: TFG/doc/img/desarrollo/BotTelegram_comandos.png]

\caption{Capacidad de enviar comandos desde Telegram.}
\end{figure}

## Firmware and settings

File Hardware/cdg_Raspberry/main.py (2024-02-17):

from machine import Pin, I2C, ADC, Pin  # Importa clases para manejar pines digitales, I2C, ADC (Convertidor Analógico a Digital) de la biblioteca 'machine'.
import dht  # Importa la biblioteca para manejar sensores DHT (sensores de temperatura y humedad).
import network, utelegram, utime, urequests, umqtt.simple as mqtt  # Importa varias bibliotecas para manejar red, un cliente Telegram, utilidades de tiempo, solicitudes HTTP y MQTT.
from bh1750 import BH1750  # Importa la clase BH1750 de la biblioteca bh1750 para manejar el sensor de luminosidad BH1750.
from sh1106 import SH1106_I2C  # Importa la clase SH1106_I2C para manejar la pantalla OLED SH1106 a través de I2C.
from config import utelegram_config, umbrales_sensores, mqtt_config  # Importa variables de configuración específicas (para Telegram y umbrales de sensores) desde un archivo de configuración 'config.py'.
import gc

# Declaración de umbrales y estados iniciales
umbrales = {
    'temperatura': {'min': TEMPERATURA_MINIMA, 'max': TEMPERATURA_MAXIMA},
    'humedad_ambiente': {'min': HUMEDAD_MINIMA, 'max': HUMEDAD_MAXIMA},
    'luminosidad': {'min': LUMINOSIDAD_MINIMA, 'max': LUMINOSIDAD_MAXIMA},
    'humedad_suelo': {'min': HUMEDAD_SUELO_MINIMA, 'max': HUMEDAD_SUELO_MAXIMA}
}

estados_sensores = {
    'temperatura': estado_temperatura,
    'humedad_ambiente': estado_humedad,
    'luminosidad': estado_luminosidad,
    'humedad_suelo': estado_humedad_suelo
}

# Diccionario de acciones de LED para cada sensor
led_actions = {
    "temperatura": {
        "alta": lambda: (temp_pin_led_rojo.high(), temp_pin_led_azul.low()),
        "baja": lambda: (temp_pin_led_rojo.low(), temp_pin_led_azul.high()),
        "normal": lambda: (temp_pin_led_rojo.low(), temp_pin_led_azul.low())
    },
    "humedad_ambiente": {
        "alta": lambda: (humambiente_pin_led_rojo.high(), humambiente_pin_led_azul.low()),
        "baja": lambda: (humambiente_pin_led_rojo.low(), humambiente_pin_led_azul.high()),
        "normal": lambda: (humambiente_pin_led_rojo.low(), humambiente_pin_led_azul.low())
    },
    "luminosidad": {
        "alta": lambda: (lum_pin_led_rojo.high(), lum_pin_led_azul.low()),
        "baja": lambda: (lum_pin_led_rojo.low(), lum_pin_led_azul.high()),
        "normal": lambda: (lum_pin_led_rojo.low(), lum_pin_led_azul.low())
    },
    "humedad_suelo": {
        "alta": lambda: (humsuelo_pin_led_rojo.high(), humsuelo_pin_led_azul.low()),
        "baja": lambda: (humsuelo_pin_led_rojo.low(), humsuelo_pin_led_azul.high()),
        "normal": lambda: (humsuelo_pin_led_rojo.low(), humsuelo_pin_led_azul.low())
    }
}

# Importar umbrales desde config.py
TEMPERATURA_MINIMA = umbrales_sensores['TEMPERATURA_MINIMA']  # Establece el umbral mínimo de temperatura a partir de la configuración importada de 'config.py'.
HUMEDAD_MINIMA = umbrales_sensores['HUMEDAD_MINIMA']  # Establece el umbral mínimo de humedad a partir de la configuración importada de 'config.py'.
LUMINOSIDAD_MINIMA = umbrales_sensores['LUMINOSIDAD_MINIMA']  # Establece el umbral mínimo de luminosidad a partir de la configuración importada de 'config.py'.
HUMEDAD_SUELO_MINIMA = umbrales_sensores['HUMEDAD_SUELO_MINIMA']  # Establece el umbral mínimo de humedad del suelo a partir de la configuración importada de 'config.py'.

TEMPERATURA_MAXIMA = umbrales_sensores['TEMPERATURA_MAXIMA']  # Establece el umbral máximo de temperatura a partir de la configuración importada de 'config.py'.
HUMEDAD_MAXIMA = umbrales_sensores['HUMEDAD_MAXIMA']  # Establece el umbral máximo de humedad a partir de la configuración importada de 'config.py'.
LUMINOSIDAD_MAXIMA = umbrales_sensores['LUMINOSIDAD_MAXIMA']  # Establece el umbral máximo de luminosidad a partir de la configuración importada de 'config.py'.
HUMEDAD_SUELO_MAXIMA = umbrales_sensores['HUMEDAD_SUELO_MAXIMA']  # Establece el umbral máximo de humedad del suelo a partir de la configuración importada de 'config.py'.

# Configuración del cliente MQTT
mqtt_server = mqtt_config['server']
mqtt_port = mqtt_config['port']
mqtt_topic_pub = mqtt_config['topic_pub']
mqtt_topic_sub = mqtt_config['topic_sub']

client_pub = mqtt.MQTTClient(mqtt_config['client_id_pub'], mqtt_server, mqtt_port)
client_sub = mqtt.MQTTClient(mqtt_config['client_id_sub'], mqtt_server, mqtt_port)

# Inicialización de sensores y dispositivos, pines
d = dht.DHT22(machine.Pin(3))  # Inicializar el sensor DHT22 en el pin 3. Este sensor mide la temperatura y humedad ambiental.
pin_salida_lamp = Pin(11, Pin.OUT)  # Configurar el pin 11 como salida para controlar una lámpara (u otro dispositivo).
pin_salida_riego = Pin(15, Pin.OUT)  # Configurar el pin 15 como salida para controlar un sistema de riego (u otro dispositivo).
i2c = I2C(0, scl=Pin(9), sda=Pin(8), freq=400000)  # Inicializar el bus I2C con el SCL en el pin 9, SDA en el pin 8 y una frecuencia de 400kHz.
oled = SH1106_I2C(128, 64, i2c)  # Inicializar una pantalla OLED SH1106 (128x64 píxeles) utilizando el bus I2C configurado anteriormente.
bh1750 = BH1750(0x23, i2c)  # Inicializar el sensor de luminosidad BH1750 con dirección I2C 0x23, usando el mismo bus I2C.
sensor_humedad_suelo = ADC(Pin(26))  # Inicializar un sensor de humedad del suelo en el pin analógico 26.
minima_humedad, maxima_humedad = 44698, 18324  # Establecer valores para la calibración de la lectura de humedad del suelo. Estos valores se usan para convertir la lectura analógica en porcentaje.

# Estados iniciales para cada sensores
estado_temperatura = "normal"
estado_humedad = "normal"
estado_luminosidad = "normal"
estado_humedad_suelo = "normal"

#### --- INICIO LEDS --- ###

# Inicialización de pines LED RGB de Temperatura
temp_pin_led_rojo = Pin(0, Pin.OUT)  # Rojo
temp_pin_led_azul = Pin(1, Pin.OUT)  # Azul

# Apagamos ambos al inicio
temp_pin_led_rojo.low()
temp_pin_led_azul.low()

# Inicialización de pines LED RGB de Humedad ambiente
humambiente_pin_led_rojo = Pin(4, Pin.OUT)  # Rojo
humambiente_pin_led_azul = Pin(5, Pin.OUT)  # Azul

# Apagamos ambos al inicio
humambiente_pin_led_rojo.low()
humambiente_pin_led_azul.low()

# Inicialización de pines LED RGB de Luminosidad
lum_pin_led_rojo = Pin(6, Pin.OUT)  # Rojo
lum_pin_led_azul = Pin(7, Pin.OUT)  # Azul

# Apagamos ambos al inicio
lum_pin_led_rojo.low()
lum_pin_led_azul.low()

# Inicialización de pines LED RGB de Humedad del suelo
humsuelo_pin_led_rojo = Pin(10, Pin.OUT)  # Rojo
humsuelo_pin_led_azul = Pin(11, Pin.OUT)  # Azul

# Apagamos ambos al inicio
humsuelo_pin_led_rojo.low()
humsuelo_pin_led_azul.low()

### INICIO LEDS VERDES ###
### Estos leds se encederán con una instrucción desde fuera
### En vez de activar un mecanismo, se activa la luz verde

temp_pin_led_verde = Pin(12, Pin.OUT)  # Verde
humambiente_pin_led_verde = Pin(13, Pin.OUT)  # Verde
lum_pin_led_verde = Pin(14, Pin.OUT)  # Verde
humsuelo_pin_led_verde = Pin(15, Pin.OUT)  # Verde

### --- FIN LEDS --- ###

# Configuración global
# send_interval = 1 # Intervalo de envío de mensajes en segundos, 900 son 15 minutos, lo pongo a 2 para probar
send_interval = 0.4 # Intervalo de envío de mensajes en segundos, 900 son 15 minutos, lo pongo a 2 para probar
next_send = utime.time() + send_interval

# Telegram API url.
API_URL = "https://api.telegram.org/bot" + utelegram_config['token']

def control_led(sensor, estado):
    # Ejecutar la acción correspondiente del LED basado en el sensor y estado.
    action = led_actions.get(sensor, {}).get(estado, lambda: None)
    action()

# Función para determinar el nuevo estado
def determinar_estado(sensor, valor):
    umbrales_sensor = umbrales[sensor]
    if valor > umbrales_sensor['max']:
        return 'alta'
    elif valor < umbrales_sensor['min']:
        return 'baja'
    else:
        return 'normal'

# Función refactorizada
def enviar_alertas_telegram(temp, hum, lux, porcentaje_humedad_suelo, bot):
    global estado_temperatura, estado_humedad, estado_luminosidad, estado_humedad_suelo

    valores_sensores = {
        'temperatura': temp,
        'humedad_ambiente': hum,
        'luminosidad': lux,
        'humedad_suelo': porcentaje_humedad_suelo
    }

    for sensor, valor in valores_sensores.items():
        nuevo_estado = determinar_estado(sensor, valor)
        if nuevo_estado != estados_sensores[sensor]:
            estados_sensores[sensor] = nuevo_estado
            control_led(sensor, nuevo_estado)
            mensaje = f"Alerta, {sensor.replace('_', ' ')} es {nuevo_estado}: {valor}" if nuevo_estado != "normal" else f"La {sensor.replace('_', ' ')} es {nuevo_estado}: {valor}"
            bot.send(utelegram_config['chat_id'], mensaje)

    # Actualizar los estados globales con los nuevos valores
    estado_temperatura, estado_humedad, estado_luminosidad, estado_humedad_suelo = estados_sensores['temperatura'], estados_sensores['humedad_ambiente'], estados_sensores['luminosidad'], estados_sensores['humedad_suelo']

def apagar_todo():
    # Iterar sobre cada LED definido para apagarlos.
    # Esto establece la salida de cada pin LED a 'bajo' (off).
    for led in [temp_pin_led_rojo, temp_pin_led_azul, temp_pin_led_verde, lum_pin_led_rojo, lum_pin_led_azul, lum_pin_led_verde, 
                humambiente_pin_led_rojo, humambiente_pin_led_azul, humambiente_pin_led_verde, 
                humsuelo_pin_led_rojo, humsuelo_pin_led_azul, humsuelo_pin_led_verde]:
        led.low()

    # Apagar la pantalla OLED para reducir el consumo de energía.
    oled.poweroff()

def mostrar_datos_oled(temp, hum, luz, hum_suelo):
    # Esta función muestra los datos de los sensores en la pantalla OLED.
    oled.fill(0)  # Limpia la pantalla OLED rellenándola con el color negro (0).

    oled.text("Datos sensores:", 0, 0)  # Muestra el texto "Datos sensores:" en la parte superior izquierda de la pantalla OLED (coordenadas 0,0).

    # Agregamos los símbolos y unidades a cada valor
    temp_text = f"Temp: {temp} 'C"  # Prepara el texto para mostrar la temperatura con el símbolo '°C'.
    hum_text = f"Hum Amb.: {hum} %"  # Prepara el texto para mostrar la humedad del ambiente con el símbolo '%'.
    luz_text = f"Luz: {luz} lux"  # Prepara el texto para mostrar la intensidad de luz en lux.
    hum_suelo_text = f"Hum Sue.: {hum_suelo} %"  # Prepara el texto para mostrar la humedad del suelo con el símbolo '%'.

    # Creamos una lista con los textos a mostrar
    texts = [temp_text, hum_text, luz_text, hum_suelo_text]  # Almacena todos los textos en una lista para iterar sobre ellos.

    # Mostramos cada texto en la pantalla OLED
    for i, text in enumerate(texts):
        # Itera sobre cada texto en la lista y los muestra en la pantalla OLED.
        # El índice 'i' se usa para colocar cada texto en una nueva línea en la pantalla.
        oled.text(text, 0, 10 * (i + 2))  # El texto se muestra a 10 píxeles de altura por cada línea, comenzando desde la línea 2 (debido a 'i + 2').
    
    oled.show()  # Actualiza la pantalla OLED para mostrar todos los textos agregados.


def read_message(bot, update_id):
    gc.collect()  # Intenta liberar memoria antes de realizar la operación
    try:
        url = f"{API_URL}/getUpdates?limit=1&offset={update_id}"
        response = urequests.get(url)
        data = response.json()  # Procesa la respuesta
        response.close()  # Asegura que la respuesta se cierra para liberar recursos
    except OSError as e:
        if e.args[0] == 12:  # ENOMEM
            print("Error: No hay suficiente memoria para leer el mensaje de Telegram.")
            gc.collect()  # Intenta liberar memoria después de un error
            return update_id, None
        print("Error de conexión al leer mensaje de Telegram:", e)
        return update_id, None
    except Exception as e:
        print("Error al leer mensaje de Telegram:", e)
        return update_id, None

    if 'result' in data and data['result']:
        update = data['result'][0]
        update_id = update['update_id'] + 1
        return update_id, update['message']
    else:
        return update_id, None

# Funciones del programa
def enviar(fecha, hora, temperatura, humedad, intensidad_luz, humedad_suelo):
    fecha_actual, hora_actual = obtener_fecha_hora()
    try:
        client_pub.connect()
        mensaje = f'{fecha_actual},{hora_actual},{temperatura},{humedad},{intensidad_luz},{humedad_suelo}'
        client_pub.publish(mqtt_topic_pub, mensaje.encode())
        client_pub.disconnect()
    except OSError as e:
        if e.args[0] == 104:  # ECONNRESET
            print("Error de conexión MQTT: El servidor ha cerrado la conexión.")
        elif e.args[0] == 110:  # ETIMEDOUT
            print("Error de conexión MQTT: Tiempo de espera agotado.")
        else:
            print(f"Error de conexión MQTT: {e}")
    except Exception as e:
        print(f"Error inesperado al enviar datos por MQTT: {e}")

# Obtener fecha actual
def obtener_fecha_hora():
    try:
        response = urequests.get('http://worldtimeapi.org/api/ip')
        if response.status_code == 200:
            datetime = response.json()['datetime'].split('T')
            return datetime[0], datetime[1].split('.')[0]
        else:
            print("Error al obtener fecha y hora: código de estado HTTP", response.status_code)
            return None, None
    except Exception as e:
        print("Error al obtener fecha y hora:", e)
        return None, None

def handle_mqtt_messages(topic, msg):
    # Esta función es un 'callback' que se ejecuta cuando se recibe un mensaje MQTT, dependiendo lo que reciba, hago una cosa u otra.
    mensaje = msg.decode().lstrip()  # Decodifica el mensaje MQTT (que se recibe en bytes) a una cadena de texto y elimina los espacios al principio.
    print("Mensaje MQTT recibido:", mensaje)  # Imprime el mensaje MQTT recibido en la consola.
    
    # Aquí es donde funciona la lógica de los mensajes recibidos por mqtt
    if mensaje == "/t_ON":
        # Se enciende el led (podría ser un mecanismo, como activar ventilador, abrir ventana...)
        temp_pin_led_verde.high()        
    elif mensaje == "/t_OFF":
        # Si el comando recibido es "/todos", envía todos los valores actuales de los sensores al usuario.humambiente_pin_led_green.low()
        temp_pin_led_verde.low()
    elif mensaje == "/ha_ON":
        # Si el comando recibido es "/todos", envía todos los valores actuales de los sensores al usuario.
        humambiente_pin_led_verde.high()
    elif mensaje == "/ha_OFF":
        # Si el comando recibido es "/todos", envía todos los valores actuales de los sensores al usuario.humambiente_pin_led_green.low()
        humambiente_pin_led_verde.low()
    elif mensaje == "/l_ON":
        # Si el comando recibido es "/todos", envía todos los valores actuales de los sensores al usuario.
        lum_pin_led_verde.high()
    elif mensaje == "/l_OFF":
        # Si el comando recibido es "/todos", envía todos los valores actuales de los sensores al usuario.humambiente_pin_led_green.low()
        lum_pin_led_verde.low()
    elif mensaje == "/hs_ON":
        # Si el comando recibido es "/todos", envía todos los valores actuales de los sensores al usuario.
        humsuelo_pin_led_verde.high()
    elif mensaje == "/hs_OFF":
        # Si el comando recibido es "/todos", envía todos los valores actuales de los sensores al usuario.humambiente_pin_led_green.low()
        humsuelo_pin_led_verde.low()
    else:
        # Si el comando recibido no se reconoce, envía un mensaje indicando que el comando no es reconocido.
        print("Comando no reconocido.")

def manage_sending(next_send):
    # Esta función gestiona el envío de alertas y datos a través de Telegram y MQTT.

    # Llama a la función enviar_alertas_telegram para verificar si los valores actuales de los sensores están fuera de los umbrales definidos y, en caso afirmativo, enviar alertas a Telegram.
    enviar_alertas_telegram(temp, hum, lux, porcentaje_humedad_suelo, bot)

    # Llama a la función enviar para publicar los datos actuales de los sensores a través de MQTT.
    # Aquí se pasan valores vacíos para fecha y hora ya que estos se obtienen dentro de la función.
    enviar("", "", temp, hum, lux, porcentaje_humedad_suelo)

    # Actualiza el momento en el que se debe realizar el próximo envío de datos.
    # Se suma el intervalo de envío a la hora actual para programar el próximo envío.
    next_send = utime.time() + send_interval

    return next_send  # Devuelve el nuevo valor de next_send

def send_message(chat_id, message):
    # Esta función se utiliza para enviar mensajes a través del bot de Telegram.

    try:
        # Primero, se reemplazan los espacios y saltos de línea en el mensaje para codificarlo correctamente en la URL.
        # Los espacios (' ') se convierten en '%20' y los saltos de línea ('\n') en '%0A'.
        encoded_message = message.replace(' ', '%20').replace('\n', '%0A')

        # Se construye la URL para la API de Telegram utilizando el chat_id y el mensaje codificado.
        # API_URL es una variable global que contiene la URL base de la API de Telegram para el bot.
        url = f"{API_URL}/sendMessage?chat_id={chat_id}&text={encoded_message}"

        # Se envía la solicitud GET a la URL de la API de Telegram.
        urequests.get(url)

    except Exception as e:
        # Si ocurre un error durante el envío del mensaje, se imprime un mensaje de error.
        print("Error al enviar mensaje a Telegram:", e)

def handle_telegram_commands(chat_id, text):
    # Esta función gestiona los comandos recibidos a través de Telegram.

    if text == "/start":
        # Si el comando recibido es "/start", envía un mensaje de bienvenida al usuario con una lista de comandos disponibles.
        send_message(chat_id, "Bienvenido a Inver IoT Bot. ¿Qué deseas saber?\nLas opciones le darán el valor actual del sensor.\n1) Temperatura: /temp\n2) Humedad Ambiente: /huma\n3) Luminosidad: /lum\n4) Humedad Suelo: /hums\n5) Ver todos los valores: /todos\n* ACTIVAR MECANISMOS *\n6) Temperatura: /t_ON /t_OFF\n7)Humedad ambiente: /ha_ON /ha_OFF\n8)Luminosidad: /l_ON /l_OFF\n9)Humedad suelo: /hs_ON /hs_OFF")
    
    elif text == "/temp":
        # Si el comando recibido es "/temp", envía el valor actual de la temperatura al usuario.
        send_message(chat_id, f"Temperatura actual: {temp} °C")
    
    elif text == "/huma":
        # Si el comando recibido es "/huma", envía el valor actual de la humedad ambiente al usuario.
        send_message(chat_id, f"Humedad ambiente: {hum} %")
    
    elif text == "/lum":
        # Si el comando recibido es "/lum", envía el valor actual de la luminosidad al usuario.
        send_message(chat_id, f"Luminosidad actual: {lux} lux")
    
    elif text == "/hums":
        # Si el comando recibido es "/hums", envía el valor actual de la humedad del suelo al usuario.
        send_message(chat_id, f"Humedad del suelo: {porcentaje_humedad_suelo} %")
    
    elif text == "/todos":
        # Si el comando recibido es "/todos", envía todos los valores actuales de los sensores al usuario.
        send_message(chat_id, f"Temperatura actual: {temp} °C\nHumedad Ambiente: {hum} %\nLuminosidad: {lux} lux\nHumedad del suelo: {porcentaje_humedad_suelo} %")
    elif text == "/t_ON":
        # Si el comando recibido es "/todos", envía todos los valores actuales de los sensores al usuario.
        temp_pin_led_verde.high()
    elif text == "/t_OFF":
        # Si el comando recibido es "/todos", envía todos los valores actuales de los sensores al usuario.humambiente_pin_led_green.low()
        temp_pin_led_verde.low()
    elif text == "/ha_ON":
        # Si el comando recibido es "/todos", envía todos los valores actuales de los sensores al usuario.
        humambiente_pin_led_verde.high()
    elif text == "/ha_OFF":
        # Si el comando recibido es "/todos", envía todos los valores actuales de los sensores al usuario.humambiente_pin_led_green.low()
        humambiente_pin_led_verde.low()
    elif text == "/l_ON":
        # Si el comando recibido es "/todos", envía todos los valores actuales de los sensores al usuario.
        lum_pin_led_verde.high()
    elif text == "/l_OFF":
        # Si el comando recibido es "/todos", envía todos los valores actuales de los sensores al usuario.humambiente_pin_led_green.low()
        lum_pin_led_verde.low()
    elif text == "/hs_ON":
        # Si el comando recibido es "/todos", envía todos los valores actuales de los sensores al usuario.
        humsuelo_pin_led_verde.high()
    elif text == "/hs_OFF":
        # Si el comando recibido es "/todos", envía todos los valores actuales de los sensores al usuario.humambiente_pin_led_green.low()
        humsuelo_pin_led_verde.low()
    else:
        # Si el comando recibido no se reconoce, envía un mensaje indicando que el comando no es reconocido.
        send_message(chat_id, "Comando no reconocido.")
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

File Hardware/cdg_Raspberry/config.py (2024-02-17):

# Diccionario de configuración para la conexión WiFi
wifi_config = {
    'ssid':'xxx', # El SSID (nombre) de la red WiFi a la que se conectará el dispositivo
    'p':'xxx' # La contraseña de la red WiFi
}

# Diccionario de configuración para el bot de Telegram
utelegram_config = {
    'token': 'xxx', # El token del bot de Telegram.
    'chat_id': 'xxx' # El ID del chat en Telegram donde el bot enviará y recibirá mensajes.
}

# Diccionario de configuración para los umbrales de los sensores
umbrales_sensores = {
    'TEMPERATURA_MINIMA': 30,
    'HUMEDAD_MINIMA': 30,
    'LUMINOSIDAD_MINIMA': 30,
    'HUMEDAD_SUELO_MINIMA': 20,
    'TEMPERATURA_MAXIMA': 35,
    'HUMEDAD_MAXIMA': 70,
    'LUMINOSIDAD_MAXIMA': 150,
    'HUMEDAD_SUELO_MAXIMA': 80
}

# Configuración MQTT
mqtt_config = {
    'server': 'xxx', # ip del servidor
    'port': xxxx, # puerto del servidor
    'topic_pub': 'invernadero/sensores',
    'topic_sub': 'invernadero/ordenes',
    'client_id_pub': 'TFG_UBU_mqtt_id_pub',
    'client_id_sub': 'TFG_UBU_mqtt_id_sub'
}

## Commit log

2024-01-22 Librerias para el hardware
2024-01-23 actualizando diagrama de conexiones
2024-01-23 fritzing: conexiones
    [BH1750.fzz, DHT22_humedad_temperatura.fzz, Sensor_humedad_suelo.fzz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]
2024-01-23 imágenes de componentes y conexiones individuales
    [DHT22_humedad_temperatura.fzz]
2024-01-23 corrección imagen de Raspberry Pi Pico W
2024-01-23 Cambio DHT11 por DHT22 para mayor precisión
2024-01-25 Agregando MQ-135 Sensor de Calidad del aire
    [MQ-135.fzz, conexiones.fzz]
2024-01-26 activar actualizacion valor de sensor de calidad del aire MQ-135
2024-01-27 Agregando batería li-ion
    [bateria_li_ion.fzz, conexiones.fzz]
2024-01-27 modificación clase de sensor de humedad de suelo
2024-01-29 Create Readme.md
    Creación de aplicación winforms para monitorizar valores.
2024-01-29 creando carpeta micropython para ubicar el código correspondiente
2024-01-30 Ubicación de carpeta micropython
2024-01-31 actualización de esquema de conexiones
    [.conexiones-respaldo1.fzz, MQ-135.fzz, bateria_li_ion.fzz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]
2024-01-31 corrección de nombre identificador de los leds
    [conexiones.fzz, leds_rgb.fzz]
2024-02-02 coloco librería umqtt en carpeta lib para mayor orden y corrección en main.py
2024-02-03 Subido archivo de audio creado con IA
    Iker Jiménez dando paso a la presentación de mi TFG,
2024-02-03 Delete Presentación_IA_Iker_Jiménez.mp3
    Eliminado audio, está solo la voz, falta la música de Pink Floyd de fondo.
2024-02-03 Presentación del TFG por Iker Jiménez (IA)
    Nada mejor que el gran Iker Jiménez dando paso a la presentación de mi TFG.
    Creado con IA.
2024-02-03 Update README.md
    Añadida la dirección web para acceder al dashboard.
    Si la placa no está conectada no se van a recibir datos en tiempo real, como es normal, pero se pueden consultar datos históricos, ya que están guardados en basde de datos mySQL.
2024-02-03 Update README.md
    Añadido texto que informa sobre la subida del archivo de audio de presentación por Iker Jiménez (IA).
2024-02-05 Análisis de datos
    [data.csv]
2024-02-05 Update README.md
    Mínima corrección de ortografía.
2024-02-06 explicación del coeficiente de determinación
2024-02-07 Update dht.py
    Cambiado el error genérico "raise Exception("checksum error")" por uno más específico.
    Recomendado por sonarcloud.io
2024-02-07 Update umqtt.py
    Eliminada línea comentada que no servía para nada, recomendado por sonarcloud.io
2024-02-07 Update umqtt.py
    Eliminado if innecesario, recomendado por sonarcloud.io
2024-02-08 Update utelegram.py
    Eliminadas funciones que no se usan.
2024-02-08 Update main.py
    Actualizada función def manage_sending(next_send): devolviendo el valor de la variable actualizada.
2024-02-08 Update main.py
    Modificada variable de local a global (next_send), recomendado por: sonarcloud.io
2024-02-08 Update README.md
    Añadido la comprobación de código de sonarcloud.io
    Status Passed.
2024-02-10 Arreglado algunos signos de puntuación.
2024-02-11 TFG: agregando imágenes de conexiones con panel solar y power bank
2024-02-11 Update README.md Añadido video presentación
    Se ha añadido el vídeo de presentación final.
2024-02-12 Create Readme.md Firmware y reset
    Se crea carpeta con los archivos para resetear de fábrica. y para preparar la Raspberry para trabajar con micropython.
    Ya que me ha hecho falta, lo dejo subido.
2024-02-12 Add files via upload
    Descargados de:
    https://micropython.org/download/RPI_PICO_W/
    https://electrocredible.com/how-to-reset-raspberry-pi-pico-w/
2024-02-12 Update Readme.md
    Añadida descripción de lo que se ha subido y webs de descarga.
2024-02-12 Update README.md Añadido vídeo demo funcional
    Añadida la URL a youtube del video con una demostración funcional.
2024-02-12 Hardware: Modularización de código
2024-02-13 Hardware: corrección en uso de variable next_send
2024-02-13 Hardware: Corrección de librería utelegram.py
2024-02-13 Hardware: cambio de key en diccionario
2024-02-13 TFG: diagramas de InverIoT y dashboard
2024-02-13 TFG: Actualización de diagramas
2024-02-14 Update README.md Actualizada descripción
    Se ha actualizado la descripción inicial, añadiendo el bot de telegram y la app winforms.
2024-02-15 TFG:anexos: Plan de proyecto software
2024-02-16 Subido código original de RaspBerry
    Se sube el código original usado en las pruebas de los vídeos y el que se va a usar para la defensa.
2024-02-16 Create micropython_optimizado
    Renombrada carpeta con el código de la RaspBerry optimizado. Las pruebas y vídeos se realizaron sobre el código de la carpeta cdg_Raspberry.
2024-02-16 eliminacion de .anexos.tex.swp
2024-02-17 Eliminado cdg duplicado por error
    Eliminado carpeta duplicada por error.
    [boot.py, config.py, main.py]
2024-02-17 Update README.md
    Eliminado carpeta de cdg. duplicado.
